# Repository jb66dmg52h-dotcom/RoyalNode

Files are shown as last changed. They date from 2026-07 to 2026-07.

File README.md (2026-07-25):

# RoyalNode / 2Watt Project

RoyalNode, also tracked as the 2Watt Project, is a solar-powered 915 MHz LoRa repeater carrier built around the Seeed Studio XIAO nRF52840 and EBYTE E22-900M33S high-power radio module.

> **Status:** Rev A KiCad schematic and PCB placement scaffold are active. The board is not fabrication ready.

## Locked architecture

- Standard Seeed Studio XIAO nRF52840, socketed
- EBYTE E22-900M33S radio module
- Protected 1S 3.6/3.7 V Li-ion/LiPo pack, 10-20 Ah class
- Board-mounted XT30 battery connector
- Board-mounted XT30 solar connector
- BQ25798 buck-boost charger with MPPT and power path
- Battery-mounted Semitec 103AT-2 NTC connected to BQ25798 TS network
- TPS61088 5 V boost rail for the E22
- Battery voltage and charger telemetry read directly from the BQ25798
- XIAO powered through its underside BAT and GND pads using a two-wire JST-GH lead
- LM66100 ideal diode between the main battery/system node and the XIAO BAT lead
- USB-C firmware updates through the XIAO
- USB-C battery charging through the BQ25798
- One external charge LED
- Optional MeshCore-supported BME680 environmental I2C port
- Direct controlled-impedance RF path from E22 ANT to board-edge SMA
- XIAO-controlled TPS61088 enable for radio power sequencing
- 4-layer controlled-impedance PCB

## Solar guidance

- 6 V class panel
- 20 W target for permanent deployment
- BQ25798 must be configured and validated against the selected panel's actual Vmp, Voc and Imp
- Installer must verify Vmp, Voc, Imp and cold-weather Voc

## Removed from Rev A

- MAX17048 fuel gauge and battery percentage estimation
- Power button
- eFuse
- Radio load switch
- Pogo pins
- SWD connector
- Multi-wire XIAO harness
- Extra LEDs beyond the charge LED
- Solar/USB-present telemetry
- Battery reverse-polarity circuit
- Radio-disable jumper
- Display, GPS and non-MeshCore accessory sensors
- Bench-test jumpers, simulated-temperature bypass networks and mode-selection test footprints

## Power summary

- Battery: protected 1S 3.6/3.7 V nominal, 4.20 V maximum, 10-20 Ah class
- Battery discharge capability: at least 5 A continuous, 8 A transient preferred
- Maximum charge current: 2 A
- Charge temperature sensing: battery-mounted 10 kOhm NTC; target policy suspends charging below 0 C and at/above 45 C
- Battery telemetry: BQ25798 battery voltage and charger-state measurements; no dedicated SOC fuel gauge in Rev A
- E22 rail: 5.0 V nominal
- TPS61088 rail design target: 2 A continuous
- TPS61088 inductor: Coilcraft XAL7030-222MEC, 2.2 uH
- BQ25798 inductor: Coilcraft XAL7070-222MEC, 2.2 uH
- E22 local bulk capacitance: 330-470 uF plus ceramics

## Canonical documents

- `docs/DESIGN_FREEZE_REV_A.md`
- `docs/CURRENT_STATUS_REV_A.md`
- `docs/WIRING_BLUEPRINT.md`
- `docs/ELECTRICAL_DESIGN_REV_A.md`
- `docs/LOCKED_COMPONENTS_REV_A.md`
- `docs/FINAL_POWER_CALCULATIONS_REV_A.md`
- `docs/SOLAR_DESIGN_GUIDE_REV_A.md`
- `docs/PCB_NET_CLASSES_REV_A.md`

Earlier concept documents are superseded where they conflict with the design-freeze document.

## Repository layout

```text
2Watt-Project/
├── docs/              Engineering specifications and calculations
├── hardware/          KiCad project, symbols, footprints and fabrication files
├── firmware/          Board support and hardware test firmware
├── bom/               Manufacturing and sourcing files
├── production/        Assembly and manufacturing outputs
└── test/              Bring-up procedures and measurements
```

## Local KiCad project

Open the Mac/KiCad project here:

```text
hardware/kicad/RoyalNode/RoyalNode.kicad_pro
```

Useful local checks:

```bash
make validate
make kicad-checks
```

## Remaining work

1. Resolve or formally accept the E22 footprint-library warning through the manufacturing review path.
2. Unblock the Molex edge-launch SMA footprint and final 50-ohm GCPW geometry.
3. Confirm XIAO socket orientation, XT30 polarity and connector mating clearance.
4. Refine power-stage placement from the generated ratsnest.
5. Route the PCB.
6. Run DRC, ERC, JLCPCB DFM and PCBA review.
7. Order Rev A prototypes for production validation.

## Safety and regulatory note

The radio hardware may be capable of approximately 33 dBm output. Deployed settings must comply with applicable conducted-power, antenna-gain, EIRP, bandwidth and certification requirements. The battery pack must include suitable internal protection, and deployment must respect the battery manufacturer's permitted charging-temperature range.

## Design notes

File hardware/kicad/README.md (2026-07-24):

# RoyalNode KiCad Workspace

This folder contains the Git-tracked KiCad design for RoyalNode Rev A.

Open the project file:

```text
hardware/kicad/RoyalNode/RoyalNode.kicad_pro
```

Current status:

- KiCad 10.0 project scaffold created.
- Root schematic is intentionally a capture placeholder.
- PCB file contains the Rev A board outline, placement zones, RF corridor, and keepout notes.
- Project-local symbols have been started in `RoyalNode/lib_symbols/RoyalNode.kicad_sym`.
- Footprint release is controlled by `RoyalNode/lib_footprints/FOOTPRINT_RELEASE_MATRIX_REV_A.md`.
- Schematic capture should follow `RoyalNode/SCHEMATIC_CAPTURE_SEED_REV_A.csv`.
- Footprints, schematic nets, and routed copper still need to be captured from `docs/DESIGN_FREEZE_REV_A.md` and `docs/NET_MAP_REV_A.md`.

Design source of truth:

- `docs/DESIGN_FREEZE_REV_A.md`
- `docs/REFERENCE_DESIGNATORS_REV_A.md`
- `docs/NET_MAP_REV_A.md`
- `docs/PIN_AUDIT_REV_A.md`
- `docs/RF_DESIGN_REV_A.md`
- `docs/FOOTPRINT_SOURCE_LINKS_REV_A.md`
- `bom/REV_A_LOCKED_CORE_BOM.csv`
- `bom/REV_A_LOCKED_PASSIVES.csv`

Validation:

```bash
python3 tools/validate_royalnode.py
```

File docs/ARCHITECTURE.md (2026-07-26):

# RoyalNode Rev A System Architecture

## Proposed block diagram

```text
6 V / 20 W solar panel
          |
  XT30, fuse, reverse protection,
  TVS and input filtering
          |
  BQ25798 1S solar/USB charger
          |
  1S 15 Ah protected Li-ion battery
          |
      XT30 + main fuse
          |
          +-------------------------------+
          |                               |
 TPS61088 5.0 V radio boost       low-noise MCU supply
          |                               |
 EBYTE E22-900M33S                Seeed XIAO nRF52840
          |                               |
 50-ohm PCB trace to SMA          optional 4-pin JST-GH
                                  BME680 environmental
```

## Major subsystems

### Solar and charger subsystem

RoyalNode uses a one-cell charger architecture around the BQ25798RQMR charger and power-path controller.

The locked Rev A charger is BQ25798RQMR configured for one Li-ion cell. It provides the charger, power-path behavior, I2C configuration, charger telemetry and input-source handling used by the current KiCad schematic.

For a 6 V nominal panel, firmware and charger configuration must be validated against the actual panel maximum-power voltage/current rather than the printed nominal voltage alone.

Initial charging target:

- 1S Li-ion charge voltage: 4.20 V
- maximum charge current: approximately 2.0–2.5 A
- panel maximum-power current: approximately 3.3 A
- battery NTC charge-temperature protection enabled

### Battery subsystem

Target pack: protected 1S 15 Ah lithium-ion pack with a pack-mounted NTC.

The pack no longer needs cell balancing because all parallel cells operate as one series group. It still requires:

- over-charge protection
- over-discharge protection
- over-current and short-circuit protection
- at least 5 A continuous discharge capability
- transient capability above 5 A
- a main fuse near the XT30 connection

At a 6 W radio load and approximately 85–90% boost efficiency, the battery may supply roughly 1.6 A at 4.2 V and approximately 2.2–2.6 A near the low end of the allowed battery range. Copper, fuse, protection FETs and wiring are sized with substantial margin.

### Radio power subsystem

TPS61088 remains the preferred converter. It is suitable for single-cell lithium input and provides the switch-current capability required to create a stiff 5.0 V radio rail.

Required design targets:

- input range: approximately 3.0–4.2 V
- output: 5.0 V
- continuous output design target: 3 A
- programmed soft start
- controlled enable from the XIAO
- low-ESR local bulk and ceramic capacitance at the EBYTE supply
- hardware protection against abnormal output over-voltage

No current-shunt footprints, dedicated test pads or measurement links are included.

### MCU subsystem

The Seeed XIAO nRF52840 remains socketed on Rev A. It handles the SPI radio interface, boost enable and radio sequencing, battery telemetry, optional environmental telemetry, fault logging and the MeshCore hardware abstraction layer.

The XIAO must not use its onboard battery charger as the system charger. The BQ25798 charger path is the controlled battery-charging path. Programming uses the XIAO USB-C port; recovery uses SWD pads or Tag-Connect.

### Battery telemetry

Rev A omits a dedicated MAX17048 fuel gauge. Battery voltage and charger state are read from the BQ25798 over I2C. Firmware may later add an ADC cross-check if needed, but it is not part of the current KiCad capture.

### Radio and RF subsystem

The EBYTE E22-900M33S contains an SX1262-family transceiver and external high-power RF front end. Integration requires validated control of reset, BUSY, DIO1, RXEN, TXEN or DIO2 RF-switch control, and DIO3 TCXO behavior.

The board-mounted SMA is connected to EBYTE ANT pin 21 through a short 50-ohm controlled-impedance grounded coplanar waveguide. The module's alternate U.FL/I-PEX path must not be used simultaneously.

## MeshCore telemetry architecture

### Required

- battery voltage or state of charge
- MCU internal temperature where supported

### Optional

- BME680 temperature, humidity and pressure over one 4-pin JST-GH I2C connector

### Omitted

- solar current telemetry
- radio current telemetry
- battery current telemetry
- external PA or regulator temperature telemetry
- fan sensing or control
- generic accessory ports
- GPS hardware for a fixed repeater

## Parts changed by the 2S-to-1S conversion

### Removed or replaced

- 2S charger configuration: replaced by 1S BQ25798 configuration
- 2S 15 Ah battery pack: replaced by protected 1S 15 Ah pack
- 2S BMS and balancing function: replaced by 1S protection circuit
- any 2S voltage-divider values: recalculated for 1S
- any 2S fuel-gauge choice: removed from Rev A
- 2S low-voltage firmware thresholds: replaced by 1S thresholds

### Retained

- TPS61088 radio boost converter
- 5.0 V / 3 A radio-rail target
- Seeed XIAO nRF52840
- EBYTE E22-900M33S
- XT30 battery and solar connectors
- optional BME680 JST-GH connector
- PCB-mounted edge-launch SMA
- four-layer PCB and two-ounce outer copper preference

### Recalculation required during schematic capture

- BQ25798 1S charger configuration
- BQ25798 input-current and charge-current limits
- BQ25798 input-selector MOSFET ratings and gate behavior
- BQ25798 inductor current and saturation rating
- TPS61088 inductor, current limit, compensation and thermal design
- battery fuse rating
- 1S protection MOSFET resistance and trip threshold
- low-battery firmware thresholds
- BQ25798 telemetry integration in firmware

## Connector architecture

- Battery: XT30
- Solar: XT30
- Optional environmental sensor: 4-pin JST-GH
- Antenna: PCB-mounted edge-launch SMA
- Programming: XIAO USB-C
- Recovery/debug: Tag-Connect or SWD pads
- Mounting: four M3 non-plated corner holes

## Design philosophy

Rev A is deployment-focused. It omits bench-only test points and current shunts. Necessary EBYTE configuration resistors may remain where required for signal-routing flexibility. The XIAO and EBYTE modules remain serviceable.

## Current open decisions

1. Select exact 6 V / 20 W panel and confirm its Vmp and Voc.
2. Complete BQ25798 charger configuration and component review.
3. Complete TPS61088 1S-to-5 V power-stage calculations.
4. Select exact protected 1S 15 Ah battery pack and NTC specification.
5. Select hardware radio-rail over-voltage protection.
6. Verify exact E22 footprint, antenna-path selection and RF pin mapping.
7. Implement MeshCore driver changes required for the external PA and RF switch.
8. Confirm BQ25798 battery/charger telemetry integration.
9. Confirm BME680 support in the selected MeshCore repeater build.
10. Finalize enclosure, vent and cable-gland selections.
11. Finalize legal transmit-power configuration for Canadian deployment.

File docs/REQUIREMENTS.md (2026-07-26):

# RoyalNode Rev A Requirements

## 1. Mission

RoyalNode Rev A is an engineering-validation platform for a rugged, solar-powered 915 MHz LoRa repeater using a Seeed XIAO nRF52840 and an EBYTE E22-900M33S radio module.

## 2. Functional requirements

- Operate as a continuously available LoRa repeater.
- Support the E22-900M33S SPI interface and external RF-control behavior.
- Support firmware-controlled radio power, reset and receive/transmit control.
- Expose only telemetry that can be reported through the MeshCore ecosystem.
- Permit safe reduced-power operation when battery charge or temperature is outside preferred limits.
- Do not include dedicated electrical test points, current-shunt footprints, removable measurement links or bench-only instrumentation hardware.

## 3. Power requirements

- Primary energy source: 6 V class, 20 W monocrystalline panel.
- Panel maximum-power current target: approximately 3.3 A or less.
- Panel open-circuit voltage must remain within the selected charger's absolute maximum input rating.
- Energy storage: protected 1S Li-ion battery pack, 15 Ah target.
- Battery operating range: approximately 3.0 V to 4.2 V.
- Battery pack must include over-current, over-charge, over-discharge and short-circuit protection.
- Cell balancing is not required for a 1S pack.
- The battery connection must be fused at the pack interface.
- Battery pack continuous discharge capability shall be at least 5 A, with higher transient capability preferred.
- Charging shall use a solar-compatible charger and power-path controller suitable for a 6 V panel and one Li-ion cell.
- Locked Rev A charger/controller: BQ25798RQMR configured for 1S Li-ion operation.
- Charging must be inhibited below the cell manufacturer's allowed temperature using a battery-mounted NTC.
- Radio rail: regulated 5.0 V, 3 A continuous design target, with short transient margin above 3 A.
- Preferred radio boost converter: TPS61088.
- MCU and sensing electronics should use a separate low-noise supply path.
- The design must tolerate repeated full-power transmit bursts without brownout or MCU reset.
- At full transmit power, design the 1S battery path for approximately 2.0–2.6 A normal peak draw and at least 5 A electrical capability.

## 4. Connector standard

### High-current power connectors

- Battery input: board-mounted XT30.
- Solar input: board-mounted XT30.
- XT30-equivalent locking connectors may be used only if they meet or exceed XT30 contact reliability, current capability and mechanical retention.
- PCB-mounted XT30 connectors are preferred where enclosure space permits.
- Panel-mounted XT30 connectors with short 16–18 AWG silicone-wire pigtails are acceptable.
- Solar and battery connector positions must be mechanically keyed and clearly labeled to prevent cross-connection.

### Low-current signal connectors

- All JST-style connectors shall use the JST-GH family, 1.25 mm pitch.
- Do not mix JST-PH, JST-XH, JST-SH or JST-ZH families on the board.
- Use JST-GH for all low-current removable harnesses.
- J3 is allowed as an internal XIAO underside BAT/GND power harness.
- J4 is allowed as the required battery-mounted NTC charge-safety harness.
- The only optional deployed telemetry connector is the MeshCore-supported environmental I2C module connector.
- No fan, generic analog sensor, general-purpose UART, or six-pin debug/programming JST connector shall be fitted.
- Programming shall use the XIAO USB-C connector.
- Recovery/debug shall use a compact Tag-Connect or exposed SWD pad footprint.
- Every JST-GH connector must have pin 1 and signal names marked on silkscreen.
- JST-GH connections must remain inside the weather-sealed enclosure unless a sealed bulkhead transition is used.

## 5. MeshCore telemetry requirements

Only the following telemetry categories are approved for Rev A:

1. **Battery voltage / state of charge**
   - Required.
   - Reported through MeshCore base telemetry.
   - Preferred Rev A source: BQ25798 battery-voltage and charger telemetry over I2C.
   - A dedicated MAX17048 fuel-gauge footprint is omitted from Rev A.

2. **MCU temperature**
   - Required where supported by the XIAO nRF52840 board definition.
   - Uses the MCU's internal temperature measurement.
   - Treated as enclosure/electronics temperature, not precise outdoor ambient temperature.

3. **Environmental telemetry**
   - Optional.
   - Temperature, humidity and pressure only.
   - Preferred sensor: BME680 where supported by MeshCore.
   - Connection: one 4-pin JST-GH I2C port with 3.3 V, GND, SDA and SCL.

4. **GPS/location telemetry**
   - Omitted by default for a fixed repeater.
   - Fixed node position should be configured in firmware.

The following shall not be included as deployed telemetry sensors unless future MeshCore support is confirmed:

- solar current sensor
- radio current sensor
- battery current sensor
- external PA temperature sensor
- regulator temperature sensor
- fan tachometer
- generic analog sensors
- arbitrary accessory sensors

## 6. Environmental requirements

- Intended for outdoor use in Canada.
- Electronics enclosure target: IP65 minimum, IP67 preferred.
- Use a pressure-equalizing breathable vent to reduce condensation.
- Battery charging temperature must be monitored by the charger or battery pack for safety.
- Materials, connectors and cabling must be suitable for UV exposure or protected inside the enclosure.

## 7. Electrical protection

- Reverse-polarity protection on solar and battery inputs.
- Input fusing on solar and battery paths.
- TVS protection on the solar input.
- Hardware over-voltage protection on the 5 V radio rail.
- Hardware or firmware transmit timeout.
- Brownout supervision and watchdog recovery.
- No current-shunt footprints, zero-ohm measurement links or dedicated probe pads shall be included.
- The 1S protection stage must tolerate radio transmit surges without nuisance disconnects.

## 8. Mechanical requirements

- Socketed XIAO nRF52840 on Rev A.
- Serviceable EBYTE radio module.
- XT30 battery and solar connectors.
- No low-current connector except the internal JST-GH XIAO power harness, internal JST-GH battery-NTC safety harness and optional 4-pin JST-GH environmental-sensor port.
- Solar wiring sized for approximately 3.3 A continuous current with low voltage drop.
- Battery wiring sized for at least 5 A continuous capability.
- PCB-mounted edge-launch SMA connected to EBYTE ANT pin 21 through a short 50-ohm controlled-impedance path.
- Four M3 non-plated corner mounting holes, 3.2 mm drill, with mechanical clearance for screw heads/standoffs.
- Board layout must separate switching power circuitry from the radio module and MCU antenna.

## 9. PCB requirements

- Four-layer PCB.
- Continuous ground plane.
- Two-ounce outer copper preferred.
- ENIG finish preferred.
- Wide copper pours for battery, solar-input and radio-current paths.
- No dedicated test points, measurement loops or shunt footprints.
- Configuration jumpers are allowed only where electrically necessary for uncertain EBYTE control routing.
- DRC and ERC must pass before fabrication release.

## 10. Firmware requirements

- Safe startup sequencing for the radio boost supply.
- EBYTE-specific TCXO and RF-switch configuration.
- Low-battery power reduction and shutdown thresholds suited to a 1S pack.
- Suggested initial thresholds: reduce power below 3.5 V, disable full-power transmit below 3.3 V, shut radio boost down near 3.1–3.2 V.
- Charge-temperature lockout support.
- MeshCore battery telemetry.
- MeshCore MCU-temperature telemetry where supported.
- Optional MeshCore environmental telemetry using the supported sensor interface.
- Daily airtime and fault counters.
- Recoverable watchdog behavior.
- Bench-test firmware independent of MeshCore.

## 11. Regulatory requirement

Hardware capability does not imply legal operating permission. Deployed firmware settings, antenna gain, cable loss, bandwidth and duty cycle must be reviewed against current Canadian 902–928 MHz requirements before field operation.

## 12. Rev A acceptance criteria

Rev A is successful when:

1. The charger safely charges the selected 1S pack from a 6 V / 20 W panel.
2. The charger maintains its programmed panel-voltage operating point under varying sunlight.
3. The TPS61088 5 V radio rail holds regulation during repeated full-power load steps from 4.2 V down to the minimum allowed battery voltage.
4. The 1S protection circuit does not nuisance-trip during radio transmission.
5. The XIAO remains stable during radio transmission.
6. The radio initializes, receives and transmits through test firmware.
7. Battery voltage or state of charge appears correctly through MeshCore telemetry.
8. MCU temperature appears through MeshCore where supported.
9. Optional BME680 temperature, humidity and pressure appear through MeshCore when fitted.
10. XT30 and any fitted JST-GH connector pass continuity, retention and polarity checks.
11. The board survives multi-day outdoor pilot testing without unexplained resets.

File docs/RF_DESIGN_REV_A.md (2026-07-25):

# RoyalNode Rev A RF Design

## Status

RF architecture is frozen for schematic capture. JLCPCB is the locked Rev A PCB fabricator. Transmission-line dimensions are to be generated from the selected JLCPCB production stack-up rather than generic FR-4 assumptions.

## Production PCB stack-up

- Fabricator: JLCPCB
- Layer count: 4
- Finished board thickness: 1.6 mm
- Outer copper target: 1 oz
- Inner copper target: 0.5 oz
- Preferred JLCPCB stack-up: JLC04161H-3313
- L1: components, critical power and RF
- L2: uninterrupted ground plane
- L3: power distribution and low-speed signals
- L4: low-speed signals and ground copper
- The JLCPCB impedance calculator/current production stack-up data are authoritative for final 50-ohm geometry.
- If JLCPCB changes or withdraws this stack-up before fabrication, the RF geometry must be recalculated against the actual replacement stack-up before Gerber release.

## Radio interface

- Radio module: EBYTE E22-900M33S.
- E22 pin 21 ANT is the module's nominal 50-ohm antenna interface.
- E22 pins 20 and 22 are the adjacent RF ground pins and must connect into the RF ground region with very short paths and nearby ground vias.
- Carrier does not add an RF matching network between the module ANT pin and the SMA.

## Locked RF schematic

```text
E22 pin 20 GND ---- local RF ground

E22 pin 21 ANT ===== 50-ohm grounded coplanar waveguide ===== SMA center

E22 pin 22 GND ---- local RF ground
```

The ANT-to-SMA path contains no series resistor, no pi matching/tuning network and no series DC-block capacitor.

## Transmission line

- Structure: grounded coplanar waveguide (GCPW/CPWG) on L1.
- Nominal impedance: 50 ohms.
- Reference: continuous Layer-2 ground plane directly beneath the complete RF route.
- Trace width and coplanar gap are calculated from JLCPCB's JLC04161H-3313 production parameters, including dielectric thickness, dielectric constant and finished copper thickness.
- Do not substitute a generic online microstrip dimension.
- Fabrication drawing shall call out controlled impedance and JLCPCB's stated production tolerance.
- The stack-up source data and RF release checklist are tracked in `docs/RF_STACKUP_PLAN_REV_A.md`.

## Routing rules

- Keep the route as short and straight as practical.
- Avoid 90-degree corners; use a straight route where placement permits and gentle/mitered direction changes only when necessary.
- Do not route digital, charger or boost-converter signals beneath the RF route.
- Do not place Layer-2 plane splits, slots or voids beneath the RF route.
- Keep BQ25798 and TPS61088 high-di/dt loops and switching nodes away from the E22 ANT/SMA end of the board.
- Keep SPI, I2C and radio-control traces from running parallel beside the RF route for unnecessary distance.

## Grounding and via fence

- Maintain grounded coplanar copper on both sides of the RF trace where the SMA launch and board geometry permit.
- Stitch the coplanar ground to Layer 2 with a ground-via fence.
- Target RF-region ground-via pitch: no greater than 1.5 mm where practical.
- Add dense ground stitching at the E22 ANT transition and around the SMA ground tabs/launch.
- The SMA shell/ground tabs connect directly into the RF ground structure and Layer-2 ground plane through short, low-inductance paths.

## SMA connector

- Connector class: standard-polarity 50-ohm SMA female, board-edge/edge-launch style.
- Exact manufacturer part remains dependent on its verified 1.6 mm board recommendation and launch geometry.
- Do not lock an SMA footprint until its manufacturer drawing is checked against the selected 1.6 mm JLCPCB stack-up and controlled-impedance launch.

## RF power

- E22-900M33S maximum module output is approximately 33 dBm class.
- A properly designed 50-ohm PCB transmission line and normal SMA connector are not power-limited by this approximately 2 W RF level; the controlling concerns are impedance discontinuity, insertion loss, grounding and EMI.

## ESD protection

No shunt RF ESD/TVS device is locked into Rev A at this stage.

Reason: an antenna-line protection diode must be verified not only for capacitance and ESD rating but also for acceptable insertion loss, nonlinear/harmonic behavior and operation with the E22's approximately 33 dBm RF output. Parts such as Nexperia PESD24VF1BBSF and Semtech RF-oriented low-capacitance TVS families demonstrate that suitable antenna-protection devices exist, but the presently reviewed manufacturer data do not provide enough explicit 915 MHz / 2 W continuous-RF validation to freeze one without assumption.

Therefore Rev A does not insert an unverified TVS into the RF path. This is a deliberate production-design choice rather than an unpopulated test option.

## Schematic exclusions

The following are intentionally absent from Rev A:

- 0-ohm RF series link
- pi tuning/matching footprint
- external module matching components
- series RF DC-block capacitor
- RF test connector
- RF jumper
- unverified antenna-line TVS/ESD diode

## PCB release dependency

Before PCB routing is considered final:

1. Verify JLC04161H-3313 remains available for the production order.
2. Select the exact SMA connector for the 1.6 mm board and mechanical layout.
3. Generate the 50-ohm GCPW width/gap using JLCPCB's current impedance calculator/production parameters.
4. Confirm the connector launch geometry against the connector manufacturer's recommended footprint.
5. Apply the RF keepout and via-fence rules above.

`RF_915` remains intentionally unrouted until the RF stack-up plan's open release items are closed.

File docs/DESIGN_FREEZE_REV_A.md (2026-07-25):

# 2Watt Project Rev A Design Freeze

## Status

Rev A architecture is frozen and the KiCad schematic/placement scaffold is active. This document is one of the primary sources of truth. Earlier concept notes are superseded where they conflict with this file or `docs/CURRENT_STATUS_REV_A.md`.

## Locked functions

- MeshCore-compatible repeater carrier
- Seeed Studio XIAO nRF52840, standard version
- EBYTE E22-900M33S high-power 915 MHz radio module
- Protected 1S 3.6/3.7 V Li-ion/LiPo pack, 10-20 Ah class
- Board-mounted XT30 battery input
- Board-mounted XT30 solar input
- USB-C firmware updates through the XIAO
- USB-C charging through the main charger
- 6 V class solar panel support
- 20 W panel target for permanent deployment
- Battery voltage and charger telemetry through BQ25798
- Battery-mounted NTC temperature sensing for charge protection
- One external charge LED
- Optional MeshCore-supported BME680 environmental I2C port
- Direct 50-ohm grounded-coplanar RF path from E22 ANT to board-edge SMA
- Automatic startup when battery is connected
- Factory assembly for all pick-and-place-compatible parts

## Removed functions

- Dedicated fuel gauge / MAX17048
- Battery state-of-charge percentage estimation
- Power button
- eFuse
- Radio load switch
- Pogo pins
- SWD connector
- Multi-wire XIAO harness
- Full/fault/system LEDs on the carrier
- Solar-present telemetry
- USB-present telemetry
- Battery reverse-polarity protection
- Radio-disable jumper
- Display, GPS and non-MeshCore accessory sensors
- Bench-test configuration jumpers or bypass networks
- RF 0-ohm series link
- RF pi matching/tuning network
- External RF DC-block capacitor
- RF test connector or jumper

## Locked power tree

```text
6 V / 20 W class solar panel
  -> board-mounted XT30
  -> 5 A-class fused input protection chain
  -> BQ25798 solar input

XIAO USB-C VBUS
  -> protected current-limited path
  -> BQ25798 USB input

Protected 1S Li-ion/LiPo
  <-> board-mounted XT30
  <-> BQ25798 BAT / power path

BQ25798 SYS
  -> TPS61088
  -> regulated 5.0 V
  -> E22-900M33S directly

Protected battery/system node
  -> LM66100 ideal diode
  -> board-mounted 2-pin JST-GH
  -> short two-wire harness
  -> XIAO BAT and GND underside pads
```

The XIAO 5V/VBUS pad is not driven by the carrier board. The XIAO BAT pad is used for the two-wire carrier power connection. LM66100 blocks reverse current from the XIAO onboard charger into the main battery rail.

## Battery temperature protection

- Real battery-mounted NTC is required; TS is not bypassed in normal operation.
- Thermistor: Semitec 103AT-2, 10 kOhm NTC at 25 C.
- BQ25798 TS network: 5.23 kOhm from REGN to TS, 30.1 kOhm from TS to the NTC node, thermistor from NTC node to GND.
- Charging policy target for generic 4.2 V 1S Li-ion/LiPo packs: suspend charging below 0 C and at/above 45 C.
- No bench-test divider, TS bypass jumper, or alternate simulated-temperature network is included.

## Locked interfaces

### Final XIAO GPIO map

| XIAO pin | nRF52840 GPIO | Function |
|---|---|---|
| D0 | P0.02 | E22 NRST |
| D1 | P0.03 | E22 DIO1 |
| D2 | P0.28 | E22 BUSY |
| D3 | P0.29 | E22 NSS / SPI chip select |
| D4 | P0.04 | I2C SDA, BQ25798 |
| D5 | P0.05 | I2C SCL, BQ25798 |
| D6 | P1.11 | E22 RXEN, active high |
| D7 | P1.12 | TPS61088 EN |
| D8 | P1.13 | E22 SPI SCK |
| D9 | P1.14 | E22 SPI MISO |
| D10 | P1.15 | E22 SPI MOSI |

All eleven exposed XIAO GPIO pins are allocated.

### E22 RF switch control

- E22 DIO2 connects directly to E22 TXEN.
- TXEN is therefore controlled by the SX1262 DIO2 RF-switch function and does not consume a XIAO GPIO.
- E22 RXEN remains under XIAO control on D6.
- Firmware must enable the SX1262 DIO2 RF-switch control function and must not also configure a separate MCU TXEN pin.

### BQ25798 interrupt handling

- BQ25798 INT does not consume a XIAO GPIO.
- Charger status and fault registers are polled over I2C.
- INT retains the datasheet-recommended 10 kOhm pull-up to the 3.3 V logic rail but is not routed to the MCU.

### XIAO power connector

- 2-pin JST-GH, 1.25 mm pitch
- Pin 1: protected 1S supply after LM66100
- Pin 2: GND
- XIAO-side wires solder directly to underside BAT and GND pads
- XIAO remains socketed on its edge pins

## Locked RF architecture

- E22 pin 21 ANT is treated as a 50-ohm module interface.
- E22 pin 21 ANT routes directly to the SMA center contact using a 50-ohm grounded coplanar waveguide.
- E22 pins 20 and 22 are local RF ground pins and connect into the RF ground structure with short paths and nearby vias.
- Layer 2 remains an uninterrupted ground reference beneath the entire ANT-to-SMA route.
- No matching network, 0-ohm link or series DC-block capacitor is inserted into the RF path.
- Ground-via fence target is no greater than 1.5 mm pitch where practical, with dense stitching at the E22 transition and SMA launch.
- Route is kept as short and straight as practical; avoid 90-degree RF corners.
- Exact RF trace width and coplanar gap are calculated only after the production 4-layer stack-up is selected.
- SMA class: standard-polarity 50-ohm female edge-launch. Exact part waits for final board thickness and mechanical layout.
- No unverified shunt RF ESD/TVS device is fitted in Rev A. Any future RF protection component must have explicit suitability for the antenna-line RF conditions rather than being selected only by capacitance and ESD rating.
- Detailed RF rules are captured in `docs/RF_DESIGN_REV_A.md`.

## Locked electrical targets

- Battery: protected 1S 3.6/3.7 V nominal, 4.20 V maximum, 10-20 Ah class
- Battery discharge: at least 5 A continuous; 8 A transient preferred
- Battery charge permission: at least 2 A
- Maximum charge current: 2.0 A
- Solar input fuse: 5 A class, currently Littelfuse 0483005.DR candidate; verify time-current behavior against selected panel Isc
- Battery telemetry: BQ25798 voltage/charger telemetry only; no dedicated SOC gauge
- E22 rail: 5.0 V nominal
- 5 V rail: 2 A continuous design target
- TPS61088 inductor: Coilcraft XAL7030-222MEC, 2.2 uH
- TPS61088 RFREQ: 330 kOhm from FSW to SW
- TPS61088 ILIM: 100 kOhm to AGND
- TPS61088 feedback: 176 kOhm top / 56.0 kOhm bottom, 0.1%
- TPS61088 compensation: 20.0 kOhm and 4.7 nF
- TPS61088 soft-start: 47 nF
- TPS61088 VCC bypass: 2.2 uF
- TPS61088 BOOT capacitor: 100 nF from BOOT to SW
- TPS61088 MODE: floating for PFM/light-load efficiency
- TPS61088 EN: XIAO D7 controlled; 100 kOhm pulldown keeps the 5 V radio rail off during MCU startup
- TPS61088 input capacitance: 2 x 22 uF plus 100 nF local VIN bypass
- TPS61088 output capacitance: 2 x 47 uF, 10 V ceramic; exact manufacturer part must be verified for effective capacitance at 5 V bias
- BQ25798 switching frequency: 750 kHz
- BQ25798 inductor: Coilcraft XAL7070-222MEC, 2.2 uH
- E22 local bulk capacitance: 330-470 uF plus ceramics

## Locked board assumptions

- 4-layer controlled-impedance PCB
- ENIG finish preferred
- Continuous ground plane directly below RF path
- TPS61088 and charger switching loops kept away from E22/SMA
- TPS61088 input/output capacitors, BOOT capacitor and inductor placed immediately around the converter to minimize high-di/dt loops
- SW copper kept as small as practical
- XT30 and SMA footprints require mechanical support
- Board-only design; enclosure design is outside Rev A scope

## Remaining work inside KiCad

- Resolve or formally accept the E22 footprint-library warning through manufacturing review
- Unblock the Molex edge-launch SMA footprint
- Obtain fabricator stack-up and calculate 50-ohm geometry
- Confirm XIAO socket orientation and XT30 polarity/mating clearance
- Refine power-stage placement from the generated ratsnest
- Route power and RF
- Run DRC and manufacturing review

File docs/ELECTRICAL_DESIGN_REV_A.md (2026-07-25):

# 2Watt Project Electrical Design, Rev A

## Status

Locked for KiCad schematic capture. Battery physical packaging and enclosure design are outside this scope.

## System architecture

```text
SOLAR XT30
  -> 5 A-class fused input protection chain
  -> BQ25798 solar input (VAC1 / ACDRV1, primary port)

XIAO USB-C VBUS
  -> BQ25798 USB input (VAC2 / ACDRV2, secondary port)

PROTECTED 1S LI-ION/LIPO
  <-> BATTERY XT30
  <-> BQ25798 BAT/SYS power path

BQ25798 SYS
  -> TPS61088 boost
  -> 5.0 V
  -> E22-900M33S directly

PROTECTED BATTERY/SYSTEM NODE
  -> LM66100 ideal diode
  -> 2-pin JST-GH
  -> XIAO BAT and GND underside pads
```

## 1. Solar input

The LTC4365-based solar protection architecture is authoritative. Final KiCad capture must use the current locked protection chain rather than the older P-FET/TVS-only concept.

Solar is assigned to BQ25798 port 1 (`VAC1` / `ACDRV1`). TI defines port 1 as the higher-priority port when both inputs appear simultaneously. Firmware must also explicitly prefer port 1 when solar becomes valid after USB is already active, because in dual-input mode the BQ25798 otherwise keeps the first-present valid source until host intervention or until that source becomes invalid.

USB-C is assigned to BQ25798 port 2 (`VAC2` / `ACDRV2`).

## 2. Main charger and power path

### Charger

- U1: TI BQ25798RQMR
- cell count: 1S
- battery class: protected 3.6/3.7 V nominal Li-ion/LiPo, 4.20 V maximum
- maximum programmed charge current: 2.0 A
- switching frequency: 750 kHz
- inductor: Coilcraft XAL7070-222MEC, 2.2 uH

### Startup configuration

- PROG: 4.7 kOhm, 1%, to GND for 1S / 750 kHz POR configuration
- /CE: tied low
- D+ and D- on BQ25798: no connection
- SDA/SCL: 3.3 V I2C bus to XIAO D4/D5
- charger status: one hardware charge LED
- battery voltage, charger telemetry and fault state: polled from BQ25798 over I2C
- watchdog: disabled by host firmware
- ADC: enabled by host firmware
- MPPT: enabled and restored by host firmware when solar charging is active
- Rev A has no dedicated fuel gauge and does not provide a ModelGauge-style battery percentage estimate

### Dual input

- VAC1 pin 9: solar protected-source sense node
- ACDRV1 pin 11: solar ACFET1/RBFET1 gates
- VAC2 pin 8: USB-C source-sense node
- ACDRV2 pin 10: USB ACFET2/RBFET2 gates
- each input uses its own back-to-back N-channel MOSFET pair
- the two paths meet only at common VBUS after their respective selector pair
- sources must not backfeed one another

### Battery temperature sensing

- Physical battery-mounted NTC required
- NTC: Semitec 103AT-2, 10 kOhm at 25 C
- RTOP: 5.23 kOhm from REGN to TS
- RBOT: 30.1 kOhm from TS to the NTC node
- NTC from NTC node to GND
- TS is not bypassed in normal operation
- Charge policy target: suspend below 0 C and at/above 45 C for generic 4.2 V 1S Li-ion/LiPo packs
- No bench-test jumper, simulated-temperature divider or alternate TS bypass network
- temperature connector: JST-GH SM02B-GHS-TB board header + GHR-02V-S cable housing

### Locked BQ25798 supporting parts

- VBUS: 2 x 10 uF plus 100 nF
- PMID: 3 x 10 uF plus 100 nF
- SYS: 5 x 10 uF plus 100 nF
- BAT: 2 x 10 uF
- REGN: 4.7 uF
- BTST1: 47 nF
- BTST2: 47 nF
- SDRV: 1 nF to GND
- BATP: 100 Ohm series resistor on a dedicated Kelvin trace from battery positive
- ILIM_HIZ: tied to REGN
- INT: 10 kOhm pull-up to 3.3 V; not routed to MCU
- QON: no external connection; internal pull-up retained

Exact manufacturer parts are listed in `docs/LOCKED_COMPONENTS_REV_A.md` and `docs/RESISTOR_BOM_REV_A.md`.

## 3. Battery interface

- Board-mounted AMASS XT30PW-M power connector
- protected 1S 3.6/3.7 V nominal Li-ion/LiPo pack
- target capacity: 10-20 Ah class
- maximum voltage: 4.20 V
- design minimum system input: 2.7-3.0 V region, subject to battery protection cutoff
- discharge capability: at least 5 A continuous, 8 A transient preferred
- permitted charge current: at least 2 A
- battery-mounted Semitec 103AT-2 NTC required
- dedicated Molex Pico-Lock 2-pin temperature connection
- no carrier battery reverse-polarity protection

## 4. XIAO power path

### Locked connection

The carrier does not drive the XIAO 5V/VBUS pin.

- U2: TI LM66100DCKR ideal diode
- pin 1 VIN: protected battery/system node
- pin 2 GND: ground
- pin 3 CE: **connect to VOUT** for always-on reverse-current blocking
- pin 4 NC: no connection
- pin 5 ST: **connect to GND** because status is unused
- pin 6 VOUT: board-mounted JST-GH SM02B-GHS-TB(LF)(SN) positive pin
- cable housing: JST GHR-02V-S
- wire 1: positive to XIAO BAT underside pad
- wire 2: ground to XIAO GND underside pad
- 1 uF input capacitor
- 1 uF output capacitor

### LM66100 audit correction

Earlier notes stated `CE tied high` and `ST not connected`. Those instructions are superseded. TI specifies that CE can be connected to VOUT for always-on reverse-current blocking and must not float; TI also specifies connecting ST to GND when status is unused. Rev A therefore uses **CE -> VOUT** and **ST -> GND**.

The LM66100 blocks reverse current from the XIAO onboard charger into the main battery rail while adding very little forward voltage drop.

### Mechanical arrangement

- XIAO edge pins plug into two 1x7 socket headers
- short flexible power wires are soldered to XIAO BAT and GND underside pads
- disconnect the 2-pin JST before removing the XIAO
- no pogo contacts, SWD connector or multi-wire harness

## 5. TPS61088 5 V rail

### Production-locked parts and values

- U3: TI TPS61088RHLR
- input: BQ25798 SYS / 1S system rail, 2.7-4.2 V operating design range
- output target: approximately 5.0 V nominal
- continuous target: 2 A
- inductor: Coilcraft XAL7030-222MEC, 2.2 uH
- feedback divider: 176 kOhm top / 56.0 kOhm bottom, 0.1%
- frequency resistor: 330 kOhm from FSW to SW
- current-limit resistor: 100 kOhm to AGND
- compensation: 20.0 kOhm and 4.7 nF
- soft-start capacitor: 47 nF
- VCC bypass: 2.2 uF
- BOOT capacitor: 100 nF from BOOT to SW
- MODE: floating for PFM/light-load efficiency
- EN: XIAO D7 with 100 kOhm pulldown so radio 5 V is off during MCU startup
- TPS61088 package NC pins 11/12 connect to ground plane for thermal dissipation per TI
- exposed PGND thermal pad is symbol/footprint pad 21 and must connect to power ground with thermal vias
- no PFM/PWM selection jumper or bench-test configuration footprint

### Input capacitors

- 2 x Murata GRM31CZ71C226ME15L, 22 uF, 16 V, X7R, 1206
- 100 nF local VIN bypass placed immediately at the IC

### Output and E22 capacitors

Near TPS61088:

- 2 x TDK C3225X5R1A476MT000E, 47 uF, 10 V, X5R, 1210

Near E22:

- 2 x 22 uF / 16 V X7R
- 1 uF / 16 V X7R
- multiple 100 nF ceramics
- Panasonic 10SVPC330M, 330 uF / 10 V polymer, 19 mOhm ESR

### TPS61088 layout rules

- inductor immediately adjacent to converter
- BOOT capacitor immediately adjacent to BOOT/SW pins
- input and output capacitors immediately adjacent to their power/ground pins
- smallest practical SW copper area
- solid ground plane directly below converter area
- keep complete boost switching block away from E22 RF feed and SMA route

## 6. E22 interface

- E22 VCC pins 9/10 connected directly to regulated 5 V
- logic interface is 3.3 V from XIAO; do not use 5 V logic
- no load switch and no eFuse
- NRST, BUSY and DIO1 route directly to assigned XIAO pins
- E22 DIO2 pin 8 connects directly to E22 TXEN pin 7
- TXEN is active high and is driven by SX1262 DIO2 RF-switch function, not by a XIAO GPIO
- RXEN pin 6 is active high and controlled by XIAO D6
- firmware must enable SX1262 DIO2 RF-switch function and must not define a separate MCU TXEN pin
- current EBYTE pin documentation does not mandate an external RXEN/TXEN pull-down value; no such resistor is to be invented without a documented need

### Final XIAO GPIO map

| XIAO pin | nRF52840 GPIO | Function |
|---|---|---|
| D0 | P0.02 | E22 NRST pin 15 |
| D1 | P0.03 | E22 DIO1 pin 13 |
| D2 | P0.28 | E22 BUSY pin 14 |
| D3 | P0.29 | E22 NSS pin 19 |
| D4 | P0.04 | BQ25798 SDA pin 15 |
| D5 | P0.05 | BQ25798 SCL pin 14 |
| D6 | P1.11 | E22 RXEN pin 6 |
| D7 | P1.12 | TPS61088 EN pin 2 |
| D8 | P1.13 | E22 SCK pin 18 |
| D9 | P1.14 | E22 MISO pin 16 |
| D10 | P1.15 | E22 MOSI pin 17 |

All eleven exposed XIAO GPIOs are allocated. BQ25798 INT is not routed to XIAO; charger status/faults are polled over I2C.

### MeshCore/RadioLib integration requirements

The custom RoyalNode variant must use XIAO D8/D9/D10 for SPI, D3 as chip-select, D0 as reset, D2 as BUSY, D1 as DIO1, D6 as RXEN, and enable SX1262 DIO2 RF-switch function for TXEN. TPS61088 D7 enable is handled by RoyalNode board startup/power-management code before radio initialization.

## 7. Battery telemetry

Rev A does not include a dedicated fuel gauge. The BQ25798 ADC and status registers are the sole carrier-board source of battery and charger telemetry.

Firmware may report:

- battery voltage
- battery charge/discharge current when the relevant ADC is enabled
- charger state
- VBUS/VAC input measurements
- charger fault/status information
- TS percentage and charger die temperature if useful

Rev A does not claim an accurate battery state-of-charge percentage. Any UI battery indication derived only from voltage must be identified as an estimate rather than fuel-gauge SOC.

## 8. Charge LED

- one external red charge/status LED only
- LED: Everlight 19-217/R6C-AL1M2VY/3T, 0603
- BQ25798 STAT drives LED directly using open-drain output; no buffer transistor
- topology: 3.3 V -> LED -> 2.2 kOhm -> STAT
- nominal current around 0.6 mA
- charging: LED on
- charge complete / charging disabled / battery-only: LED off
- fault/suspend indication follows BQ25798 STAT blink behavior
- no full, fault or carrier system LEDs

## 9. RF path

- E22 pin 21 ANT to Molex 0732511150 board-edge SMA through short 50-ohm grounded coplanar waveguide
- E22 pins 20/22 are immediate local RF grounds
- solid Layer-2 ground reference directly below
- ground-via fence along route
- no digital or switching-power route crossing RF keepout
- no 0-ohm link, pi network, DC-block capacitor, test connector or unverified RF TVS
- E22 ANT side faces the SMA edge and is placed as close as practical to the connector

## 10. PCB stack-up

- fabricator: JLCPCB
- 4 layers
- 1.6 mm finished thickness
- preferred stack-up: JLC04161H-3313
- outer copper 1 oz target; inner copper 0.5 oz target

Layer intent:

1. Top: components, RF and critical power loops
2. Inner 1: uninterrupted ground plane
3. Inner 2: power distribution and low-speed signals
4. Bottom: low-speed routing and ground copper

Keep BQ25798 and TPS61088 hot loops compact. Place the RF launch at the opposite/quiet board edge and compress the board outline only after real footprints are loaded.

## 11. Automatic startup

There is no power button. Connecting the protected battery powers the XIAO through LM66100. The XIAO intentionally enables the TPS61088 radio rail on D7 after board initialization. The battery XT30 is the master disconnect.

## 12. KiCad entry criteria

Before electrical capture is considered ready:

- use `docs/PIN_AUDIT_REV_A.md` as pin-number authority
- verify exact custom footprints against manufacturer mechanical drawings
- verify XIAO socket/header engagement
- produce final net-by-net map
- run repository contradiction search

After schematic capture:

- run ERC and schematic compatibility audit
- reproduce manufacturer reference-layout constraints
- confirm JLC production stack and controlled-impedance geometry before PCB routing release

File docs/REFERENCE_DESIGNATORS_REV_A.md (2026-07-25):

# RoyalNode Rev A Reference Designators

## Status

This file defines the reference-designator scheme for KiCad schematic capture. It resolves earlier documentation drift where some preliminary tables reused `U1` for different assemblies.

Use this file for new KiCad work.

## Modules

| Ref | Part | Function |
|---|---|---|
| MOD1 | Seeed Studio XIAO nRF52840 | Socketed MCU module |
| MOD2 | EBYTE E22-900M33S | High-power LoRa radio module |

## ICs

| Ref | Part | Function |
|---|---|---|
| U1 | BQ25798RQMR | Solar/USB charger and power path |
| U2 | LM66100DCKR | XIAO reverse-current blocker |
| U3 | TPS61088RHLR | 1S-to-5 V radio boost converter |
| U4 | LTC4365ITS8-1#TRMPBF | Solar input UV/OV/reverse protection controller |

## MOSFETs

| Ref | Part | Function |
|---|---|---|
| Q1 | ISA170170N04LMDSXTMA1 | LTC4365-controlled solar protection back-to-back MOSFET pair |
| Q2 | ISA170170N04LMDSXTMA1 | BQ25798 solar input selector MOSFET pair |
| Q3 | ISA170170N04LMDSXTMA1 | BQ25798 USB input selector MOSFET pair |

## Connectors

| Ref | Part/class | Function |
|---|---|---|
| J1 | AMASS XT30PW-M | Solar input |
| J2 | AMASS XT30PW-M | Battery input |
| J3 | JST-GH SM02B-GHS-TB(LF)(SN) | XIAO battery harness output |
| J4 | JST-GH SM02B-GHS-TB(LF)(SN) | Battery NTC input |
| J5 | Molex 0732511150 | Edge-launch SMA RF output |
| J6 | JST-GH SM04B-GHS-TB(LF)(SN) | Optional BME680/environmental I2C input |

## Magnetics

| Ref | Part | Function |
|---|---|---|
| L1 | Coilcraft XAL7070-222MEC | BQ25798 charger inductor |
| L2 | Coilcraft XAL7030-222MEC | TPS61088 boost inductor |

## Protection and Indicators

| Ref | Part/class | Function |
|---|---|---|
| F1 | Littelfuse 0483005.DR | Solar input fuse |
| D1 | Low-current red LED | BQ25798 charge status |

## Passive Numbering Blocks

Use these blocks during schematic capture:

| Range | Subsystem |
|---|---|
| R100-C199 | Solar input protection |
| R200-C299 | BQ25798 charger |
| R300-C399 | Battery and XIAO supply path |
| R400-C499 | TPS61088 5 V boost |
| R500-C599 | E22 radio and RF support |
| R600-C699 | XIAO/module interface |

Do not create reference designators for test points, shunts, or bench-only configuration links; Rev A intentionally excludes them.

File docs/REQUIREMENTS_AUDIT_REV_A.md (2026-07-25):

# 2Watt Project Requirements Audit, Rev A

## Status

Requirements frozen for KiCad schematic capture. `DESIGN_FREEZE_REV_A.md` is the primary source of truth.

## Fixed product requirements

### Radio and firmware

- EBYTE E22-900M33S radio module
- Standard Seeed Studio XIAO nRF52840 controller
- MeshCore repeater target
- Native USB-C firmware updates through the XIAO
- Radio signals: NSS, SCK, MOSI, MISO, BUSY, DIO1, NRST, TXEN and RXEN
- Correct E22 TCXO and external RF-switch control in firmware

### RF

- Direct E22 ANT to board-mounted SMA connection
- No u.FL intermediate connector
- Controlled 50-ohm route based on the final fabricator stack-up
- Continuous ground reference and switching-node separation

### Battery and charging

- Protected 1S flat LiPo
- 10 Ah capacity target
- At least 5 A continuous discharge capability
- At least 2 A permitted charge current
- Board-mounted XT30 battery connector
- Board-mounted XT30 solar connector
- 6 V class solar panel
- 10 W panel supported; 20 W recommended
- USB-C charging through BQ25798
- Solar MPPT and power-path operation
- Maximum programmed charge current: 2.0 A
- Battery voltage and state-of-charge telemetry through MAX17048
- No battery-temperature monitoring
- Battery pack must include internal over-charge, over-discharge, over-current and short-circuit protection

### XIAO power and service

- XIAO remains socketed on its edge pins
- Carrier powers XIAO through underside BAT and GND pads only
- Short two-wire lead terminates in a keyed 2-pin JST-GH connector beside the XIAO socket
- LM66100 ideal diode prevents reverse current into the main battery rail
- Carrier does not drive XIAO 5V/VBUS
- No pogo pins, SWD connector or multi-wire underside harness
- Normal firmware and recovery use XIAO USB-C and onboard reset

### User interface

- One external charge LED only
- No power button
- Automatic startup when the protected battery is connected
- Battery XT30 serves as the master disconnect

### Mechanical and manufacturing

- Board-only design; enclosure design is outside Rev A scope
- First prototype quantity: five boards
- Four-layer controlled-impedance PCB
- Factory assembly for all pick-and-place-compatible components
- Socket headers, XIAO power lead and any unsuitable mechanical connectors may be hand-installed
- XT30 and SMA footprints must tolerate or transfer connector insertion force appropriately

## Electrical performance requirements

### 5 V radio rail

- Nominal output: 5.0 V
- Continuous design target: 2 A
- Transient design target: 3 A
- E22 connected directly to 5 V with no load switch or eFuse
- TPS61088 soft-start, current limit and local bulk capacitance must prevent rail collapse
- TXEN and RXEN default low during reset

### Battery path

- Copper, vias and connector path sized for at least 5 A continuous
- Full-power operation may be reduced near low battery voltage in firmware

### Charger

- TI BQ25798RQMR
- 1S startup configuration
- 750 kHz switching frequency
- 2.2 uH charger inductor
- /CE tied low for autonomous charging
- TS biased to the normal region using a fixed divider
- Charger telemetry polled over I2C

## Removed functionality

- Power button and latch controller
- Radio load switch
- eFuse
- Battery thermistor and NTC connector
- Full, fault and carrier status LEDs
- SWD connector
- Pogo contacts
- Eight-wire XIAO harness
- Solar-present and USB-present telemetry
- Radio-disable jumper
- Battery reverse-polarity circuit
- GPS, display and environmental sensors

## Resolved compatibility issues

### XIAO USB backfeed

Resolved by powering the XIAO through BAT/GND via LM66100. The carrier never drives XIAO VBUS.

### XIAO GPIO count

All eleven edge GPIOs are allocated to the E22 and shared I2C bus. No additional GPIO-dependent features remain.

### Radio surge

Resolved by the oversized TPS61088 stage, high-current inductor, controlled soft-start and 330-470 uF local E22 bulk capacitance.

### Solar panel flexibility

Resolved with a deployment envelope rather than a fixed panel SKU: 6 V class, 20 W recommended.

## Remaining implementation work

No architecture-level decisions block KiCad. Remaining tasks are implementation and verification:

1. Verify symbols and footprints against manufacturer drawings.
2. Select exact capacitor MPNs after effective-capacitance and assembler-stock review.
3. Capture the schematic and run ERC.
4. Perform a schematic-level compatibility audit.
5. Obtain the PCB fabricator stack-up and calculate the RF geometry.
6. Place, route and run DRC.

## Audit verdict

The frozen Rev A requirements are coherent and suitable for KiCad schematic capture. Prototype testing remains required for charging behavior, USB source handling, converter temperature, 5 V transient response and RF noise.

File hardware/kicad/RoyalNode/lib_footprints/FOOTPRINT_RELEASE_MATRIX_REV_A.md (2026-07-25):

# RoyalNode Rev A Footprint Release Matrix

## Purpose

This matrix controls which footprints are allowed into the Rev A PCB layout. A symbol may exist before its footprint is released; a footprint is not released until the package drawing, pad numbering, polarity/orientation, courtyard, and assembly notes have been checked.

Source document:

```text
docs/FOOTPRINT_AUDIT_REV_A.md
docs/REFERENCE_DESIGNATORS_REV_A.md
docs/FOOTPRINT_SOURCE_LINKS_REV_A.md
```

## Release States

| State | Meaning |
|---|---|
| `not_started` | No project-local footprint exists yet |
| `draft` | Footprint exists but must not be used for release routing |
| `draft_envelope_only` | Mechanical outline exists with no electrical pads and must not be assigned to schematic symbols |
| `imported_unchecked` | Vendor/third-party CAD imported but not checked against package drawing |
| `conditional_release_candidate` | Checked against primary source plus intended assembler library; allowed for Rev A planning and DFM, pending final order review |
| `checked` | Pad numbering and package geometry checked against manufacturer drawing |
| `released_rev_a` | Approved for Rev A placement/routing |

## Matrix

| Ref | Part / footprint target | Risk | State | Release requirement |
|---|---|---|---|---|
| U1 | BQ25798RQMR, TI RQM0029A HOTROD VQFN-HR | High | `conditional_release_candidate` | Project-local copy of KiCad `Texas_RQM0029A`; verify against TI package drawing and JLC assembly before release |
| U2 | LM66100DCKR, TI DCK0006A SC-70-6 | Medium | `conditional_release_candidate` | Project-local SC-70-6 copy; verify against TI DCK0006A package drawing |
| U3 | TPS61088RHLR, TI RHL0020A VQFN-20 + EP pad 21 | High | `conditional_release_candidate` | Project-local copy of KiCad `Texas_VQFN-RHL-20_ThermalVias`; confirm exposed pad/via/paste strategy |
| U4 | LTC4365ITS8-1, ADI TS8 TSOT-23-8 | Medium | `conditional_release_candidate` | Project-local TSOT-23-8 copy; verify against ADI TS8 package drawing |
| Q1-Q3 | ISA170170N04LMDS, Infineon PG-DSO-8 | Medium | `conditional_release_candidate` | Project-local Infineon PG-DSO-8-27 thermal-via footprint; confirm duplicated drain/source pin mapping and orientation |
| MOD1 | Seeed XIAO nRF52840 socket assembly | Medium | `conditional_release_candidate` | Composite footprint uses two JLC/LCSC `C53202181` 1x7 socket strips; verify XIAO orientation, row spacing, and socket engagement before release |
| MOD2 | EBYTE E22-900M33S castellated module | High | `conditional_release_candidate` | Factory-installed PCBA item using EBYTE manual plus exact JLC/LCSC `C22399506` EasyEDA footprint cross-check; physical check deferred to assembled-board first article |
| J1/J2 | AMASS XT30PW-M right-angle male | Medium | `conditional_release_candidate` | Imported JLC/LCSC `C431092` EasyEDA geometry; confirm polarity from physical connector and add mating-plug clearance |
| J3 | JST-GH SM02B-GHS-TB 2-pin horizontal | Low | `conditional_release_candidate` | Project-local copy of KiCad JST-GH footprint; verify against JST drawing, harness retention and assembler source |
| J4 | JST-GH SM02B-GHS-TB 2-pin horizontal | Low | `conditional_release_candidate` | Same JST-GH footprint as J3; confirm NTC harness pin 1 marker and battery-pack cable mate |
| J5 | Molex 0732511150 SMA edge launch | High | `draft_envelope_only` | JLC/LCSC `C841205` import exists but is not placed; use Molex launch for 1.60 mm PCB and merge with final GCPW stack-up |
| J6 | JST-GH SM04B-GHS-TB 4-pin horizontal | Low | `conditional_release_candidate` | Project-local copy of KiCad JST-GH footprint; optional MeshCore environmental I2C connector only |
| F1 | Littelfuse 0483005.DR, 483 series 1206 chip fuse | Low | `conditional_release_candidate` | Project-local copy of KiCad 1206 fuse footprint; verify against Littelfuse 483 package drawing and selected panel Isc |
| L_BQ | Coilcraft XAL7070-222MEC | Medium | `conditional_release_candidate` | Project-local KiCad Coilcraft XAL7070 footprint; confirm against Coilcraft recommended land pattern |
| L_BOOST | Coilcraft XAL7030-222MEC | Medium | `conditional_release_candidate` | Project-local KiCad Coilcraft XAL7030-222 footprint; confirm against Coilcraft recommended land pattern |
| C_BULK | Panasonic 10SVPC330M | Medium | `conditional_release_candidate` | Project-local copy of KiCad `CP_Elec_8x6.9`; verify Panasonic package drawing and pad-1 positive polarity |
| Passives | 0402/0603/1206/1210 R/C | Low | `not_started` | Standard KiCad/JLC-compatible metric footprints acceptable after value/package review |

## First Footprint Work Order

1. E22-900M33S module footprint and RF-side geometry.
2. Molex 0732511150 SMA edge-launch footprint.
3. TPS61088 footprint and boost-inductor footprint.
4. BQ25798 HOTROD footprint and charger-inductor footprint.
5. Promote or reject the imported SMA footprint after RF/mechanical review.
6. Verify XIAO and XT30 first-article mechanical fit.

This order lets the board outline and high-risk RF/power placement stabilize before low-risk passives are assigned.

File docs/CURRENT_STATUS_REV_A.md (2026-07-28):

# RoyalNode Rev A Current Status

## Snapshot

Rev A is an active KiCad engineering scaffold, not a fabrication release.

Current architecture:

- XIAO nRF52840 socketed compute module.
- EBYTE E22-900M33S factory-installed radio module.
- Protected 1S Li-ion/LiPo battery pack.
- 6 V / 20 W class solar input.
- XT30 solar and battery connectors.
- BQ25798 1S solar/USB charger and power-path controller.
- TPS61088 5 V radio boost rail.
- Optional BME680/environmental I2C connector using JST-GH.
- PCB-mounted edge-launch SMA path from E22 ANT pin 21.

## Implemented In KiCad

- Generated root schematic with major active parts, connectors, inductors, fuse, off-board thermistor representation and 54 support passives.
- Project-local symbol library for the current Rev A major parts.
- Project-local release-candidate footprints for E22, XIAO socket, BQ25798, TPS61088, LM66100, LTC4365, Infineon power MOSFETs, XT30, JST-GH, inductors, solar fuse and E22 bulk capacitor.
- Net-aware PCB placement scaffold with 75 generated footprint anchors.
- KiCad net classes for high-current power, switching nodes, RF and sensitive sense nets.
- No dedicated test points, current shunts, probe loops or bench-only measurement links.

## Current Checks

Preferred local verification command:

```text
make layout-status
```

This runs the repository validator, KiCad ERC, KiCad DRC, the report gate that confirms only the expected Rev A warning/unrouted state is present, and the unrouted-summary generator.

Expected command state:

```text
make validate
  passes

kicad-cli sch erc --exit-code-violations --severity-all
  0 violations

kicad-cli pcb drc --severity-all
  0 active DRC violations/warnings
  0 unconnected items
```

The `lib_footprint_mismatch` rule is set to `ignore` for Rev A because the remaining markers apply to project-local release-candidate footprints that are tracked in the footprint audit and still require final JLCPCB DFM/PCBA review before fabrication release.

J3 has been moved to the bottom service edge to clear the J6/SMA/C503 area. J6 has been moved to the top service edge for the optional BME680/environmental connector.

`BOOST_EN` is now routed from the XIAO control pin to the TPS61088 enable pin and R405 pulldown. The accepted route uses the existing control corridor and keeps the local pulldown tied into the same enable net without adding measurement links.

`BAT_RAW` is now routed from the battery XT30 pad to the LM66100/XIAO battery-isolation input, the local battery capacitor island and the U1 BAT pins. `BATP_KELVIN` is now routed as a separate low-current sense branch from U1 BATP to R202, and `BQ_PMID` now bridges from U1 into the PMID capacitor bank.

`BOOST_ILIM`, `BOOST_SS`, `BOOST_COMP`, `BOOST_VCC`, `BQ_REGN`, `BQ_SDRV`, the C216 `BQ_BTST1`/local `BQ_SW1` bootstrap side, the accepted `BQ_SW1` left-wrap to L1, `BQ_PMID`, the C217 local `BQ_SW2` bootstrap side, `BQ_BTST2` and the TPS61088 `BQ_SYS` input-cap cluster are now locally routed after moving their support passives beside the relevant ICs. `E22_RXEN` is now routed through a short top-layer fanout and bottom-layer escape. `5V_RADIO` is now connected from U3 VOUT to the E22 VCC pins, the feedback/output-cap island, C503 and the lower radio capacitor bank. The `BQ_VBUS` capacitor bank is now connected into U1 after rerouting `BQ_STAT` onto an internal detour and nudging the local `BQ_BTST1` jog, and the Q3-side `BQ_VBUS` selector bridge is now connected through a split-layer high bridge. `USB_VBUS_RAW` is now routed from U1 to Q3 through a split In2/In1 high-corridor route, `SOLAR_PROTECTED` is now routed from U1 to the protected solar spine through a split In2/In1 left-edge overpass, and `BQ_SW2` is now routed through the accepted lower U1/right-side switch-node escape. A dedicated R203-area GND stitch now ties the former top-fill island into the Layer-2 reference plane.

The draft quote-export workflow now runs with:

```text
make export-draft-quote
```

It produces Gerber, drill, CPL, BOM, netlist and report artifacts under `hardware/fabrication/quote_draft_rev_a`. The generated package remains explicitly marked not-for-fabrication until the SMA launch and high-current power-path release reviews are resolved.

## Active Blockers

1. SMA launch is not released.
   The board still uses a draft SMA envelope. The Molex/JLC footprint and final 50-ohm GCPW geometry must be reviewed against the selected JLCPCB stack-up before routing release.

2. E22 first physical fit check happens after factory assembly.
   The user will not have a loose E22 module before ordering. Rev A therefore relies on JLCPCB/LCSC part `C22399506`, DFM/PCBA review and first-article inspection.

3. XT30 polarity and mating clearance still need mechanical review.
   The project uses XT30, not XT60.

4. XIAO socket orientation still needs physical USB-C, antenna and header-engagement review.

5. Power-stage placement still needs release review.
   U3/L2 are now rotated into the preferred topology and the generated routes are connected, but the current support-passive locations are still staging anchors for review, not final optimized high-di/dt loop placement.

## Authoritative Documents

Use these first:

- `docs/REQUIREMENTS.md`
- `docs/ARCHITECTURE.md`
- `docs/DESIGN_FREEZE_REV_A.md`
- `docs/WIRING_BLUEPRINT.md`
- `docs/NET_MAP_REV_A.md`
- `docs/PIN_AUDIT_REV_A.md`
- `docs/FOOTPRINT_AUDIT_REV_A.md`
- `docs/PCB_PLACEMENT_STATUS_REV_A.md`
- `docs/UNROUTED_SUMMARY_REV_A.md`
- `docs/LAYOUT_WORK_QUEUE_REV_A.md`
- `docs/REMAINING_ROUTE_CLUSTER_PLAN_REV_A.md`
- `docs/U1_RIGHT_SIDE_REFACTOR_REV_A.md`
- `docs/PCB_NET_CLASSES_REV_A.md`

Older conflict reviews and trace-path audits are retained as historical reasoning. Where they conflict with the files above, the current authoritative documents win.

## Next Useful Work

1. Unblock the SMA footprint and GCPW launch.
2. Refine the power-stage placement and copper for release-quality high-current loops.
3. Confirm XIAO socket and XT30 mechanical orientation.
4. Begin actual routing only after the SMA/power placement questions are settled.

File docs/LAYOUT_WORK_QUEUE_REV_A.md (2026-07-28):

# Layout Work Queue Rev A

RoyalNode Rev A now has a clean final signal-route checkpoint with 0 DRC violations and 0 unconnected items. This work queue translates the generated summary into the next layout and release-review passes.

Use this sequence rather than routing random ratsnest lines.

Regenerate the PCB scaffold with:

```text
make generate-board
```

Do not run placement and route generation in parallel; both commands rewrite `RoyalNode.kicad_pcb`.

## Current Gate

```text
make layout-status
```

Current result:

- ERC: 0 violations
- DRC: 0 active violations/warnings; `lib_footprint_mismatch` is ignored by project policy for tracked local release-candidate footprints
- Unconnected: 0 items

## Pass 1: Placement Blockers

Resolve these before routing more long traces:

1. Finalize or replace the edge-launch SMA footprint and RF launch geometry.
2. Preserve the accepted BQ25798 `BQ_REGN`/`ILIM_HIZ` local fanout during nearby charger rework.
3. Rework the protection-divider ground escape around `OV_NODE` and the accepted control-routing corridor.
4. Confirm XT30 connector polarity, board-edge access, and mating-plug clearance.
5. Re-route J6 only after confirming the new top-edge service clearance remains acceptable.

## Pass 2: Ground System

`GND` is now handled by generated top copper and Layer-2 reference pours. The former top-fill island is tied into the Layer-2 reference plane with a dedicated R203-area GND stitch.

Planned work:

- Add functional stitching vias near grounded IC pads and connector grounds.
- Extend or shape local ground copper where it does not break RF or switch-node discipline.
- Keep Layer 2 as the uninterrupted ground reference.
- Add E22 ground via stitching only after the RF/SMA launch decision is stable.

## Pass 3: Charger Power Path

Route remaining charger/service power as deliberate copper after placement review:

Preserve the accepted `BQ_SYS`, `BQ_PMID` and `SOLAR_FUSED` routes unless a grouped power-stage refactor replaces them.

These nets should not be completed as narrow generated traces.

The 2026-07-25 `BQ_VBUS` Q2 and Q3 duplicate-drain islands are now joined with internal-layer bridges from each left D2 pad to the existing right-side `BQ_VBUS` backbone. An outside-left Q3 bridge trial was rejected because it crossed the accepted `BQ_ACDRV2` and `BQ_USB_SELECTOR_COMMON` routing corridors.

The 2026-07-25 `SOLAR_PROTECTED` Q1 duplicate-drain island is now joined with an internal-layer bridge from the left protected-output pad to the existing protected-output spine. The first right-side via location was rejected for crowding `SOLAR_PROT_COMMON`; the accepted via lands lower on the protected-output spine to clear both `SOLAR_PROT_COMMON` and `BOOST_EN`.

The 2026-07-25 `SOLAR_PROTECTED` U4 protected-output sense branch is now routed with a short top-layer fanout from U4 and an internal-layer bridge into the Q1 protected-output island. The first U4 via-in-pad location was rejected for no-net pad and hole-clearance issues; the accepted route moves the via off-pad and left of the `SOLAR_PROT_COMMON` via.

A 2026-07-25 `SOLAR_PROTECTED` U1-entry trial from the Q1 protected-output spine was rejected. The U1-side via crowded/shorted the `BQ_ACDRV2` lower-row pad, and the internal-layer approach crossed the accepted `BQ_VBUS` and I2C corridors. Keep the remaining `SOLAR_PROTECTED` U1 connection blocked until the U1 lower-edge fanout is reworked as a group.

A 2026-07-26 `SOLAR_PROTECTED` U1-entry retry from the accepted Q1/Q2 island
was rejected. The U1 fanout crossed/crowded `BQ_STAT`, the internal span
crossed the accepted `BQ_SYS` spine, and the selector-side approach shorted
against the `BQ_SOLAR_SELECTOR_COMMON` via. Keep this connection in the
lower-edge U1/input-selector placement pass.

A 2026-07-25 `BQ_VBUS` Q3-to-U1 bridge trial was rejected. The U1-side via/fanout crowded `BQ_STAT` and `BQ_BTST1`, while the back-layer route crossed accepted `BQ_STAT` and I2C paths. Keep the remaining `BQ_VBUS` U1 connection blocked until the U1 lower-left fanout is reworked as a group.

A 2026-07-26 `BQ_VBUS` cap-bank-to-U1 inner-layer retry was rejected. The U1
fanout shorted/crowded `BQ_STAT` and crossed `BQ_BTST1`; the cap-bank approach
crossed the `BQ_PMID` via, crossed the accepted `BQ_SYS` spine and left a
dangling inner segment. Rework the U1 lower-left pins and the VBUS/PMID cap
bank together rather than drawing another direct bridge.

A 2026-07-26 `BQ_VBUS` cap-bank-to-U1 route after the accepted REGN pin-5
route was also rejected. The U1 fanout shorted into the new `BQ_REGN` escape
and BAT_RAW inner trace, while the cap-bank side crossed `BQ_PMID` and the
accepted `BQ_STAT` back-layer corridor. Keep VBUS in the same U1 lower-edge
and capacitor-bank placement pass as PMID/STAT/REGN.

A 2026-07-26 `BQ_VBUS` U1-to-Q3 In2.Cu bridge trial after the larger outline
was rejected. The U1-side via and internal run shorted or crossed ACDRV2,
BTST1, SYS, STAT and I2C corridors. Do not retry this as a direct U1-to-Q3
internal bridge; it needs a grouped U1 lower-edge refactor.

A 2026-07-28 `BQ_VBUS` capacitor-bank-to-U1 route is accepted. The route uses
an allowed 0.50/0.25 mm via near U1, a B.Cu corridor back to the VBUS capacitor
bank, an In2.Cu detour for the low-current `BQ_STAT` return, and a slight
leftward jog of the local `BQ_BTST1` route. This removes the VBUS cap-bank
ratsnest item while keeping DRC clean. The remaining `BQ_VBUS` item is the
Q3 selector-side connection to U1.

A later 2026-07-28 `BQ_VBUS` Q3-to-U1 bridge is accepted. It uses an In1.Cu
high bridge from the Q3 VBUS backbone to a via at 64.00, 85.60 mm, then an
In2.Cu drop into the accepted U1/cap-bank VBUS via. This clears the nearby
`BAT_RAW`, `BQ_ACDRV1`, `BQ_ACDRV2`, `NTC_SENSE` and L1/`BQ_SW1` corridors and
removes `BQ_VBUS` from the current unrouted list.

The 2026-07-25 `BQ_SYS` capacitor-bank-to-U1 entry is now routed with an internal-layer spine from the SYS capacitor island and a short top-layer entry into U1 pad 25. The accepted via was nudged left to clear the nearby `BQ_SDRV` route.

A 2026-07-28 `BQ_SYS` U1-entry support refactor is accepted. The entry via is
now staged at 66.35, 70.50 mm, and the SYS top-layer entry lands into the lower
edge of U1 pad 25 while preserving DRC cleanliness. This creates the clearance
used by the accepted lower U1/right-side `BQ_SW2` pad-26 escape.

The 2026-07-25 `BQ_SYS` L2-to-SYS-spine route is now routed with a short top-layer L2 fanout and a wider internal-layer branch into the accepted SYS spine. This leaves the U3 VIN/input-cap connection as the main remaining boost-input power-loop item.

The 2026-07-25 `BQ_SYS` U3 VIN-to-L2 spine branch is now routed with a compact top-layer U3 fanout and an In1 branch into the L2/SYS spine. Intermediate trials hit BOOST_EN, I2C/E22 internal routes, BOOT clearance and C407 ground thermal starvation; the accepted via lands lower/left enough to keep C407's ground thermal intact.

A 2026-07-25 `BQ_SYS` boost-input-cap-to-U3 spine corridor trial was rejected. In1 crossed `BOOST_FB` and crowded `BOOST_EN`; In2 avoided those but crossed E22 reset/RXEN and the XIAO/I2C service corridor; B.Cu crossed `SPI_SCK`, I2C and the XIAO through-hole row with solder-mask issues. Keep the remaining boost-input connection as a placement/copper-pour pass rather than a long straight corridor.

The 2026-07-25 TPS61088 input-cap placement pass moved C400, C401 and C404 from the remote placeholder boost row into the local U3/L2 input area. C400/C401 now form a local `BQ_SYS` bulk-cap bus below L2, and C404 is placed as the local high-frequency bypass. The accepted top-layer copper removes `BQ_SYS` from the unrouted list while keeping DRC clean.

## Pass 4: Switch Nodes

Route only after BQ25798 and TPS61088 placement is compact:

- `BQ_SW1`
- `BQ_SW2`
- `BOOST_SW`

The current layout ties the adjacent TPS61088 switch pins into L2 with compact local top-layer copper. C406 and R402 have been moved into the boost-stage neighborhood and their BOOT/FSW switch-node branches are routed. The remaining boost support passives still need a grouped placement pass.

C216 is now relocated below U1 with `BQ_BTST1` and the local capacitor side of `BQ_SW1` routed. The remaining `BQ_SW1` ratsnest item is the inductor/power-loop path, not the bootstrap-cap connection.

C217 is now staged beside the charger power stage and its local `BQ_SW2` side is tied to L1. The companion `BQ_BTST2` escape is now routed with a top-layer dogleg after straightening the local `BQ_PROG` route. The 2026-07-28 lower U1/right-side `BQ_SW2` route closes the U1-to-L1 span while preserving the accepted `BQ_SYS` entry.

A direct 2026-07-25 `BQ_SW2` U1-to-L1 top-layer span was rejected because it crossed the U1 `I2C_SCL`/ground pad row and the accepted SCL fanout. Preserve that rejection note as history; the accepted route uses a different lower/right-side escape.

A later 2026-07-25 `C217` move to the lower-right of U1 was rejected. It worsened the ratsnest count, overlapped the L1 courtyard, swapped the intended `BTST2`/`SW2` pad approach after rotation, and crossed/shorted the accepted `BQ_TS` via corridor. Keep `C217`, `BQ_TS`, `BQ_REGN` and the U1 right-side escape as one placement pass.

A later 2026-07-25 `BQ_SW2` trial that shifted the accepted `BQ_SYS` U1-entry via rightward was rejected. The SYS shift collided with `BQ_SDRV`, and the SW2 overpass/drop beside Q3 shorted or mask-bridged against the USB selector pads. Keep SW2 blocked until the SDRV/PROG/TS/Q3 service corridor is replanned as a group.

A 2026-07-25 direct `BQ_SW1` U1-to-L1 top-layer route was rejected. It dropped the ratsnest count but ran down the U1 left pad row, shorting/crowding `BQ_STAT`, `BQ_VBUS`, `BQ_BTST1`, `BQ_REGN`, `USB_VBUS_RAW` and `SOLAR_PROTECTED` pads. Move/refactor the L1/U1 switch-node placement before retrying `BQ_SW1`/`BQ_SW2`.

A 2026-07-26 grouped `BQ_BTST2`/C217/R203 refactor was rejected. It briefly
reduced the ratsnest count, but placing C217 near the U1 right edge and moving
R203 into that same corridor produced `BQ_BTST2`/`BQ_PROG`, `BQ_PROG`/`BQ_TS`
and `BQ_SW2`/`BQ_PROG` crossings or shorts depending on the PROG escape layer.
The temporary C217/R203 placement and orphaned PROG stub are retired. Keep the
next BTST2 attempt as a broader right-side U1 refactor that includes TS, PROG,
INT, SW2 and the nearby selector/service routes.

A later 2026-07-26 `BQ_SW2` right-side spine from U1 pad 26 to the existing
C217/L1 island was also rejected. The vertical corridor beside U1 shorts or
mask-bridges against `BQ_SYS`, `BQ_TS`, `BQ_INT`, `BQ_PROG` and the accepted
I2C fanout. Do not route SW2 down the U1 right pad row without first moving
TS/PROG/INT/I2C support routing out of that channel.

A 2026-07-25 trial moving L1 above U1 was rejected. The topology would shorten the switch nodes, but in the current floorplan it collides with the accepted TPS61088 `BQ_SYS` input-cap cluster, C216/C218 support passives and the accepted U1 `BQ_SYS`/`BQ_SDRV` escape routes. Do not move only L1 upward; the charger power stage needs a broader floorplan change with the boost input-cap cluster and U1 support passives considered together.

A 2026-07-25 long `UV_NODE` bottom-layer route was rejected. It collided with the fused-solar U4 via, crossed the accepted I2C/SPI corridors, and clipped the XIAO through-hole row. Treat the protection-divider sense nets as a U4/divider placement pass rather than long board-spanning traces.

## Pass 5: Remaining Sense And Control Nets

Route after nearby placement is stable:

- `BQ_TS`
- `BQ_PROG`
- `BQ_INT`
- `LTC_SHDN`
- `UV_NODE`
- `OV_NODE`
- `NTC_SENSE`

These should avoid switch-node copper and RF launch copper.

`BQ_SDRV` is now locally routed after relocating C218 near U1 and sliding it left to clear the accepted 3.3 V pullup route.

## Hold Items

- Do not add test points, current shunts, probe loops, or bench-only measurement links.
- Do not route `RF_915` until the SMA footprint and stack-up are final per `docs/RF_STACKUP_PLAN_REV_A.md`.
- The 2026-07-25 Molex product-page recheck keeps `732511150` selected, but does not release the footprint. The sales drawing/recommended launch geometry is still required.
- `BOOST_EN` is now routed through the accepted control corridor. Two earlier R405 relocation trials near the TPS61088 EN pin were rejected: one collided with the E22 SPI pad/courtyard corridor and one collided with the E22_NSS route/via corridor.
- A TPS61088 small-passive relocation trial that moved C405/C406/C407/C408 and R400/R401/R402/R403/R404 into the immediate U3 top/left corridor was rejected on 2026-07-25. It shorted into the existing E22_NSS/SPI fanout, overlapped the E22 courtyard and collided with the L2 inductor courtyard. Treat the boost support network as requiring a U3/L2 placement shift or a bottom-side/local-via strategy, not a simple top-side shove toward the E22.
- Two 2026-07-25 `BOOST_FB` divider-only relocation trials were rejected. A left/below-U3 placement collided with the E22 SPI/MISO edge and MOD2 courtyard; a lower/right-U3 placement shorted against TPS61088 ground/exposed-pad geometry and the `5V_RADIO` side of R400. Keep `BOOST_FB` blocked until the TPS61088 small-passive strategy is reworked as a group.
- The accepted 2026-07-25 U3/L2 rotation puts TPS61088 VOUT toward the E22 5 V entry and BOOST_SW toward the XAL7030 inductor. Continue boost placement from this topology.
- A 2026-07-25 `BQ_SW1` left-wrap route from U1/C216 to L1 is accepted. It leaves the U1 top edge through the existing bootstrap corridor, wraps outside the left side of U1, and enters the L1 SW1 pad without new DRC violations.
- A 2026-07-25 `5V_RADIO` U3-to-E22 internal-layer branch trial was rejected. The In1 shortcut crossed/crowded the accepted `SPI_SCK` via and `BOOST_FB` tracks, the U3 top fanout crowded a no-net U3 pad, and the via collided with the accepted E22 `DIO1`/`BUSY` internal routing columns. Keep the radio rail as a deliberate high-current copper corridor or pour after the boost/passive placement is reviewed, not as a long internal trace shortcut.
- A later 2026-07-25 lower `5V_RADIO` corridor trial from U3 toward the E22 VCC pads was rejected. The E22-side entry shorted/crowded MOD2 GND pin 11, the lower corridor collided with accepted E22 `BUSY`/`RXEN` fanouts, and the U3-side via crowded `BOOST_FB`. The radio rail needs a deliberate E22/U3 power-copper placement pass, not a lower-layer shortcut.
- A 2026-07-25 C503 radio-bulk-cap relocation trial was rejected. Placing the polymer can left of MOD2 electrically reduced the ratsnest, but the body could not clear both the board edge and the E22 module courtyard; moving it into the lower capacitor bank collided with J4/edge silk or left a dangling route and did not improve the accepted count. Keep C503 at the legal scaffold location until the radio bulk-cap bank is mechanically replanned.
- A 2026-07-25 local `BQ_REGN` U1 pin-5-to-pin-17 bottom bridge trial reduced the ratsnest count by one but was rejected. The U1-side vias shorted/crowded the accepted `BAT_RAW`, `BQ_TS`, `BQ_BTST1` and I2C corridors around the HOTROD package. Rework the REGN/TS/BATP local passive and U1 escape cluster together instead of adding vias beside the existing U1 fanout.
- A 2026-07-25 top-layer `BQ_REGN` wrap around U1 was rejected. It connected the pins electrically but crossed/crowded `BQ_ACDRV1`, `BQ_ACDRV2`, I2C and `BQ_TS`, and starved U1 ground thermal relief. Keep REGN out of the existing U1 perimeter routes until that support-passive cluster is rearranged.
- A 2026-07-25 `SOLAR_PROTECTED` U4-sense branch trial was rejected. The left-side route crossed the accepted `SOLAR_PROT_GATE` path; the right-side route crossed the fused-solar back-layer hop or collided with the XIAO battery-isolation route. Treat U4 protected-output sensing as a placement/pour-level follow-up, not a casual single-trace route.
- `BOOST_SS` is now locally routed after relocating C407 above U3 and shifting the BOOT route right to clear the capacitor ground pad.
- 2026-07-25 `BOOST_VCC` / C405 placement trials below U3 were rejected. The rotated trial put the VCC pad away from U3, starved the U3 top-ground thermal relief and introduced an extra library-mismatch warning. The non-rotated 0805 trial shorted against the FSW route and overlapped U3/L2 courtyards. Revisit C405 with a coordinated U3/L2/FSW placement pass instead of a quick shove below the IC.
- A later 2026-07-25 C405 local-placement retry below U3 was rejected in both orientations. The 180-degree version shorted C405 ground into `BOOST_ILIM`; the 0-degree version shorted/crowded `BOOST_FSW`, R402 and the L2 courtyard. Keep `BOOST_VCC` in the grouped TPS61088 support-passive pass.
- A subsequent 2026-07-25 C405 offset-left retry was also rejected. It crowded the U3 exposed ground pad/thermal relief and collided with `BOOST_EN`, `BOOST_FSW`, R402 and the local solder-mask constraints. Do not keep searching the immediate U3 underside for C405; move the surrounding EN/FSW/ILIM support cluster or open a new bottom-side strategy.
- A later 2026-07-25 `BOOST_VCC` direct route trial from U3 to C405 was rejected. The U3-side fanout shorted/crowded U3 ground and exposed-pad geometry, the internal route crossed `BOOST_EN`, and the C405-side via collided with the accepted SPI corridor. Keep `BOOST_VCC` blocked until U3 support-passive placement is reworked.
- 2026-07-26 bottom-side C405/`BOOST_VCC` trial was rejected. Placing C405 below U3 created pad-orientation ambiguity, shorted/crowded U3 exposed ground and C405 ground geometry, starved the U3 ground thermal and introduced bottom-side text/footprint warnings. Do not use a bottom-side C405 exception at the current U3 location; solve BOOST_VCC with a broader U3 support-passive placement pass.
- A 2026-07-26 C405 local-bypass placement trial below U3 after the larger
  outline was rejected. Even with pad 1 aligned under U3 VCC, C405 crowded
  BOOST_EN, BOOST_ILIM, FSW/R402, L2 or U3 ground thermal depending on
  orientation. Keep `BOOST_VCC` in the grouped TPS61088 EN/ILIM/FSW/support
  passive placement pass.
- A later 2026-07-26 vertical C405 trial after the accepted compensation
  placement was also rejected. The 0805 body still overlapped U3/R402
  courtyards, the ground pad shorted or crowded `BOOST_EN`/`BOOST_FSW`, and
  the top ground thermal was starved. The generated trial segment is retired.
- A follow-up 2026-07-26 0603 C405 package trial briefly reduced the ratsnest
  count to 10, but no checked placement produced a clean layout. The upper
  pocket shorted/crowded the U3 ground pad and U3 courtyard; the lower pocket
  starved U3 ground thermal relief and overlapped R403; moving R403 downward
  hit the accepted `BOOST_COMP` and E22 `BUSY` corridors. Keep C405 as the
  locked 0805 part until the whole TPS61088 EN/FSW/ILIM/VCC support cluster is
  replanned.
- A 2026-07-28 C405 local-placement retry to the right of U3 removed the
  `BOOST_VCC` ratsnest but was rejected. The route crossed `BOOST_EN`,
  crowded `BOOST_FSW`, overlapped U3/L2 courtyards and solder-mask-bridged
  into the switch-node area.
- A later 2026-07-28 lower C405 retry below U3 briefly removed the
  `BOOST_VCC` ratsnest but was rejected. C405 still crowded `BOOST_EN`, R403
  and U3 silk/thermal geometry; moving `BOOST_EN` and R403 to compensate broke
  the accepted boost support routing and introduced new shorts.
- A later 2026-07-28 TPS61088 support-pocket refactor is accepted. C405 now
  sits below U3 with a short top-layer `BOOST_VCC` bypass route, R403 moves
  lower-left with an ILIM layer hop around `BOOST_COMP`, and R404 moves lower
  to preserve compensation clearances. The U3 reference field is hidden in the
  local release-candidate footprint to avoid silkscreen over the new bypass
  capacitor. This removes `BOOST_VCC` from the remaining ratsnest while
  keeping DRC clean.
- A 2026-07-28 `5V_RADIO` trial from U3 VOUT to the upper output-cap/sense
  island reduced the radio ratsnest count by one, but every tested internal
  layer crossed accepted routes: `In2.Cu` crossed E22 reset/DIO1 control,
  `In1.Cu` crossed `BOOST_EN`/`BOOST_FB`, and `B.Cu` crossed the SPI bus.
  Route the radio rail only after a grouped boost/E22 signal-corridor review.
- A 2026-07-25 `BOOST_COMP` internal-layer route trial from U3 to R404 was rejected. The U3-side via and top fanout crowded `BOOST_FB`, while shifted variants collided with the accepted E22 `BUSY`/`DIO1`/`NRST` internal routing columns or required tracks below the 0.15 mm rule. This is superseded by the accepted 2026-07-26 grouped compensation placement.
- A 2026-07-25 `USB_VBUS_RAW` right-edge service-route trial from MOD1 to Q3 was rejected on all tried layers. In1 crossed `BOOST_EN`; In2 crossed `BAT_RAW`, 3.3 V and I2C service routes; B.Cu crossed `XIAO_BAT_ISO`, `BQ_VBUS` and I2C. Keep `USB_VBUS_RAW` blocked until the right-edge service corridor is reworked or Q3/MOD1 placement changes.
- 2026-07-25 `BOOST_COMP` R404/C408 relocation beside U3 was rejected. The left-of-U3 corridor collided with the E22 module's SPI_MOSI pad/via and MOD2 courtyard, while the tighter vertical placement shorted the compensation RC node into adjacent pads. Keep TPS61088 compensation as part of a full U3/MOD2 corridor pass.
- 2026-07-26 `BOOST_COMP` bottom-layer route from U3 to R404 was rejected. The U3-side via violated clearance to the accepted `BOOST_FB` via, and the R404 entry crossed the existing `BOOST_COMP_RC` route, shorting the compensation pin to the RC node. Do not retry this corridor unless `BOOST_FB` and the compensation RC placement are reworked together.
- 2026-07-26 `BATP_KELVIN` right-side escape trials were rejected. The U1 escape via collided with nearby `BQ_REGN`, `I2C_SDA`, `BAT_RAW` and the accepted 3.3 V service corridor depending on layer and offset; B.Cu and In1/In2 long runs also crossed existing `BQ_SYS`, `BAT_RAW`, I2C or `BQ_TS` corridors. Keep BATP blocked until the U1 support-passive group and service routes are replanned together.
- 2026-07-26 post-REGN `BATP_KELVIN` left-escape retest was rejected. The route crowded the accepted REGN via/bridge, crossed BAT_RAW on B.Cu, shorted/crowded U1 SOLAR_PROTECTED/GND/ACDRV pads and left a dangling R202-side end. The later accepted BATP route uses a different U1 escape, B.Cu dogleg and In2.Cu hop around the existing BAT_RAW/NTC corridors.
- 2026-07-26 C217 near-U1 rotation trial was rejected. Pulling the BTST2/SW2 bootstrap cap into the U1 right-side gap shorted/crowded `BQ_SDRV`, `BAT_RAW`, `BQ_PROG`, R203/R204, Q3 and solder-mask rules, and increased the ratsnest count. C217 needs a broader U1-right-side refactor, not a simple local move into the existing support-passive gap.
- 2026-07-26 `BQ_REGN` C215/R200 island-to-U1-pin-5 route is accepted. The route leaves U1 pin 5 with a short left-side jog to avoid unused U1 pad 6, then runs on B.Cu back to C215/R200. This reduced the ratsnest from 16 to 15 and set up the later ILIM_HIZ top bridge.
- 2026-07-26 `BQ_REGN` ILIM_HIZ/U1-pin-17 bridge trial was rejected. A direct right-side via shorted/crowded the accepted `BQ_TS` via and I2C lane; shifting the TS via right then collided with R203/`BQ_PROG`, the 3.3 V service route and solder-mask rules. Keep ILIM_HIZ blocked until the TS/PROG/right-side U1 support cluster is replanned together.
- 2026-07-26 `BQ_REGN` ILIM_HIZ/U1-pin-17 top-layer bridge is accepted. The route ties U1 pin 17 to the accepted REGN pin-5 escape without adding vias, avoiding the TS via-hole conflict from the rejected right-side ILIM trial and reducing the ratsnest from 15 to 14.
- A 2026-07-25 `BQ_SYS` U3-VIN-to-L2 input hop trial was rejected. It crossed the accepted BOOT branch and crowded the L2 BOOST_SW pad. Route this as a deliberate boost-input copper shape after the BOOT/VIN/passive strategy is reviewed.
- A 2026-07-25 `USB_VBUS_RAW` XIAO-to-Q3 right-side route trial was rejected. The outside path hit the XT30/J1 no-net mechanical pad; the inward path crossed I2C, XIAO_BAT_ISO or fused-solar back-layer tracks. Revisit USB_VBUS_RAW with a deliberate layer-transition plan.
- A 2026-07-26 `BOOST_COMP` perimeter-route trial after adding the larger mechanical outline was rejected. The R404-side via collided with R405/GND, the bottom route crossed the existing SPI_SCK bus, and the U3-side via crowded BOOST_FB/E22_BUSY. This is superseded by the accepted 2026-07-26 grouped compensation placement.
- A later 2026-07-26 grouped compensation pass is accepted. R404 is now staged below-right of U3 at 60.2, 62.8 mm, C408 is staged at 63.6, 62.8 mm, the `BOOST_FB` U3-side via is nudged to 56.60, 55.55 mm, and `BOOST_COMP`/`BOOST_COMP_RC` are routed locally on top copper. This reduces the ratsnest from 12 to 11 without adding DRC errors.
- A 2026-07-26 top-edge `USB_VBUS_RAW` retry from MOD1 to Q3 reduced the
  ratsnest count but was rejected. The first horizontal exit crossed the 3.3 V
  pullup area; offset variants collided with the R204 3.3 V service spine,
  XT30/J1 mechanical PTHs or C503 ground/body clearance. Treat this as a
  placement/corridor issue around MOD1/J1/C503, not a simple edge trace.
- A follow-up 2026-07-26 B.Cu edge route for `USB_VBUS_RAW` was also rejected.
  It crossed accepted `BQ_VBUS`, `XIAO_BAT_ISO` and I2C_SDA service routes.
  Keep USB raw routing blocked until the right-edge service corridor is
  replanned.
- A 2026-07-28 `USB_VBUS_RAW` U1-to-Q3 bottom-edge service-route trial was
  rejected. It reduced the ratsnest count temporarily, but crossed or crowded
  `BQ_ACDRV2`, `BQ_VBUS`, `XIAO_BAT_ISO`, `NTC_SENSE`, `BATP_KELVIN` and
  `BQ_REGN`. The remaining U1 USB input connection needs the same grouped
  U1/Q3/service-connector refactor as `BQ_VBUS`.
- After moving the right-edge 3.3 V service leg to `In2.Cu`, a 2026-07-26
  top-edge `USB_VBUS_RAW` route from MOD1 5V to Q3 pads 7/8 is accepted. This
  removes the MOD1-to-Q3 USB ratsnest item; the remaining `USB_VBUS_RAW` item
  is the Q3-to-U1 sense/input connection.
- A 2026-07-26 Q3-to-U1 `USB_VBUS_RAW` bottom-layer sense-route trial was
  rejected. Lower routing crossed I2C_SCL, `BQ_ACDRV2` and
  `BQ_USB_SELECTOR_COMMON`; a farther-right variant crossed the `BAT_RAW`
  trunk and crowded `BQ_VBUS`. Keep the remaining USB raw U1 connection in the
  lower-edge U1 fanout refactor.
- A later 2026-07-26 top-layer Q3-to-U1 `USB_VBUS_RAW` service-corridor trial
  was also rejected. The U1 exit crossed `BQ_REGN`, `BQ_ACDRV1`,
  `BQ_ACDRV2`, I2C_SDA/SCL and the Q3-side `BQ_VBUS` via. The generated trial
  segment is retired.
- 2026-07-28 `USB_VBUS_RAW` U1-to-Q3 service trials briefly reduced the
  ratsnest count by one but were rejected. The U1 fanout crowded `BQ_REGN` or
  `SOLAR_PROTECTED`, while the tested `In1.Cu`, `In2.Cu` and `B.Cu`
  backbones crossed `BQ_ACDRV2`, `BQ_TS`, 3.3 V, `BAT_RAW`, `BATP_KELVIN`,
  `BQ_VBUS` or NTC routes.
- A later 2026-07-28 `USB_VBUS_RAW` high-corridor retry also reduced the
  ratsnest count to 2 but was rejected. The B.Cu version crossed `BAT_RAW`
  and `BATP_KELVIN`; the In1/In2 variants crowded U1 pad 7/pad 9 and crossed
  `BQ_ACDRV1`, `BQ_ACDRV2`, `BQ_TS`, 3.3 V or NTC corridors. Keep USB raw in
  the grouped lower-edge U1/input-selector refactor.
- A later 2026-07-28 `USB_VBUS_RAW` split-layer high-corridor route is
  accepted. It uses a horizontal U1 pad-8 fanout, an In2.Cu vertical escape,
  a left-side layer hop before crossing `BQ_TS`, and an In1.Cu high overpass
  around L1, NTC, ACDRV and `BQ_VBUS` corridors before entering Q3. This
  removes `USB_VBUS_RAW` from the current unrouted list while keeping DRC
  clean.
- A BQ25798 right-side TS-divider relocation trial was rejected because it shorted `BQ_TS` to `BQ_REGN` and violated U1/capacitor courtyards. Treat `BQ_REGN`/`BQ_TS` as a compact HOTROD-package placement pass, not as a generic passive-grid cleanup.
- A 2026-07-25 `BQ_PROG`/`BQ_INT` direct top-layer routing trial was rejected because it crossed the lower charger/passive staging area and caused shorts, solder-mask issues and thermal relief starvation. Route these only after the lower charger support passives are placed deliberately.
- A 2026-07-25 `BQ_BTST2` direct top route and a follow-up two-via escape trial were rejected. The top route shorted/crowded `BQ_PROG`; the via route crowded BATP/PROG pad clearance and crossed existing `I2C_SDA`, `BAT_RAW` and `BQ_TS` corridors. Keep `BQ_BTST2`, C217 and the U1 right-side support passives in the same placement pass.
- 2026-07-28 `BQ_BTST2` dogleg trials showed the top-layer lane between
  `BQ_TS` and `BQ_PROG` is too narrow at the current 0.15 mm minimum trace
  width. Moving the `BQ_TS` via left collided with the accepted `I2C_SDA` and
  `BQ_REGN` escape region, bending `BQ_PROG` below the lane crowded `BQ_INT`,
  and moving C217 near U1 collided with the surrounding `BAT_RAW`,
  `BATP_KELVIN`, `BQ_SDRV`, `BQ_PROG`, `BQ_INT`, R203/R204 and Q3 routes.
- A later 2026-07-28 `BQ_BTST2` pass is accepted. The `BQ_PROG` local trace
  was straightened into R203, and `BQ_BTST2` now uses a legal top-layer dogleg
  from U1 to C217 without new DRC violations.
- A 2026-07-25 lower-edge `BATP_KELVIN` route trial was rejected because the U1-side via crowded neighboring BQ25798 pads and the bottom route crossed existing lower sense/I2C routing. Treat `BATP_KELVIN` as requiring a deliberate U1 escape and sense-routing pass, not a casual bottom-edge route.
- A 2026-07-25 U4-side `UV_NODE`/`OV_NODE`/`LTC_SHDN` divider relocation trial was rejected because it crowded the LTC4365 pins, overlapped the L2 inductor courtyard and shorted the divider nodes into adjacent U4/L2 nets. Rework U4, L2 and the divider corridor together before pulling these protection passives closer.
- A 2026-07-26 `R204` 3.3 V pullup-feed reroute is accepted. It uses a short
  local via into the existing `In2.Cu` 3.3 V spine and clears the top-side U1
  right corridor. Earlier bottom-layer and `In1.Cu` attempts were rejected for
  I2C/USB crowding or crossing `BQ_ACDRV1`.
- The right-edge 3.3 V service leg has also been moved from top copper to
  `In2.Cu`, rejoining the top 3.3 V service route near 90.4, 36.7 mm. This
  removes the x102.4 top-layer 3.3 V spine that blocked USB edge-route trials.
- A 2026-07-25 `BQ_VBUS` Q2/Q3 left-drain loop trial was rejected because top-layer loops around the MOSFET bodies shorted or crossed the adjacent `BQ_ACDRV1`/`BQ_ACDRV2` gate pads. Route the remaining FET drain joins with deliberate copper shapes or a revised FET placement, not a simple around-body trace.
- A 2026-07-25 rectangular `BQ_VBUS` copper-zone trial around Q3 passed DRC but did not connect Q3 pad 3 to pad 5, so it was removed. The selector drain joins need shaped copper or MOSFET placement changes, not a broad rectangular fill.
- A 2026-07-28 RF floorplan correction is accepted. MOD2/E22 was rotated to
  0 degrees so pin 21 ANT faces the left board edge, and J5's draft SMA
  envelope moved to the left edge near the ANT pad. The old E22 digital bus
  fanouts were reworked for the new orientation.
- A 2026-07-28 `E22_RXEN` route is accepted. It uses a short top-layer fanout
  from MOD2 pin 6 to a local via, then a bottom-layer escape to the XIAO D6
  pad, clearing the TPS61088 support-passive pocket without new DRC violations.
- A 2026-07-28 `5V_RADIO` route pass is accepted. U3 VOUT now feeds the E22
  VCC pins through a short top-layer power spine, ties into the output
  feedback/capacitor island, reaches the lower E22 bulk capacitor bank down
  the right side of the module, and connects C503 through the upper
  protection-divider corridor. This removes `5V_RADIO` from the remaining
  ratsnest while keeping DRC clean.
- A 2026-07-28 `BQ_SW2` top-layer escape trial and an internal-layer via
  escape trial both reduced the ratsnest count temporarily but were rejected.
  The top route crowded U1 `BQ_SYS`, `BQ_SDRV`, `BQ_TS` and I2C pads; the
  internal route crossed `BQ_TS`, `BQ_VBUS`, 3.3 V and `BQ_ACDRV2`. A later
  via-in-pad/inner-layer escape also closed the net electrically, but a
  rule-compliant via at U1 pad 26 crowded the adjacent `BQ_SYS` and GND pads.
- A follow-up 2026-07-28 grouped `BQ_SYS`/`BQ_SW2` pocket refactor was also
  rejected. Moving the `BQ_SYS` entry right opened the SW2 ratsnest but
  crowded `BQ_SDRV` and I2C; moving the SW2 via lower-left restored SYS but
  shorted or crowded the accepted SYS spines and I2C lane.
- A later 2026-07-28 `BQ_SW2` right-spine retry and internal via retry were
  rejected. The top route shorted or crossed 3.3 V, `BQ_SDRV`, `BQ_INT` and
  `BQ_BTST2`; the internal route did not reduce the ratsnest count and still
  crossed `BQ_SYS`, 3.3 V and `BQ_TS`. This confirms that `BQ_SW2` needs a
  coordinated `BQ_SYS` entry plus R203/R204/C218 support-lane refactor.
- After the accepted lower `BQ_SYS` entry, a 2026-07-28 `BQ_SW2` B.Cu retry
  was also rejected. It still crowded the new `BQ_SYS` entry via and crossed
  `BQ_USB_SELECTOR_COMMON` plus the accepted B.Cu I2C_SDA service route. The
  next SW2 attempt needs either an I2C/service-route layer swap or a local
  selector-common reroute, not just a different SW2 spine.
- A follow-up 2026-07-28 I2C_SDA layer-swap plus `BQ_SW2` B.Cu retry was
  rejected. Moving I2C_SDA from B.Cu to In1.Cu collided with the accepted
  `BQ_SYS` boost branch and broke SDA continuity through its existing layer
  transitions, while the SW2 via still crowded U1 pad 25/27 and the 3.3 V
  via. Leave I2C_SDA on B.Cu unless its full endpoint/via strategy is
  replanned.
- A 2026-07-28 `BQ_VBUS` U1-to-Q3 bottom-layer bridge trial reduced the
  ratsnest count temporarily but was rejected because it crossed/crowded
  `BQ_STAT`, `BAT_RAW`, I2C_SDA and `BQ_USB_SELECTOR_COMMON`.
- A later 2026-07-28 `BQ_VBUS` U1-to-Q3 internal-layer escape trial was
  rejected. The U1-side via crowded the accepted `BQ_STAT` escape, and the
  internal path crossed I2C, 3.3 V, `BQ_TS` and `BQ_ACDRV2` service routes.
- A follow-up 2026-07-28 grouped `BQ_STAT` slide plus `BQ_VBUS` lower escape
  was also rejected. It opened the U1 VBUS lane only partially and then
  crossed/crowded `BAT_RAW`, `BATP_KELVIN`, `BQ_ACDRV1`, `BQ_ACDRV2`,
  `BQ_BTST1` and the shifted `BQ_STAT` entry. The remaining `BQ_VBUS` route
  needs a broader U1/Q3/L1 support-passive placement refactor, not another
  one-off bridge.
- A 2026-07-25 `SOLAR_PROTECTED` Q1 drain-join trial was rejected. The outside bottom bridge required a top-layer escape that crossed the accepted Q1 gate U-shape; moving the gate U-shape to the right shorted against Q1's no-net thermal/mechanical pad. Treat the Q1 protected-drain join as a FET-footprint/copper-shape pass.
- 2026-07-28 `SOLAR_PROTECTED` U1-entry retry briefly reduced the ratsnest
  count by one but was rejected. The internal route crossed accepted `BAT_RAW`
  and `BQ_SYS`, and the Q2-side via solder-mask-bridged into the selector
  common pad.
- A later 2026-07-28 `SOLAR_PROTECTED` U1-to-Q1 left-side service-route trial
  was rejected. It crossed or crowded `BQ_REGN`, `BQ_ACDRV2`, `BQ_STAT`,
  `BQ_PMID`, `I2C_SDA`, U3 ground/thermal geometry and
  `SOLAR_PROT_COMMON`. The remaining solar-protected U1 entry belongs in the
  same grouped U1/input-selector refactor as `BQ_VBUS` and `USB_VBUS_RAW`.
- A later 2026-07-28 `SOLAR_PROTECTED` U1-to-spine internal trial reduced the
  ratsnest count to 2 but was rejected. The U1-side vertical lane crossed
  `BQ_STAT`, `BAT_RAW` and `BQ_SYS`, while the selector-spine via landed too
  close to the Q2 `BQ_SOLAR_SELECTOR_COMMON` pad. Retry only after moving the
  lower-edge U1 escape and Q1/Q2 selector join as a group.
- A later 2026-07-28 `SOLAR_PROTECTED` split-layer left-edge overpass is
  accepted. It fans out from U1 pad 9, crosses the lower U1 pocket on In2.Cu,
  hops to In1.Cu at x47 before the BATP lane, then returns across the upper
  service corridor and drops into the existing Q1/Q2 protected-output via.
  This removes `SOLAR_PROTECTED` from the current unrouted list while keeping
  DRC clean.
- A 2026-07-25 `BATP_KELVIN` bottom-layer sense-route trial was rejected. The R202-side via collided with the accepted `BAT_RAW` branch and `BQ_TS` route, the bottom span crossed `BQ_STAT`, and the U1-side via crowded `BQ_PROG`. Rework the BQ25798 support-passive fanout before retrying BATP.
- A 2026-07-25 R202 relocation trial for `BATP_KELVIN` was rejected. Moving R202 near U1 collided with the accepted I2C_SDA via corridor and crossed/shorted `BQ_TS`, `BQ_INT` and `BQ_PROG`; keep BATP as part of a coordinated right-side U1 fanout/sense-routing pass.
- A 2026-07-26 two-layer `BATP_KELVIN` sense route is accepted. It uses a short U1 escape, small signal vias, a B.Cu dogleg around the U1/I2C exits, and an In2.Cu hop around the BAT_RAW and NTC corridors before entering R202. This reduced the ratsnest from 14 to 13 without adding DRC errors.
- A 2026-07-26 `BQ_PMID` bridge is accepted. It uses a short lower U1 fanout, a B.Cu route under the charger area, and a top-layer entry into the PMID capacitor bus. A 64.00, 72.45 mm U1-side via clears the accepted `BQ_SW1` escape and reduces the ratsnest from 13 to 12 without adding DRC errors.
- A later 2026-07-25 R202 tight-local relocation at U1 was rejected. The rotated 0603 orientation put the BATP/BAT_RAW pads opposite the intended side, and the placement still overlapped U1 while crowding the accepted `BQ_TS`, `BQ_INT` and `BAT_RAW` vias. Keep R202 out of the U1 pad row until the right-side support-passive cluster is reworked.
- A 2026-07-25 `SOLAR_FUSED` divider-to-U4-backbone bridge trial was rejected because the straight bottom-layer span crossed the accepted SPI_SCK and I2C_SDA backbones. The remaining `SOLAR_FUSED` island needs a placement-aware reroute, not a long bottom trace through the digital corridor.
- A 2026-07-25 local `BQ_REGN` U1 pin-to-pin wrap trial was rejected because the QFN escape crossed neighboring routes and starved nearby thermal relief. The final accepted REGN solution uses the C215/R200 island route plus a short ILIM_HIZ top bridge instead of this wrap.
- A 2026-07-25 `BQ_ACDRV2` top-side gate route trial was rejected because the upper Q3 corridor crossed the accepted I2C_SDA/I2C_SCL fanout near U1. Route the selector gate controls as part of a coordinated U1 lower-edge escape pass.
- Do not force ground traces where a pour/stitching plan is required.

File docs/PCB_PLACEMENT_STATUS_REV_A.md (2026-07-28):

# RoyalNode Rev A PCB Placement Status

## Current Milestone

Milestone `P1a` is in progress.

The PCB now contains generated placement anchors for the major Rev A mechanical blocks and low-risk passive support parts. The placement is generated by:

```text
tools/generate_pcb_placement.py
```

The current board file is:

```text
hardware/kicad/RoyalNode/RoyalNode.kicad_pcb
```

## Board Envelope

The Rev A planning outline is:

```text
97 mm x 87 mm
```

Current edge rectangle:

```text
start: 15 mm, 15 mm
end:   112 mm, 102 mm
```

The outline was expanded from the original 85 x 75 mm scaffold so four real M3 mounting holes can sit in the corners without crowding JST-GH service connectors, the TS/NTC divider, or accepted routing. The board remains a placement scaffold, not a routed PCB and not a fabrication release.

## Generated Placement Anchors

The generated board currently contains:

- 18 major module, connector, power IC, FET, fuse, and inductor anchors.
- 4 M3 non-plated corner mounting-hole anchors.
- 53 staged support-passive anchors from `PASSIVE_CAPTURE_SEED_REV_A.csv`.

The passive anchors are staging placements for footprint/net review, not final routed power-loop placement.
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

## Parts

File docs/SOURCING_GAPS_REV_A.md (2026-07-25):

# RoyalNode Rev A Sourcing Gaps

Generated from `bom/REV_A_LOCKED_CORE_BOM.csv` and `bom/REV_A_LOCKED_PASSIVES.csv`.

This report tracks ordering friction only. It does not change the electrical design.

| Area | Ref/group | Value/part | Missing | Notes |
|---|---|---|---|---|
| core | F1 | 5 A solar input fuse | status locked_candidate | Located immediately after solar XT30 positive; verify time-current behavior against selected 6 V / 20 W panel Isc |

Resolve these gaps before requesting a real PCBA quote. Values marked as locked still need exact stocked manufacturer parts when the manufacturer and MPN are `TBD`.

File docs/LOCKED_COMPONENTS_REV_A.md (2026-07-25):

# 2Watt Project Locked Components, Rev A

## Core ICs and modules

| Function | Locked part | Notes |
|---|---|---|
| MCU module | Seeed Studio XIAO nRF52840, standard | Socketed |
| Radio module | EBYTE E22-900M33S | High-power 915 MHz module |
| Charger/power path | TI BQ25798RQMR | 29-pin VQFN-HR |
| 5 V boost | TI TPS61088RHLR | 20-pin VQFN |
| XIAO reverse-current blocker | TI LM66100DCKR | 1.5 V to 5.5 V, 1.5 A ideal diode |

Rev A intentionally has no dedicated fuel-gauge IC. Battery voltage and charger-state telemetry come from the BQ25798 over I2C.

## Magnetics

| Function | Locked part | Key ratings |
|---|---|---|
| TPS61088 inductor | Coilcraft XAL7030-222MEC | 2.2 uH, 15.1 mOhm max DCR, 18 A saturation, 12.9 A Irms at 40 C rise |
| BQ25798 inductor | Coilcraft XAL7070-222MEC | 2.2 uH, high-current shielded molded inductor |

## Battery temperature sensing

| Function | Locked part/value | Notes |
|---|---|---|
| Battery NTC | Semitec 103AT-2 | 10 kOhm at 25 C, mounted to battery pack |
| TS upper resistor | 5.23 kOhm | REGN to TS |
| TS lower resistor | 30.1 kOhm | TS to NTC node |

The NTC is mandatory for the production assembly. There is no fixed TS bypass, simulated-temperature divider, or bench-test selection network.

## Connectors and sockets

| Function | Locked part/class | Notes |
|---|---|---|
| Solar input | AMASS XT30PW-M | Male right-angle PCB connector; JLC assembly supported, wave solder |
| Battery input | AMASS XT30PW-M | Male right-angle PCB connector; JLC assembly supported, wave solder |
| XIAO socket, left | LXWCONN 254PM-1x7P-V | 1x7, 2.54 mm, vertical female, 8.5 mm body, gold contact, -40 to +105 C; JLC C53202181 |
| XIAO socket, right | LXWCONN 254PM-1x7P-V | Same part as left socket |
| XIAO mating headers | 1x7, 2.54 mm male pin headers on XIAO | Header pin length must be verified against socket engagement before assembly release |
| XIAO power receptacle | JST SM02B-GHS-TB(LF)(SN) | 2-pin, 1.25 mm, board-mounted SMT JST-GH |
| XIAO cable housing | JST GHR-02V-S | Two-wire removable lead |
| Battery NTC PCB header | JST SM02B-GHS-TB(LF)(SN) | 2-pin, 1.25 mm, board-mounted SMT JST-GH |
| Battery NTC cable housing | JST GHR-02V-S | Mating 2-pin JST-GH housing; exact crimp terminal must be selected/verified before harness release |
| RF output | Molex 0732511150 / 732511150 | Standard-polarity 50-ohm SMA female edge mount for 1.60 mm PCB; JLCPCB C841205 |

## Indicator LED

| Function | Locked part | Notes |
|---|---|---|
| Charge/status LED | Hubei KENTO Elec KT-0603R | Red 0603 SMT LED, JLCPCB C2286, driven from the BQ25798 STAT sink path through R207 |

The previous mixed low-current connector plan is removed from Rev A. J3 and J4 now use the same JST-GH 2-pin family so internal low-current harnesses share one latch style, pitch and crimp ecosystem. The NTC connector is a charge-safety input rather than deployed MeshCore telemetry.

Board-side XT30 gender is deliberately male. The mating battery and solar harnesses use female XT30 connectors so energized harness contacts are recessed rather than exposed male bullets. Both board XT30s must be distinctly silkscreened BATTERY and SOLAR because the connectors are mechanically identical.

JLCPCB lists genuine AMASS XT30PW-M as a supported wave-solder assembly part. Stock is dynamic and may require pre-order/consignment at build time. The XIAO sockets are also wave-solder parts and may require a fixture.

## BQ25798 locked startup values

- Cell configuration: 1S
- Battery class: protected 3.6/3.7 V nominal Li-ion/LiPo, 4.20 V maximum
- PROG resistor: 4.7 kOhm, 1%
- /CE: tied low
- Switching frequency: 750 kHz
- Inductor: 2.2 uH, XAL7070-222MEC
- Maximum firmware charge current: 2.0 A
- D+ and D-: not used; leave unconnected
- TS network: Semitec 103AT-2 with 5.23 kOhm / 30.1 kOhm network
- Charge temperature policy target: suspend below 0 C and at/above 45 C
- Watchdog disabled by firmware
- ADC enabled by firmware
- MPPT enabled/restored by firmware for solar operation

## BQ25798 capacitor BOM

### Main 10 uF power capacitors

Use one common production part for VBUS, PMID, SYS and BAT:

- TDK C3225X7R1H106KT000E
- 10 uF, 50 V, X7R, +/-10%, 1210
- JLCPCB C432929

Population:

- VBUS: 2 x 10 uF
- PMID: 3 x 10 uF
- SYS: 5 x 10 uF
- BAT: 2 x 10 uF

DC-bias audit:

- TI requires at least 2 uF effective VBUS capacitance, 4 uF effective PMID capacitance, 6 uF effective SYS capacitance and 3 uF effective BAT capacitance.
- TDK's characterization graph for C3225X7R1H106K250AC, the same 10 uF / 50 V / X7R / 1210 electrical construction family, shows roughly 45% nominal capacitance remaining at about 25 V DC bias and very small loss at 4.2 V.
- Even using a conservative ~4.5 uF per capacitor at 25 V before tolerance, the VBUS pair provides about 9 uF and the PMID trio about 13.5 uF, both comfortably above TI minimum effective-capacitance requirements.
- At the 1S battery/SYS voltage region, five SYS capacitors and two BAT capacitors retain very large margin over TI's 6 uF and 3 uF minimums.
- The 50 V rating also provides comfortable voltage-rating margin above the approximately 25 V solar overvoltage threshold.

### High-frequency 100 nF bypass capacitors

Use:

- TDK CGA2B3X7R1H104K050BD
- 100 nF, 50 V, X7R, +/-10%, 0402
- JLCPCB C2167088

Population:

- VBUS: 1 x 100 nF, closest capacitor to VBUS/GND
- PMID: 1 x 100 nF, closest capacitor to PMID/GND
- SYS: 1 x 100 nF, closest capacitor to SYS/GND

The 50 V rating is deliberately common across these locations so the same bypass part can be used on the high-voltage input nodes and the low-voltage SYS node.

### REGN capacitor

Use:

- TDK C3216X7R1E475K160AC
- 4.7 uF, 25 V, X7R, +/-10%, 1206
- production-status part

Population:

- REGN: 1 x 4.7 uF to power ground, placed immediately beside the IC

The 25 V rating is substantially above the REGN operating voltage and provides better DC-bias margin than a minimally rated 10 V part.

### Bootstrap capacitors

Use:

- TDK C1005X7R1H473M050BB
- 47 nF, 50 V, X7R, +/-20%, 0402
- JLCPCB C3846080

Population:

- BTST1-SW1: 1 x 47 nF
- BTST2-SW2: 1 x 47 nF

TI requires 10 V or higher bootstrap-capacitor rating; 50 V is intentionally conservative and the small capacitance has negligible DC-bias concern in this package/rating.

### SDRV capacitor

Use:

- TDK C1005C0G1H102J050BA
- 1 nF, 50 V, C0G, +/-5%, 0402
- JLCPCB C2182279

Population:

- SDRV-GND: 1 x 1 nF

C0G is used because the 1 nF value should remain essentially invariant with DC bias and temperature.

## BQ25798 locked supporting values

- BATP: 100 Ohm series resistor on dedicated Kelvin trace
- ILIM_HIZ: tied to REGN
- INT: 10 kOhm pullup to 3.3 V, not routed to XIAO; firmware polls over I2C

## TPS61088 production-locked values

- Output: 5.0 V nominal
- Continuous design target: 2 A
- Inductor: Coilcraft XAL7030-222MEC, 2.2 uH
- Feedback divider: 176 kOhm top / 56.0 kOhm bottom, 0.1%
- Frequency resistor: 330 kOhm from FSW to SW
- Current-limit resistor: 100 kOhm to AGND
- Compensation: 20.0 kOhm and 4.7 nF
- Soft-start: 47 nF
- VCC bypass: 2.2 uF
- BOOT capacitor: 100 nF from BOOT to SW
- MODE: floating for PFM/light-load efficiency
- EN: XIAO-controlled, with 100 kOhm pulldown
- No mode jumper, test selector, or other bench-only configuration feature

## TPS61088 and E22 capacitor BOM

### Common 22 uF power capacitor

Use:

- Murata GRM31CZ71C226ME15L
- 22 uF, 16 V, X7R, +/-20%, 1206
- JLCPCB C909845

Population:

- TPS61088 VIN: 2 x 22 uF
- E22 local 5 V rail: 2 x 22 uF

The 16 V rating is intentionally above the 4.2 V battery input and 5 V E22 rail to reduce DC-bias loss compared with a 10 V-rated 22 uF part. JLCPCB currently lists substantial stock for this part.

### TPS61088 output capacitors

Use:

- TDK C3225X5R1A476MT000E
- 47 uF, 10 V, X5R, +/-20%, 1210
- JLCPCB C76680

Population:

- TPS61088 VOUT: 2 x 47 uF

Rationale:

- TI recommends low-ESR ceramic output capacitance and explicitly warns that effective capacitance under DC bias must be considered.
- A TI engineer reviewed a near-identical 2.5-4.2 V to 5 V / 2 A TPS61088 application using 2 x 47 uF, 1210, 10 V ceramic output capacitors and accepted that output-capacitor class while recommending the 20 kOhm / 4.7 nF compensation network used by Rev A.
- C3225X5R1A476MT000E is a current JLCPCB assembly-library 47 uF / 10 V / X5R / 1210 part with current stock.
- Final production validation still measures 5 V transient droop under repeated E22 full-power transmit bursts; that is validation of the assembled power stage, not a placeholder BOM decision.

### TPS61088 VIN high-frequency bypass

Use the existing common BQ bypass part:

- TDK CGA2B3X7R1H104K050BD
- 100 nF, 50 V, X7R, 0402
- JLCPCB C2167088

Population:

- TPS61088 VIN: 1 x 100 nF immediately beside VIN/PGND

### E22 1 uF local bypass

Use:

- Murata GCM188R71C105KA64D
- 1 uF, 16 V, X7R, +/-10%, 0603
- JLCPCB C161212

Population:

- E22 5 V rail: 1 x 1 uF close to the module VCC pins

### E22 100 nF local bypass

Use:

- Murata GCJ188R71C104KA01D
- 100 nF, 16 V, X7R, +/-10%, 0603
- JLCPCB C710619

Population:

- E22 5 V rail: multiple 100 nF capacitors, one adjacent to each practical local VCC/ground entry region of the module footprint

### E22 bulk capacitor

Use:

- Panasonic 10SVPC330M
- 330 uF, 10 V, polymer aluminum, +/-20%
- ESR: 19 mOhm at 100 kHz
- ripple-current rating: 3.46 A at 100 kHz
- operating temperature: -55 C to +105 C
- endurance: 2000 h at 105 C
- SMD can: 8 mm diameter x 6.9 mm maximum height
- JLCPCB C347574

Population:

- E22 local 5 V rail: 1 x 330 uF, placed immediately beside the module power-entry region but outside the ANT/SMA RF keepout

This part is selected instead of an anonymous generic electrolytic because its manufacturer/JLC data explicitly define ESR, ripple current, temperature range and lifetime. Its 6.9 mm height is also substantially more compact than many 330-470 uF polymer alternatives while retaining very low ESR.

## Parts intentionally not fitted

- MAX17048 or other dedicated fuel gauge
- Power button controller
- eFuse
- Radio load switch
- SWD connector
- Extra LEDs beyond charge LED
- TS bypass or simulated-temperature network
- PFM/PWM mode-selection jumper
- Bench-test-only features

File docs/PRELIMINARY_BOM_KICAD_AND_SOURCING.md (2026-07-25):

# 2Watt Project Preliminary BOM, KiCad and Sourcing Review

## Purpose

This is a historical sourcing sketch, not the current Rev A implementation BOM. Use `bom/REV_A_LOCKED_CORE_BOM.csv`, `bom/REV_A_LOCKED_PASSIVES.csv`, `docs/LOCKED_COMPONENTS_REV_A.md` and the generated KiCad files for current implementation. Rows below may mention parts that were removed from the active design, such as MAX17048, eFuse/load-switch circuitry and a power button.

## Core parts

| Ref | Function | Preferred part | Package / form | Qty | Status |
|---|---|---|---|---:|---|
| U1 | MCU module | Seeed Studio XIAO nRF52840, standard | 21 x 17.8 mm module | 1 | Selected |
| U2 | 2 W LoRa radio | EBYTE E22-900M33S | 38.5 x 24 mm castellated module | 1 | Selected |
| U3 | Solar + USB charger and power path | TI BQ25798RQMR | 29-pin 4 x 4 mm VQFN-HR | 1 | Selected for Rev A |
| U4 | 1S-to-5 V radio boost | TI TPS61088RHLR | 20-pin 4.5 x 3.5 mm VQFN | 1 | Selected |
| U5 | Battery fuel gauge | ADI MAX17048G+T10 | 8-TDFN-EP 2 x 2 mm | 1 | Selected |
| U6 | Radio rail load disconnect | TBD eFuse/load switch | High-current SMD | 1 | Open |
| U7 | XIAO supply path | TBD low-Iq converter/power mux | SMD | 1-2 | Open |
| U8 | Push-button controller | TBD latch/controller | SMD | 1 | Open |

## Connectors and controls

| Ref | Function | Preferred class / candidate | Qty | Status |
|---|---|---|---:|---|
| J1 | Solar input | Board-mounted AMASS XT30, keyed/oriented for solar | 1 | Exact MPN open |
| J2 | Battery input | Board-mounted AMASS XT30, different gender/orientation | 1 | Exact MPN open |
| J3 | RF output | Board-edge 50-ohm SMA female; Molex 0732512440 is a sourcing candidate | 1 | Candidate |
| J4 | SWD service | JST-GH 2.0 mm, 4-pin SMT, side-entry preferred | 1 | Exact MPN open |
| SW1 | User power button | Sealed or enclosure-actuated momentary switch | 1 | Mechanical selection open |
| LED1 | Charging | Low-current LED from charger status logic | 1 | Generic |
| LED2 | Full/standby | Low-current LED from charger status logic | 1 | Generic |

## Charger power-stage support parts

BQ25798 integrates the main four-switch buck-boost power stage and battery FET, but still requires external parts. Final choices must follow the latest TI datasheet/EVM design.

- charger inductor, value/current rating per 1S 2-3 A target
- input capacitors rated for at least the selected solar maximum and transient margin
- system and battery ceramic/bulk capacitors
- thermistor network matched to the battery NTC
- solar input TVS
- solar input fuse or resettable fuse
- reverse-polarity/input blocking FET arrangement
- dual-input selector FETs if the optional selector is implemented
- I2C pull-ups to 3.3 V
- charger interrupt/status pull-ups and LED resistors

## TPS61088 support parts

- approximately 1 uH shielded power inductor, final Isat/DCR from TI calculation
- input ceramics plus low-ESR bulk capacitor near the converter
- output ceramics plus low-ESR bulk capacitor near E22 VCC pins
- feedback divider for 5.0 V
- switching-frequency resistor
- current-limit resistor
- soft-start capacitor
- compensation/layout parts per datasheet
- output load-disconnect/eFuse stage
- optional snubber footprint for EMI tuning

## RF and layout parts

- 0-ohm RF link or tuning footprint between E22 ANT and SMA
- optional unpopulated pi-matching footprints for RF tuning
- dense ground-via fence along the RF trace
- ESD protection only if a suitably low-capacitance RF device is selected and validated at 915 MHz
- 4-layer controlled-impedance FR-4 recommended

## KiCad library availability

| Part | Symbol availability | Footprint availability | Action |
|---|---|---|---|
| XIAO nRF52840 | Official Seeed symbol available | Official Seeed footprint and KiCad project available | Import Seeed library and verify bottom-pad mapping |
| E22-900M33S | Not expected in stock KiCad library | Custom castellated footprint required; EasyEDA/JLC model exists | Create and independently verify against EBYTE drawing |
| BQ25798RQMR | Not confirmed in stock KiCad library | Generic/custom 29-pin VQFN-HR footprint likely required | Import vendor ECAD or build from TI package drawing |
| TPS61088RHLR | Not confirmed in stock KiCad library | Generic 20-pin VQFN package can be adapted | Build/verify thermal pad and paste pattern from TI drawing |
| MAX17048G+T10 | May not be in stock library | Generic 2 x 2 mm 8-TDFN-EP footprint available or adaptable | Verify exposed pad and pin-1 orientation |
| XT30 PCB connector | AMASS connector footprints may exist depending on KiCad version | Exact board-mount variant must match selected MPN | Do not use a generic XT30 footprint without mechanical check |
| JST-GH 4-pin SMT | Generic symbol available | Official KiCad JST-GH footprints generally available | Select exact side/top-entry MPN first |
| Board-edge SMA | Generic connector symbol available | Several KiCad coax footprints exist, but exact launch geometry is stack-up specific | Build or modify footprint from connector datasheet |

## Current supplier check

Inventory changes constantly; these observations are a snapshot from July 2026.

- E22-900M33S: listed in JLCPCB's parts library as an extended part and available for SMT assembly.
- TPS61088RHLR: available from DigiKey Canada and Mouser Canada.
- BQ25798RQMR: available from Mouser Canada; also an active TI part.
- MAX17048G+T10: available from DigiKey Canada.
- XIAO nRF52840 standard: available as a Seeed 3-pack through DigiKey Canada.
- Board-edge SMA: Molex 0732512440 is currently stocked by DigiKey Canada and has vendor ECAD models.

## PCB manufacturer fit

### JLCPCB

Good fit for Rev A if the design uses standard assembly or a mixed strategy.

- E22-900M33S is already in the JLCPCB parts library.
- Standard PCBA supports single- or double-sided SMT/THT and fine-pitch parts.
- Controlled impedance is available on multilayer boards.
- XIAO, XT30 and SMA may be hand-installed or consigned if not machine-friendly/in-library.
- E22-900M33S / MOD2 is planned as a factory-installed PCBA item using JLCPCB/LCSC part `C22399506`, not as a loose or hand-installed post-delivery module.

Recommended JLC strategy:

1. JLC assembles BQ25798, TPS61088, MAX17048 and small passives.
2. JLC assembles the E22 if inventory remains available.
3. Hand-solder or consign the XIAO, XT30 connectors and SMA for the first five boards.

### PCBWay

Also a good fit, especially when consigned or mixed-source parts are needed.

- supports SMT, THT and mixed assembly
- supports turnkey, consigned and partial-turnkey sourcing
- can source from authorized distributors with approval
- useful if exact XT30/SMA/XIAO parts are difficult to match in JLC's library

## Recommended Rev A manufacturing route

Use a 4-layer impedance-controlled PCB with ENIG. Order the first Rev A boards as an engineering-validation build with all fine-pitch/QFN, small SMD parts, and the E22/MOD2 factory assembled. Use the JLCPCB/LCSC `C22399506` EasyEDA footprint path for the E22 because no loose physical module is available before fabrication; perform the physical E22 fit check as first-article inspection after the assembled board arrives.

## Parts not ready to purchase

Do not order these until schematic calculations are complete:

- charger inductor and surrounding BQ25798 power-stage passives
- TPS61088 inductor/current-limit/frequency/soft-start parts
- radio rail eFuse/load disconnect
- XIAO supply converter/power mux
- power-button controller
- input TVS/fuse/reverse-protection parts
- exact XT30 and JST-GH connector variants
- battery pack and NTC

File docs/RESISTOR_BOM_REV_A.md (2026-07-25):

# RoyalNode Rev A Resistor BOM

## Status

This document captures resistor values that have been re-verified against current manufacturer datasheets/reference designs before KiCad capture. Generic pull-ups/pull-downs use standard 1% 0603 parts; threshold and feedback networks use tighter tolerance where noted.

## BQ25798

### PROG

- Function: set POR battery cell count and switching frequency
- Value: 4.70 kOhm
- Tolerance: 1%
- Package: 0603
- Verified behavior: BQ25798 Rev. C Table 7-1 specifies 4.7 kOhm for 1S / 750 kHz.
- Production part: Walsin WR06X4701FTL, JLC C163914

This confirms the existing RoyalNode 4.7 kOhm value. The 6.04 kOhm value shown in some TI application drawings is for a different PROG configuration and must not replace the Rev A 1S/750 kHz setting.

### Battery TS network

TI support explicitly recommends the BQ25798 EVM values for a Semitec 103AT-2:

- RT1: 5.23 kOhm, 0.1%
- RT2: 30.1 kOhm, 0.1%

Production parts:

- RT1: KOA RN73H1JTTD5231B25, 5.23 kOhm, 0.1%, 25 ppm/C, 0603, JLC C4047317
- RT2: Stackpole RNCF0603BKE30K1, 30.1 kOhm, 0.1%, 25 ppm/C, 0603, JLC C4314708

### I2C and control pull-ups

Use one common production part:

- Yageo RC0603FR-0710KL
- 10 kOhm, 1%, 0603
- JLC C98220

Population:

- SDA pull-up: 10 kOhm
- SCL pull-up: 10 kOhm
- INT pull-up: 10 kOhm; INT is not routed to the XIAO

Only one SDA/SCL pull-up pair is fitted on the carrier.

### BATP Kelvin resistor

- 100 Ohm, 1%, 0603
- Production part: Walsin MR06X1000FTL, JLC C327825
- routed in series only with the dedicated BATP Kelvin sense trace

## LTC4365 solar threshold divider

Locked values:

- R3: 1.78 MOhm
- R2: 180 kOhm
- R1: 40.2 kOhm

Production parts:

- R3: TBD stocked 1.78 MOhm, 1%, 0603
- R2: TBD stocked 180 kOhm, 0.1% preferred, 0603
- R1: TBD stocked 40.2 kOhm, 0.1% preferred, 0603

The 1.78 MOhm / 180 kOhm / 40.2 kOhm chain is the 6 V-panel candidate, targeting roughly 4.54 V UV cutoff and roughly 24.9 V OV cutoff before threshold tolerance and hysteresis. Normal deployed panel cold-weather Voc must remain below the BQ25798 recommended operating limit; the approximately 25 V LTC4365 threshold is a protection ceiling, not a normal operating target.

## TPS61088

### Feedback divider

- RFB_TOP: 176 kOhm, 0.1%, 0603
- RFB_BOTTOM: 56.0 kOhm, 0.1%, 0603

Production parts:

- 176 kOhm: KOA RN731JTTD1763B50, JLC C4291479
- 56.0 kOhm: Yageo RP0603BRD0756KL, JLC C6196204

The divider produces approximately 4.99 V nominal with the TPS61088 1.204 V feedback reference.

### Current limit

- RILIM: 100 kOhm, 1%, 0603
- TPS61088 Rev. D Equation 6 gives approximately 11.9 A typical peak-current limit for 100 kOhm.
- Production part: Yageo RC0603FR-07100KL, JLC C14675

### Frequency-setting resistor

- RFREQ: 330 kOhm, 1%, 0603
- Connection: FSW to SW, not FSW to ground
- Production part: Viking Tech ARG03FTC3303, 25 ppm/C, JLC C217968

### Compensation

- RCOMP: 20.0 kOhm, 1%, 0603
- Production part: Vishay CRCW060320K0FKEA, JLC C844923
- CCOMP remains 4.7 nF and is handled in the capacitor BOM

### EN default state

- TPS61088 EN pulldown: 100 kOhm, 1%, 0603
- Production part: Yageo RC0603FR-07100KL, JLC C14675

## Charge/status LED

### LED

- Everlight 19-217/R6C-AL1M2VY/3T
- red, 0603
- nominal forward voltage approximately 1.95 V
- rated forward current 5 mA
- operating temperature -40 C to +85 C
- JLC C72044

### Series resistor

- 2.2 kOhm, 1%, 0603
- Production part: Walsin WR06X2201FTL, JLC C163872

Topology:

```text
3V3 -> LED -> 2.2 kOhm -> BQ25798 STAT
```

At approximately 3.3 V supply and about 1.95 V LED forward voltage, nominal LED current is roughly 0.6 mA. This is intentionally far below the LED's 5 mA rating and the BQ25798 STAT sink capability.

## Generic logic resistors

- 10 kOhm: Yageo RC0603FR-0710KL, JLC C98220
- 100 kOhm: Yageo RC0603FR-07100KL, JLC C14675
- 100 Ohm: Walsin MR06X1000FTL, JLC C327825
- 2.2 kOhm: Walsin WR06X2201FTL, JLC C163872

All are 0603 and 1% unless otherwise stated.

## Resistor BOM status

The resistor selection is closed for schematic capture. Any substitution must maintain resistance, tolerance, voltage rating, power rating and temperature range appropriate to the original location.

The remaining pin-level audit will determine whether the E22 module needs any additional explicit external logic pull-downs beyond the current control scheme; if so, use the common 10 kOhm 1% part unless the EBYTE datasheet requires another value.

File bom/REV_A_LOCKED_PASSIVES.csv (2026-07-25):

Reference | Quantity | Value | Manufacturer | Manufacturer Part Number | Description | Package Or Form | Assembly Notes | Status
C_BQ_VBUS | 2 | 10 uF 50 V X7R | Tdk | C3225X7R1H106KT000E | BQ25798 VBUS capacitors | 1210 | JLCPCB C432929 | locked_common_part
C_BQ_PMID | 3 | 10 uF 50 V X7R | Tdk | C3225X7R1H106KT000E | BQ25798 PMID capacitors | 1210 | JLCPCB C432929 | locked_common_part
C_BQ_SYS | 5 | 10 uF 50 V X7R | Tdk | C3225X7R1H106KT000E | BQ25798 SYS capacitors | 1210 | JLCPCB C432929 | locked_common_part
C_BQ_BAT | 2 | 10 uF 50 V X7R | Tdk | C3225X7R1H106KT000E | BQ25798 BAT capacitors | 1210 | JLCPCB C432929 | locked_common_part
C_BQ_HF | 3 | 100 nF 50 V X7R | Tdk | CGA2B3X7R1H104K050BD | BQ25798 VBUS/PMID/SYS high-frequency bypass | 0402 | JLCPCB C2167088 | locked_common_part
C_REGN | 1 | 4.7 uF 25 V X7R | Tdk | C3216X7R1E475K160AC | BQ25798 REGN capacitor | 1206 | Place immediately beside U1 REGN | locked
C_BTST | 2 | 47 nF 50 V X7R | Tdk | C1005X7R1H473M050BB | BQ25798 bootstrap capacitors | 0402 | JLCPCB C3846080 | locked_common_part
C_SDRV | 1 | 1 nF 50 V C0G | Tdk | C1005C0G1H102J050BA | BQ25798 SDRV capacitor | 0402 | JLCPCB C2182279 | locked
R_LTC_UVOV_R3 | 1 | 1.78 MOhm 1% | Yageo | AA0603FR-071M78L | LTC4365 UV/OV divider top resistor for 6 V solar panel class | 0603 | JLCPCB C2100158 | locked
R_LTC_UVOV_R2 | 1 | 180 kOhm 0.1% | Yageo | RT0603BRE07180KL | LTC4365 UV/OV divider middle resistor for 6 V solar panel class | 0603 | JLCPCB C136958 | locked
R_LTC_UVOV_R1 | 1 | 40.2 kOhm 0.1% | Vishay Intertech | MCT06030E4022BP500 | LTC4365 UV/OV divider bottom resistor | 0603 | JLCPCB C1713642 | locked
R_LTC_SHDN_PULLUP | 1 | 100 kOhm | Yageo | RC0603FR-07100KL | LTC4365 SHDN pullup branch to VIN | 0603 | JLCPCB C14675 | locked
C_TPS_VIN | 2 | 22 uF 16 V X7R | Murata | GRM31CZ71C226ME15L | TPS61088 VIN capacitors | 1206 | JLCPCB C909845 | locked_common_part
C_E22_22U | 2 | 22 uF 16 V X7R | Murata | GRM31CZ71C226ME15L | E22 local 5 V rail ceramic capacitors | 1206 | JLCPCB C909845 | locked_common_part
C_TPS_VOUT | 2 | 47 uF 10 V X5R | Tdk | C3225X5R1A476MT000E | TPS61088 VOUT capacitors | 1210 | JLCPCB C76680 | locked
C_TPS_VIN_HF | 1 | 100 nF 50 V X7R | Tdk | CGA2B3X7R1H104K050BD | TPS61088 VIN high-frequency bypass | 0402 | JLCPCB C2167088 | locked_common_part
C_E22_1U | 1 | 1 uF 16 V X7R | Murata | GCM188R71C105KA64D | E22 local bypass | 0603 | JLCPCB C161212 | locked
C_E22_HF | 2 | 100 nF 16 V X7R | Murata | GCJ188R71C104KA01D | E22 local high-frequency bypass | 0603 | JLCPCB C710619 | locked_common_part
C_E22_BULK | 1 | 330 uF 10 V polymer | Panasonic | 10SVPC330M | E22 local bulk capacitor | SMD polymer can 8 x 6.9 mm | JLCPCB C347574 | locked
R_TS_UPPER | 1 | 5.23 kOhm 1% | KOA | RN73H1JTTD5231B25 | BQ25798 REGN-to-TS resistor | 0603 | JLCPCB C4047317 | locked
R_TS_LOWER | 1 | 30.1 kOhm 1% | Stackpole | RNCF0603BKE30K1 | BQ25798 TS-to-NTC node resistor | 0603 | JLCPCB C4314708 | locked
R_BATP | 1 | 100 Ohm | Walsin | MR06X1000FTL | BQ25798 BATP Kelvin series resistor | 0603 | JLCPCB C327825 | locked
R_PROG | 1 | 4.70 kOhm 1% | Walsin | WR06X4701FTL | BQ25798 PROG resistor | 0603 | JLCPCB C163914 | locked
R_INT_PULLUP | 1 | 10 kOhm | Yageo | RC0603FR-0710KL | BQ25798 INT pullup to 3V3 | 0603 | JLCPCB C98220; not routed to MCU | locked
R_I2C_PULLUP | 2 | 10 kOhm | Yageo | RC0603FR-0710KL | BQ25798 SDA/SCL pullups to 3V3 | 0603 | JLCPCB C98220 | locked
CHG_LED_RES | 1 | 2.2 kOhm 1% | Walsin | WR06X2201FTL | BQ25798 charge LED series resistor | 0603 | JLCPCB C163872 | locked
R_TPS_FB_TOP | 1 | 176 kOhm 0.1% | KOA | RN731JTTD1763B50 | TPS61088 feedback top resistor | 0603 | JLCPCB C4291479 | locked
R_TPS_FB_BOTTOM | 1 | 56.0 kOhm 0.1% | Yageo | RP0603BRD0756KL | TPS61088 feedback bottom resistor | 0603 | JLCPCB C6196204 | locked
R_TPS_FSW | 1 | 330 kOhm | Viking Tech | ARG03FTC3303 | TPS61088 frequency resistor | 0603 | JLCPCB C217968 | locked
R_TPS_ILIM | 1 | 100 kOhm | Yageo | RC0603FR-07100KL | TPS61088 current-limit resistor | 0603 | JLCPCB C14675 | locked
R_TPS_COMP | 1 | 20.0 kOhm | Vishay | CRCW060320K0FKEA | TPS61088 compensation resistor | 0603 | JLCPCB C844923 | locked
C_TPS_COMP | 1 | 4.7 nF 50 V X7R | FH (Guangdong Fenghua Advanced Tech) | 0603B472K500NT | TPS61088 compensation capacitor | 0603 | JLCPCB C53987 | locked
C_TPS_SS | 1 | 47 nF 50 V X7R | Samsung Electro-Mechanics | CL10B473KB8NNNC | TPS61088 soft-start capacitor | 0603 | JLCPCB C1622 | locked
C_TPS_VCC | 1 | 2.2 uF 25 V X7R | Tdk | C2012X7R1E225K125AB | TPS61088 VCC bypass | 0805 | JLCPCB C2170308 | locked
C_TPS_BOOT | 1 | 100 nF 50 V X7R | Yageo | CC0603KRX7R9BB104 | TPS61088 BOOT capacitor | 0603 | JLCPCB C14663 | locked
R_TPS_EN_PD | 1 | 100 kOhm | Yageo | RC0603FR-07100KL | TPS61088 EN pulldown | 0603 | JLCPCB C14675 | locked

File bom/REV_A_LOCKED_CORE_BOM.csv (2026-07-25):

Reference | Quantity | Manufacturer | Manufacturer Part Number | Description | Package Or Form | Assembly Notes | Status
MOD1 | 1 | Seeed Studio | XIAO nRF52840 standard | Socketed nRF52840 MCU module | 21 x 17.8 mm module | Install in two 1x7 sockets; XIAO underside BAT/GND powered by J3 harness | locked
MOD2 | 1 | EBYTE | E22-900M33S | 33 dBm 915 MHz LoRa module | 38.5 x 24.0 mm castellated module | Pin 21 routes directly to SMA GCPW; no U.FL pigtail in Rev A | locked
U1 | 1 | Texas Instruments | BQ25798RQMR | 1S solar/USB buck-boost charger and power-path controller | RQM 29-pin VQFN-HR / HOTROD | Footprint must match TI RQM0029A; generic QFN not allowed | locked
U2 | 1 | Texas Instruments | LM66100DCKR | Ideal diode / reverse-current blocker | DCK 6-pin SC-70 | CE connects to VOUT; ST connects to GND | locked
U3 | 1 | Texas Instruments | TPS61088RHLR | High-current 1S-to-5 V synchronous boost converter | RHL 20-pin VQFN + exposed pad | Exposed pad is pad 21 PGND; footprint must match TI RHL0020A | locked
U4 | 1 | Analog Devices | LTC4365ITS8-1#TRMPBF | UV/OV/reverse input protection controller | TS8 8-pin TSOT-23 | SHDN pulled to VIN through 100 kOhm; FAULT NC in Rev A | locked
Q1 | 1 | Infineon | ISA170170N04LMDSXTMA1 | Dual N-channel MOSFET for solar protection back-to-back pair | PG-DSO-8 | Driven by LTC4365 GATE | locked
Q2 | 1 | Infineon | ISA170170N04LMDSXTMA1 | Dual N-channel MOSFET for BQ solar input selector | PG-DSO-8 | Driven by BQ25798 ACDRV1 | locked
Q3 | 1 | Infineon | ISA170170N04LMDSXTMA1 | Dual N-channel MOSFET for BQ USB input selector | PG-DSO-8 | Driven by BQ25798 ACDRV2 | locked
L1 | 1 | Coilcraft | XAL7070-222MEC | 2.2 uH charger inductor | Shielded molded inductor | Use Coilcraft recommended land pattern | locked
L2 | 1 | Coilcraft | XAL7030-222MEC | 2.2 uH boost inductor | Shielded molded inductor | Use Coilcraft recommended land pattern | locked
J1 | 1 | AMASS | XT30PW-M | Solar input power connector | Right-angle PCB male XT30 | Silkscreen SOLAR; mating harness uses female XT30 | locked
J2 | 1 | AMASS | XT30PW-M | Battery input power connector | Right-angle PCB male XT30 | Silkscreen BATTERY; mating harness uses female XT30 | locked
J3 | 1 | JST | SM02B-GHS-TB(LF)(SN) | XIAO battery harness connector | 2-pin 1.25 mm SMT JST-GH | Wires to XIAO underside BAT/GND pads | locked
J4 | 1 | JST | SM02B-GHS-TB(LF)(SN) | Battery NTC connector | 2-pin 1.25 mm SMT JST-GH | Pin 1 NTC_SENSE; pin 2 GND; battery harness uses GHR-02V-S housing | locked
J5 | 1 | Molex | 0732511150 | 50 ohm standard-polarity SMA female edge launch | 1.60 mm PCB edge mount | Use exact Molex launch; merge with final 50 ohm GCPW geometry | locked
J6 | 1 | JST | SM04B-GHS-TB(LF)(SN) | Optional BME680/environmental I2C connector | 4-pin 1.25 mm SMT JST-GH | Pinout 3V3/GND/SDA/SCL; MeshCore-supported environmental telemetry only | optional
F1 | 1 | Littelfuse | 0483005.DR | 5 A solar input fuse | SMD 483-series 1206 fuse | Located immediately after solar XT30 positive; verify time-current behavior against selected 6 V / 20 W panel Isc | locked_candidate
TH1 | 1 | Semitec | 103AT-2 | 10 kOhm battery-mounted NTC | Thermistor on battery harness | Required for production; no TS bypass network | locked
D1 | 1 | Hubei KENTO Elec | KT-0603R | Low-current red charge LED | 0603 SMD LED | JLCPCB C2286; driven by BQ25798 STAT sink path | locked

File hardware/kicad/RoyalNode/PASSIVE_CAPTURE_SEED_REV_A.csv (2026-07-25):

Reference | Source Group | Value | Pin 1 Net | Pin 2 Net | Footprint | Notes
R100 | R_LTC_UVOV_R3 | 1.78 MOhm 1% | SOLAR_FUSED | UV_NODE | Resistor_SMD:R_0603_1608Metric | LTC4365 UV/OV divider top resistor for 6 V panel class
R101 | R_LTC_UVOV_R2 | 180 kOhm 0.1% | UV_NODE | OV_NODE | Resistor_SMD:R_0603_1608Metric | LTC4365 UV/OV divider middle resistor for 6 V panel class
R102 | R_LTC_UVOV_R1 | 40.2 kOhm 0.1% | OV_NODE | GND | Resistor_SMD:R_0603_1608Metric | LTC4365 UV/OV divider bottom resistor
R103 | R_LTC_SHDN_PULLUP | 100 kOhm | SOLAR_FUSED | LTC_SHDN | Resistor_SMD:R_0603_1608Metric | LTC4365 SHDN pullup branch to VIN
C200 | C_BQ_VBUS | 10 uF 50 V | BQ_VBUS | GND | Capacitor_SMD:C_1206_3216Metric | BQ25798 VBUS bulk capacitor 1
C201 | C_BQ_VBUS | 10 uF 50 V | BQ_VBUS | GND | Capacitor_SMD:C_1206_3216Metric | BQ25798 VBUS bulk capacitor 2
C202 | C_BQ_PMID | 10 uF 50 V | BQ_PMID | GND | Capacitor_SMD:C_1206_3216Metric | BQ25798 PMID capacitor 1
C203 | C_BQ_PMID | 10 uF 50 V | BQ_PMID | GND | Capacitor_SMD:C_1206_3216Metric | BQ25798 PMID capacitor 2
C204 | C_BQ_PMID | 10 uF 50 V | BQ_PMID | GND | Capacitor_SMD:C_1206_3216Metric | BQ25798 PMID capacitor 3
C205 | C_BQ_SYS | 10 uF 50 V | BQ_SYS | GND | Capacitor_SMD:C_1206_3216Metric | BQ25798 SYS capacitor 1
C206 | C_BQ_SYS | 10 uF 50 V | BQ_SYS | GND | Capacitor_SMD:C_1206_3216Metric | BQ25798 SYS capacitor 2
C207 | C_BQ_SYS | 10 uF 50 V | BQ_SYS | GND | Capacitor_SMD:C_1206_3216Metric | BQ25798 SYS capacitor 3
C208 | C_BQ_SYS | 10 uF 50 V | BQ_SYS | GND | Capacitor_SMD:C_1206_3216Metric | BQ25798 SYS capacitor 4
C209 | C_BQ_SYS | 10 uF 50 V | BQ_SYS | GND | Capacitor_SMD:C_1206_3216Metric | BQ25798 SYS capacitor 5
C210 | C_BQ_BAT | 10 uF 50 V | BAT_RAW | GND | Capacitor_SMD:C_1206_3216Metric | BQ25798 BAT capacitor 1
C211 | C_BQ_BAT | 10 uF 50 V | BAT_RAW | GND | Capacitor_SMD:C_1206_3216Metric | BQ25798 BAT capacitor 2
C212 | C_BQ_HF | 100 nF 50 V | BQ_VBUS | GND | Capacitor_SMD:C_0603_1608Metric | BQ25798 VBUS high-frequency bypass
C213 | C_BQ_HF | 100 nF 50 V | BQ_PMID | GND | Capacitor_SMD:C_0603_1608Metric | BQ25798 PMID high-frequency bypass
C214 | C_BQ_HF | 100 nF 50 V | BQ_SYS | GND | Capacitor_SMD:C_0603_1608Metric | BQ25798 SYS high-frequency bypass
C215 | C_REGN | 4.7 uF 25 V | BQ_REGN | GND | Capacitor_SMD:C_0805_2012Metric | BQ25798 REGN bypass
C216 | C_BTST | 47 nF 50 V | BQ_BTST1 | BQ_SW1 | Capacitor_SMD:C_0603_1608Metric | BQ25798 BTST1 bootstrap capacitor
C217 | C_BTST | 47 nF 50 V | BQ_BTST2 | BQ_SW2 | Capacitor_SMD:C_0603_1608Metric | BQ25798 BTST2 bootstrap capacitor
C218 | C_SDRV | 1 nF 50 V | BQ_SDRV | GND | Capacitor_SMD:C_0603_1608Metric | BQ25798 SDRV capacitor
R200 | R_TS_UPPER | 5.23 kOhm 1% | BQ_REGN | BQ_TS | Resistor_SMD:R_0603_1608Metric | BQ25798 REGN-to-TS resistor
R201 | R_TS_LOWER | 30.1 kOhm 1% | BQ_TS | NTC_SENSE | Resistor_SMD:R_0603_1608Metric | BQ25798 TS-to-NTC node resistor
R202 | R_BATP | 100 Ohm | BAT_RAW | BATP_KELVIN | Resistor_SMD:R_0603_1608Metric | BQ25798 BATP Kelvin series resistor
R203 | R_PROG | 4.70 kOhm 1% | BQ_PROG | GND | Resistor_SMD:R_0603_1608Metric | BQ25798 PROG resistor
R204 | R_INT_PULLUP | 10 kOhm | 3V3 | BQ_INT | Resistor_SMD:R_0603_1608Metric | BQ25798 INT pullup
R205 | R_I2C_PULLUP | 10 kOhm | 3V3 | I2C_SDA | Resistor_SMD:R_0603_1608Metric | I2C SDA pullup
R206 | R_I2C_PULLUP | 10 kOhm | 3V3 | I2C_SCL | Resistor_SMD:R_0603_1608Metric | I2C SCL pullup
D1 | CHG_LED | KT-0603R red LED | 3V3 | CHG_LED_K | LED_SMD:LED_0603_1608Metric | Hubei KENTO/JLCPCB C2286 charge LED anode from 3V3
R207 | CHG_LED_RES | 2.2 kOhm 1% | CHG_LED_K | BQ_STAT | Resistor_SMD:R_0603_1608Metric | BQ25798 charge LED series resistor to STAT sink
C400 | C_TPS_VIN | 22 uF 16 V | BQ_SYS | GND | Capacitor_SMD:C_1210_3225Metric | TPS61088 VIN capacitor 1
C401 | C_TPS_VIN | 22 uF 16 V | BQ_SYS | GND | Capacitor_SMD:C_1210_3225Metric | TPS61088 VIN capacitor 2
C402 | C_TPS_VOUT | 47 uF 10 V | 5V_RADIO | GND | Capacitor_SMD:C_1210_3225Metric | TPS61088 VOUT capacitor 1
C403 | C_TPS_VOUT | 47 uF 10 V | 5V_RADIO | GND | Capacitor_SMD:C_1210_3225Metric | TPS61088 VOUT capacitor 2
C404 | C_TPS_VIN_HF | 100 nF 50 V | BQ_SYS | GND | Capacitor_SMD:C_0603_1608Metric | TPS61088 VIN high-frequency bypass
C405 | C_TPS_VCC | 2.2 uF | BOOST_VCC | GND | Capacitor_SMD:C_0805_2012Metric | TPS61088 VCC bypass
C406 | C_TPS_BOOT | 100 nF | BOOST_BOOT | BOOST_SW | Capacitor_SMD:C_0603_1608Metric | TPS61088 BOOT capacitor
C407 | C_TPS_SS | 47 nF | BOOST_SS | GND | Capacitor_SMD:C_0603_1608Metric | TPS61088 soft-start capacitor
C408 | C_TPS_COMP | 4.7 nF | BOOST_COMP_RC | GND | Capacitor_SMD:C_0603_1608Metric | TPS61088 compensation capacitor
R400 | R_TPS_FB_TOP | 176 kOhm 0.1% | 5V_RADIO | BOOST_FB | Resistor_SMD:R_0603_1608Metric | TPS61088 feedback top resistor
R401 | R_TPS_FB_BOTTOM | 56.0 kOhm 0.1% | BOOST_FB | GND | Resistor_SMD:R_0603_1608Metric | TPS61088 feedback bottom resistor
R402 | R_TPS_FSW | 330 kOhm | BOOST_FSW | BOOST_SW | Resistor_SMD:R_0603_1608Metric | TPS61088 frequency resistor
R403 | R_TPS_ILIM | 100 kOhm | BOOST_ILIM | GND | Resistor_SMD:R_0603_1608Metric | TPS61088 current-limit resistor
R404 | R_TPS_COMP | 20.0 kOhm | BOOST_COMP | BOOST_COMP_RC | Resistor_SMD:R_0603_1608Metric | TPS61088 compensation resistor
R405 | R_TPS_EN_PD | 100 kOhm | BOOST_EN | GND | Resistor_SMD:R_0603_1608Metric | TPS61088 enable pulldown
C500 | C_E22_22U | 22 uF 16 V | 5V_RADIO | GND | Capacitor_SMD:C_1210_3225Metric | E22 local 5 V ceramic capacitor 1
C501 | C_E22_22U | 22 uF 16 V | 5V_RADIO | GND | Capacitor_SMD:C_1210_3225Metric | E22 local 5 V ceramic capacitor 2
C502 | C_E22_1U | 1 uF 16 V | 5V_RADIO | GND | Capacitor_SMD:C_0805_2012Metric | E22 local bypass
C503 | C_E22_BULK | 330 uF 10 V polymer | 5V_RADIO | GND | RoyalNode:C503_PANASONIC_10SVPC330M_8X6P9_RC | E22 local bulk capacitor
C504 | C_E22_HF | 100 nF 16 V | 5V_RADIO | GND | Capacitor_SMD:C_0603_1608Metric | E22 local high-frequency bypass 1
C505 | C_E22_HF | 100 nF 16 V | 5V_RADIO | GND | Capacitor_SMD:C_0603_1608Metric | E22 local high-frequency bypass 2
TH1 | TH1 | 10 kOhm NTC | NTC_SENSE | GND |  | Battery-mounted NTC represented at board connector

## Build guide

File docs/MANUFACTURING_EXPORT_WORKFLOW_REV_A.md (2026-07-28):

# RoyalNode Rev A Manufacturing Export Workflow

## Status

Rev A can now generate a draft quote package, but it is not a fabrication release.

Use:

```text
make export-draft-quote
```

Output path:

```text
hardware/fabrication/quote_draft_rev_a/
```

The generated files are ignored by Git. They are build artifacts, not source files.

## Exported Artifacts

The export script creates:

- Gerber files
- Excellon drill files
- drill map and drill report
- KiCad BOM CSV
- richer JLCPCB-oriented draft BOM with manufacturer and known LCSC fields
- KiCad position/CPL CSV
- schematic netlist
- zipped Gerber, drill and assembly bundles
- `READ_ME_NOT_FOR_FABRICATION.txt`

## Current Release Gate

The draft quote package is useful for checking the manufacturer workflow and rough order screens. It must not be used to order boards yet.

Known blockers:

- `RF_915` is present only as draft SMA-launch geometry pending release review.
- J5 is still a draft SMA envelope, not a released Molex edge-launch footprint.
- Final 50 ohm GCPW width/gap still needs the JLCPCB stack-up calculation.
- High-current power rails and switching loops are connected but not release-reviewed.
- Current KiCad gate is ERC/DRC clean with 0 unconnected items.
- Footprint/library mismatch warnings are ignored by project policy for tracked local release-candidate footprints; current DRC active violations are 0.

## Intended Use

Run the export after:

```text
make layout-status
```

The export package becomes orderable only after the release blockers are closed and the blocker note is deliberately replaced with a proper release manifest.

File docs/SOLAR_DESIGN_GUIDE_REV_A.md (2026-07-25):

# 2Watt Project Solar Design Guide, Rev A

## Supported panel class

- Nominal panel class: 6 V
- Supported deployment size: 20 W
- Minimum recommended size: 20 W for the current 2 W-radio target
- Preferred permanent-deployment size: 20 W
- Installer must verify Vmp, Voc, Imp and cold-weather Voc
- Board protection thresholds are approximately 4.5 V undervoltage and 25 V overvoltage at the LTC4365 stage

## Representative 10 W Panel

A 6 V-class 10 W panel may have maximum-power current around 1.7 A. It is useful for bench or light-duty testing, but it is no longer the preferred permanent deployment size for RoyalNode's full-power radio target.

A 10 W panel is sufficient for normal repeater operation in good sun, but battery recovery margin is limited during heavy traffic, winter conditions, shading or prolonged cloud.

## Representative 20 W Panel

A representative 6 V-class 20 W panel is expected to operate around 3.0-3.5 A near its maximum-power point. Exact Vmp, Voc, Imp and Isc depend on the selected panel and must be taken from its datasheet.

20 W remains the preferred permanent-deployment size because it provides more margin for:

- winter and cloudy weather
- recovery after multiple poor-solar days
- battery charging while the radio is active
- achieving the configured charge-current ceiling when solar conditions permit

## Daily-energy context

A nominal 3.7 V, 10 Ah battery stores roughly 37 Wh; a 20 Ah pack stores roughly 74 Wh. Real usable energy depends on pack protection thresholds, temperature, age and discharge rate.

Solar yield depends strongly on season, panel angle, orientation, shading and weather. The board does not assume a fixed number of peak-sun-hours in its electrical design.

## Locked solar protection path

```text
Solar XT30
  -> Littelfuse 0483005.DR, 5 A fuse
  -> LTC4365ITS8-1#TRMPBF surge/reverse-input controller
  -> Infineon ISA170170N04LMDSXTMA1 back-to-back protection MOSFET pair
  -> BQ25798 solar input-selector MOSFET pair
  -> BQ25798 VBUS
```

### LTC4365 threshold network

Locked divider values:

- R3: 1.78 MOhm
- R2: 180 kOhm
- R1: 40.2 kOhm

Design thresholds:

- UV falling: approximately 4.54 V nominal
- UV rising: depends on final LTC4365 hysteresis calculation
- OV rising: approximately 24.9 V nominal
- OV falling: depends on final LTC4365 hysteresis calculation

The older 12 V-panel divider and SMBJ22A + BSL303SPE-only protection concept are superseded and must not be used for Rev A schematic capture.

## BQ25798 solar charging

- Solar is the primary charging source.
- BQ25798 MPPT is enabled by host firmware when solar charging is active.
- MPPT open-circuit measurement delay target: 300 ms.
- MPPT measurement interval target: 2 minutes.
- The final `VOC_PCT` setting must be selected from the actual production panel's Vmp/Voc ratio. It is not locked until the panel is selected.
- Firmware must restore MPPT configuration after charger-reset conditions that clear the relevant register state.

## Input-current considerations

The 5 A fuse is on the solar connector/protection input. A 20 W 6 V-class panel can run around 3.3 A at maximum power, so the exact panel's short-circuit current, wiring ampacity, connector thermal behavior and protection coordination must be checked before deployment.

The BQ25798 input-current and charge-current limits determine how available solar power is split between system load and battery charging.

## Deployment verdict

- 10 W: bench/light-duty only unless field energy measurements justify it
- 20 W: recommended for permanent outdoor deployments
- larger panels are not automatically compatible merely because the wattage is higher; Voc, cold-weather Voc, Imp/Isc and protection limits must all remain within the board design limits

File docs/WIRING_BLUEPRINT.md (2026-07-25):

# 2Watt Project Wiring Blueprint, Rev A

## Core modules

- Seeed Studio XIAO nRF52840, standard version
- EBYTE E22-900M33S radio module
- TI BQ25798RQMR charger/power path
- TI TPS61088RHLR 5 V boost converter
- TI LM66100DCKR ideal diode for XIAO power isolation
- Protected 1S 3.6/3.7 V Li-ion/LiPo pack, 10-20 Ah class
- Board-mounted XT30 for solar
- Board-mounted XT30 for battery
- Battery-mounted Semitec 103AT-2 NTC through a dedicated two-wire temperature connector
- Board-edge 50-ohm SMA female connector
- Socketed XIAO with a separate two-wire JST-GH power lead

Rev A intentionally has no dedicated fuel-gauge IC. Battery and charger telemetry come from the BQ25798.

## Final XIAO pin map

| XIAO pin | nRF52840 pin | Signal |
|---|---|---|
| D0 | P0.02 | E22 NRST |
| D1 | P0.03 | E22 DIO1 |
| D2 | P0.28 | E22 BUSY |
| D3 | P0.29 | E22 NSS |
| D4 | P0.04 | BQ25798 I2C SDA |
| D5 | P0.05 | BQ25798 I2C SCL |
| D6 | P1.11 | E22 RXEN |
| D7 | P1.12 | TPS61088 EN |
| D8 | P1.13 | SPI SCK |
| D9 | P1.14 | SPI MISO |
| D10 | P1.15 | SPI MOSI |

All 11 exposed XIAO GPIOs are allocated.

E22 TXEN is not assigned to the XIAO. E22 DIO2 connects directly to E22 TXEN and firmware enables the SX1262 DIO2 RF-switch function.

## XIAO power lead

Only two wires are soldered to the underside of the XIAO.

| JST pin | Carrier signal | XIAO pad |
|---:|---|---|
| 1 | XIAO_BAT_ISO | BAT positive |
| 2 | GND | GND |

Power path:

```text
Protected battery/system node
  -> LM66100DCKR ideal diode
  -> JST-GH SM02B-GHS-TB(LF)(SN)
  -> GHR-02V-S cable housing
  -> short flexible two-wire harness
  -> XIAO BAT and GND underside pads
```

Rules:

- do not drive the XIAO 5V/VBUS pad from the carrier
- use flexible stranded wire
- keep the lead short
- add strain relief at the XIAO solder points
- mark polarity on both cable and PCB
- the XIAO and lead are removed together
- USB-C remains available for firmware and native USB power

## Power tree

```text
6 V / 20 W class solar
  -> XT30
  -> Littelfuse 0483005.DR 5 A-class fuse
  -> LTC4365ITS8-1#TRMPBF protection controller
  -> Infineon ISA170170N04LMDSXTMA1 back-to-back protection MOSFET pair
  -> BQ25798 solar input selector MOSFET pair
  -> BQ25798 VBUS

XIAO USB-C VBUS
  -> BQ25798 USB input selector MOSFET pair
  -> BQ25798 VBUS

Protected 1S Li-ion/LiPo
  <-> XT30
  <-> BQ25798 BAT / SYS power path

BQ25798 SYS
  -> TPS61088
  -> regulated 5 V
  -> E22 VCC pins directly

Protected battery/system node
  -> LM66100
  -> 2-pin JST-GH
  -> XIAO BAT and GND
```

The solar and USB input-selector paths use separate back-to-back MOSFET pairs so neither source backfeeds the other.

## BQ25798 connections

- PROG: 4.7 kOhm, 1%, for 1S default configuration
- /CE: tied low for autonomous charging
- TS: Semitec 103AT-2 network using 5.23 kOhm from REGN to TS and 30.1 kOhm from TS to the NTC node; NTC to GND
- SDA/SCL: XIAO D4/D5 with 10 kOhm pull-ups to 3.3 V
- D+/D-: no connection
- INT: 10 kOhm pull-up to 3.3 V, not routed to XIAO; poll status/fault registers by I2C
- STAT: direct open-drain LED drive, 3.3 V -> LED -> RLED -> STAT
- BATP: 100 Ohm series resistor on a dedicated Kelvin route from battery positive
- ILIM_HIZ: tied to REGN
- REGN: 4.7 uF
- SDRV: 1 nF to GND
- BTST1/BTST2: 47 nF each

## Battery interface

- XT30 carries battery positive and negative
- separate small locking 2-pin connector carries battery NTC and GND
- battery-mounted NTC is required for charge-temperature protection
- no carrier battery reverse-polarity stage
- battery pack must include suitable internal protection
- battery target: protected 1S, 10-20 Ah class, at least 5 A continuous discharge and at least 2 A permitted charge current
- target charging policy: suspend below 0 C and at/above 45 C

## E22 power and control

- E22 VCC: regulated 5.0 V
- no eFuse and no separate radio load switch
- TPS61088 D7 enable provides full radio-rail power cycling
- E22 DIO2 drives TXEN directly through the SX1262 RF-switch function
- E22 RXEN is controlled by XIAO D6
- DIO3 remains the TCXO-control function inside the module
- place 330-470 uF low-ESR bulk plus ceramic decoupling beside E22 VCC

RF switch behavior:

| TXEN | RXEN | Mode |
|---:|---:|---|
| 1 | 0 | Transmit |
| 0 | 1 | Receive |
| 0 | 0 | RF path inactive |

## RF path

```text
E22 pin 21 ANT
  -> direct 50-ohm grounded coplanar waveguide
  -> board-edge SMA female
```

Rules:

- no 0-ohm series link
- no pi tuning network
- no external DC-block capacitor
- no RF test connector or jumper
- uninterrupted Layer-2 ground reference
- grounded-coplanar via fence, target no greater than 1.5 mm pitch where practical
- no switch-node copper or digital route beneath the RF path
- JLCPCB is the Rev A fabricator
- preferred stack-up: JLC04161H-3313, 4-layer, 1.6 mm
- final width/gap must be generated from JLCPCB's production impedance model before routing release

## Indicators and service

- one external charge/status LED only
- XIAO onboard RGB LED remains available to firmware
- no power button
- no carrier reset button
- no SWD connector
- firmware update and normal recovery use XIAO USB-C and onboard reset

## Automatic startup

- TPS61088 EN is held low by 100 kOhm during MCU startup
- XIAO D7 intentionally enables the TPS61088 after board initialization
- inserting the protected battery powers the XIAO automatically
- removing the battery is the master disconnect

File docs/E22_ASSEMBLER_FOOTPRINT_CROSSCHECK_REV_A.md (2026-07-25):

# RoyalNode Rev A E22 Assembler Footprint Cross-Check

## Decision

RoyalNode Rev A will not require a loose physical E22-900M33S module before the first board order. MOD2 is intended to be installed on the PCB by the manufacturing/PCBA facility before the user receives the board, so the release gate is changed to a controlled remote verification path:

1. Transcribe the EBYTE manufacturer drawing.
2. Import the exact JLCPCB/LCSC EasyEDA footprint for `C22399506`.
3. Compare pin count, pitch, body class, pin 21 ANT location, and RF-ground adjacency.
4. Use JLCPCB DFM/PCBA review before order submission.
5. Inspect the first factory-assembled Rev A PCB as the physical first article.

This does not make the footprint risk disappear. It moves the physical-fit check from a pre-order blocker to a documented Rev A risk accepted for the first build.

## Sources Checked

### Manufacturer drawing

EBYTE E22-M Series module user manual:

```text
https://www.cdebyte.com/pdf-down.aspx?id=4216
```

Reviewed section:

```text
3.3 E22-170/400/900M30S(33S) Mechanical Dimensions and Pin Definitions
```

### Assembler and distributor part records

JLCPCB part page:

```text
https://jlcpcb.com/partdetail/Chengdu_Ebyte_ElecTech-E22900M33S/C22399506
```

JLCPCB identifies:

- Manufacturer part: `E22-900M33S`
- JLCPCB part: `C22399506`
- Package: `SMD,38.5x24mm`
- Antenna type: stamp-hole antenna and IPEX interface
- Interface: SPI
- Supply: 3.3 V to 5.5 V
- Transmit current: 1200 mA class
- EasyEDA symbol and PCB footprint available

LCSC product page:

```text
https://www.lcsc.com/product-detail/C22399506.html
```

LCSC identifies:

- Manufacturer: `EBYTE`
- MPN: `E22-900M33S`
- LCSC part: `C22399506`
- Packaging: `SMD,38.5x24mm`
- Key attributes: `868/915MHz 2W SPI Surface-Mount LoRa Module`
- Antenna type: IPEX interface and stamp-hole antenna

JLCPCB EasyEDA footprint export instructions:

```text
https://jlcpcb.com/help/article/how-to-export-footprints-from-easyeda
```

## Imported Library Artifact

The EasyEDA/JLC footprint was imported with:

```text
tmp/easyeda2kicad-venv/bin/easyeda2kicad --lcsc_id C22399506 --footprint --output tmp/easyeda_c22399506/e22 --overwrite --debug
```

The tool reported:

```text
Created Kicad footprint for ID: C22399506
Footprint name: COMM-SMD_22P-P2.54-L38.5-W24.0_E22-400M33S
```

The generated footprint name includes `E22-400M33S`, but the import source was the exact LCSC/JLCPCB ID `C22399506`, whose product record is `E22-900M33S`. Treat the name as an EasyEDA series-library artifact, not as a part substitution.

Repository artifact:

```text
hardware/kicad/RoyalNode/lib_footprints/RoyalNode.pretty/MOD2_E22_900M33S_JLC_C22399506_IMPORT_RC.kicad_mod
```

Status:

```text
NOT_RELEASED_RELEASE_CANDIDATE
```

## Geometry Comparison

| Check | EBYTE manual transcription | JLC/EasyEDA import | Result |
|---|---:|---:|---|
| Pin count | 22 | 22 | Match |
| Body class | 38.5 x 24.0 mm | 38.5 x 24.0 mm class | Match |
| Pitch | 2.54 mm | 2.54 mm | Match |
| Pin 21 | ANT | pad 21 present | Match |
| RF grounds | pins 20 and 22 | pads 20 and 22 adjacent | Match |
| Pad size | 1.25 x 1.50 mm | 1.50 x 2.20 mm | Difference |
| Pad X center | +/-11.375 mm | +/-11.650 mm | Difference |
| Pad Y centers | manual body-center origin | EasyEDA origin shifted by about +1.4 mm | Difference |

The JLC/EasyEDA import uses larger pads than the manual transcription. For Rev A, that is acceptable as a release-candidate direction because JLCPCB is the intended assembler and their library footprint is tied to the exact PCBA part number.

## Rev A Footprint Policy

Use the imported JLC/EasyEDA footprint as the preferred starting point for factory-installed JLCPCB PCBA, with these constraints:

- Keep the footprint marked as a release candidate until schematic symbols and placement are complete.
- Do not hand-edit pad geometry without recording the reason in this document.
- Place pin 21 toward the SMA edge.
- Connect pins 20 and 22 to the RF ground structure with very short paths.
- Include MOD2/E22-900M33S as an assembled BOM/CPL item, not as a hand-installed or loose post-delivery part.
- Submit the Rev A design through JLCPCB DFM and PCBA review before ordering.
- Record any JLC footprint/placement feedback before approving the order.

If JLCPCB rejects or modifies the module footprint during DFM/PCBA review, their correction takes priority over this imported footprint and must be committed before Gerber release.

## First-Article Check

Because no loose physical E22-900M33S module is available before the board order, the first physical check happens after the manufacturer installs MOD2 on the first Rev A PCB.

First-article inspection must verify:

- all 22 pads visibly align with the module castellations
- pin 1 orientation
- pin 21 ANT side faces the board SMA
- no solder bridging at pins 20/21/22
- module sits flat
- SMA/RF corridor is not blocked by the module body
- RF output is tested only with a proper 50-ohm load or antenna attached

## Accepted Risk

Proceeding without a pre-order physical module carries real footprint risk. Rev A accepts that risk because:

- EBYTE provides a manufacturer drawing for the module family.
- JLCPCB/LCSC list the exact part `C22399506`.
- The exact part has a JLC/EasyEDA footprint available.
- The key electrical/RF pin identities match the manual audit.
- MOD2 is planned as a factory-installed PCBA item, so assembler DFM/PCBA review is part of the order path.
- The first order is an engineering-validation build, not production.

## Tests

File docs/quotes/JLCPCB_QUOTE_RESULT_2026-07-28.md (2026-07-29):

# JLCPCB Quote Result - RoyalNode Rev A Draft

Date checked: 2026-07-28

This is a quote-only result from the JLCPCB online quote flow. No order was placed.

## Uploaded PCB Package

Uploaded file:

`RoyalNode_RevA_JLCPCB_PCB_QUOTE_UPLOAD_DRAFT.zip`

JLCPCB detected:

- Board type: standard rigid PCB
- Material: FR-4
- Layers: 4
- Board size: 87 mm x 97 mm detected, fields shown as 97 mm x 87 mm
- Quantity: 5
- PCB color: green
- Silkscreen: white
- Via covering: plugged
- Electrical test: flying probe fully test

## Bare PCB Quotes Shown

### Baseline Default Quote

Settings:

- Surface finish: HASL with lead
- Outer copper: 1 oz
- Inner copper: 0.5 oz
- Build time: 3-4 days

Price shown:

- PCB price: USD 7.00
- Shipping estimate: USD 27.92, DHL Express DDP, 2-4 business days
- Weight: 0.27 kg

Approximate visible total before taxes/fees/coupons:

- USD 34.92

### Preferred ENIG Quote

Settings:

- Surface finish: ENIG
- Outer copper: 1 oz
- Inner copper: 0.5 oz
- Build time: 3-4 days

Price shown:

- PCB price: USD 24.40
- Surface finish charge: USD 17.40
- Shipping estimate: USD 27.92, DHL Express DDP, 2-4 business days
- Weight: 0.27 kg

Approximate visible total before taxes/fees/coupons:

- USD 52.32

### Rugged ENIG + 2 oz Outer Copper Quote

Settings:

- Surface finish: ENIG
- Outer copper: 2 oz
- Inner copper: 0.5 oz
- Build time: 3-4 days
- PCBA toggle enabled, top-side assembly, standard PCBA selected

Price shown:

- PCB price: USD 60.50 after enabling PCBA flow
- Surface finish charge: USD 17.50
- Outer copper charge: USD 36.00
- Shipping estimate: USD 27.92, DHL Express DDP, 2-4 business days
- Weight: 0.30 kg

Approximate visible total before taxes/fees/coupons:

- USD 88.42

The same rugged settings showed USD 60.10 immediately before enabling the PCBA quote section. The small difference appears to come from the PCBA flow's edge-rail/assembly handling.

## Assembly Quote Status

PCB assembly was enabled in the quote form:

- PCBA type: Standard
- Assembly side: top side
- PCBA quantity: 5
- Edge rails/fiducials: added by JLCPCB
- Parts selection: by customer
- Solder paste: high temp

JLCPCB did not provide component or SMT assembly pricing on the first quote screen. Pressing Next redirected to JLCPCB sign-in, so full BOM/CPL component matching and final PCBA price require a signed-in JLCPCB session.

The current draft BOM still has missing LCSC part numbers, so the assembly quote will also need part matching and likely manual substitutions before it can become a real manufacturing quote.

## Logged-In PCBA Attempt

After signing in to JLCPCB, the BOM/CPL flow was retried.

The original CPL export failed JLCPCB processing. A corrected sample-format CPL was generated with:

- `Designator`
- `Mid X`
- `Mid Y`
- `Layer`
- `Rotation`
- Coordinate values using `mm` suffixes
- Positive Y coordinates instead of KiCad's negative placement Y values

A corrected sample-format BOM was also generated using JLCPCB's sample headers:

- `Comment`
- `Designator`
- `Footprint`
- `JLCPCB Part #（optional）`

With those files, JLCPCB successfully processed the placement data and reported:

- 55 parts detected
- 36 parts confirmed
- 15 parts with inventory shortage
- 4 parts not selected

The four not-selected rows were:

- `C212,C213,C214` - 100 nF 50 V X7R, 0603
- `C404` - 100 nF 50 V X7R, 0603
- `F1` - Littelfuse `0483005.DR` SMD fuse
- `MOD1` - Seeed XIAO nRF52840 module

JLCPCB would not advance to a complete Quote & Order price while those unselected rows remained unresolved. Therefore the final assembled PCBA price was not available yet.

Generated retry files:

- `RoyalNode_RevA_JLCPCB_BOM_SAMPLE_FORMAT.csv`
- `RoyalNode_RevA_JLCPCB_CPL_SAMPLE_FORMAT.csv`
- `RoyalNode_RevA_JLCPCB_BOM_PROCESSABLE_QUOTE.csv`
- `RoyalNode_RevA_JLCPCB_CPL_PROCESSABLE_QUOTE.csv`

The first processable quote pair excluded `MOD1` and `F1` and forced JLCPCB part `C14663` for the unmatched 100 nF capacitors, but it was not fully processed into a final quote during that session.

After the user confirmed that the XIAO module will be sourced separately, the processable quote generator was updated to:

- exclude `MOD1` only as a user-supplied XIAO module
- keep `F1` in the PCBA set as Bourns `SF-1206S500-2`, JLCPCB/LCSC `C913282`
- force `C212,C213,C214` and `C404` to Yageo `CC0603KRX7R9BB104`, JLCPCB/LCSC `C14663`
- force `C215` to Samsung `CL21B475KAFNNNE`, JLCPCB/LCSC `C98195`

That post-XIAO BOM/CPL pair was processed by JLCPCB and reduced the issue set from unmatched parts to stock-shortage rows. JLCPCB showed:

- 54 parts detected
- 39 parts confirmed
- 15 parts with inventory shortage

The second substitution pass now also forces:

- `C216,C217` to `C1622`
- `C218` to `C163508`
- `C405` to `C74690`
- `J5` to exact Molex SMA `C841205`
- `J6` to GH-compatible XYECONN `C51940118`
- `Q1,Q2,Q3` to same-family Infineon candidate `C43317100`
- `R100` to `C166890`
- `R102` to `C4210499`
- `R200` to `C4076829`
- `R201` to `C1709086`
- `R400` to 180 kOhm `C4074070`
- `R401` to 57.6 kOhm `C4106968`
- `U4` to `C688323`

The processable quote files were regenerated with this second pass and then reprocessed in the signed-in JLCPCB SMT quote flow.

JLCPCB showed:

- 54 parts detected
- 45 parts confirmed
- 9 parts with inventory shortage

The remaining shortage rows were:

- `Q1`, `Q2`, `Q3` - Infineon dual N-channel PG-DSO-8 MOSFET candidates
- `R102`
- `R200`
- `R201`
- `R400`
- `R401`
- `U4`

The MOSFET rows were then excluded from the quote because no safe JLC in-stock dual N-channel PG-DSO-8 replacement was found. JLC-listed related Infineon parts included N+P devices, which are not acceptable substitutes for RoyalNode's back-to-back N-channel input selector/protection circuits.

The resistor and LTC4365 rows were retried with JLC-source alternatives, but still showed inventory shortage inside the SMT quote flow.

The successful quote path used JLCPCB's `Do not place` option for the remaining shortage rows.

## Final Successful Draft PCBA Quote

Date/time shown by JLCPCB autosave: 2026-07-28 22:14

No order was placed, and the quote was not saved to cart.

Final quote-page settings and prices shown:

- Quantity: 5 PCBAs
- PCB: 4-layer FR-4, green solder mask, white silkscreen
- Board size after JLC assembly rails: 97 mm x 97 mm
- Surface finish: ENIG
- Outer copper: 2 oz
- Inner copper: 0.5 oz
- Via covering: plugged
- PCBA type: Standard
- Assembly side: top side
- Solder paste: high temp
- PCB build time: 3 days
- Assembly build time selected: 5-6 days
- Weight shown: 1.12 kg

Charge details shown:

| Item | Price |
|---|---:|
| PCB price | USD 60.50 |
| Standard PCBA price | USD 260.29 |
| Setup fee | USD 25.56 |
| Stencil | USD 8.21 |
| Components, 32 items | USD 172.02 |
| Feeders loading fee | USD 47.43 |
| SMT assembly | USD 2.33 |
| Hand-soldering labor fee | USD 3.58 |
| Manual assembly | USD 0.66 |
| Packaging fee | USD 0.50 |
| Total price shown | USD 320.79 |

Shipping was not shown on the final PCBA quote page captured in this pass. An earlier rugged PCB+PCBA setup screen showed a shipping estimate around USD 26-28, but that should not be treated as the final shipped total.

## Excluded / Do-Not-Place Items In Final Quote

These items were not included in the successful JLC quote total:

- `MOD1` - Seeed XIAO nRF52840; user-supplied
- `J5` - Molex edge-launch SMA; recognized earlier but absent from the final placement list
- `Q1`, `Q2`, `Q3` - dual N-channel MOSFETs
- `R102`, `R200`, `R201`, `R400`, `R401` - shortage-blocked precision/feedback resistors
- `U4` - shortage-blocked LTC4365 input-protection controller

The final placement list did include major assembly items such as:

- `MOD2` EBYTE E22-900M33S, JLCPCB/LCSC `C22399506`
- `U1` BQ25798, `C2876593`
- `U2` LM66100DCKR, `C2869734`
- `U3` TPS61088RHLR, `C87357`
- `J1,J2` XT30 connectors, `C431092`
- `L1,L2` Coilcraft power inductors, `C3911470` and `C19191686`

See `docs/quotes/JLCPCB_SUBSTITUTIONS_REV_A_2026-07-28.md`.

## Do Not Order Yet

This quote used draft fabrication files. The project currently has clean ERC/DRC/unconnected checks, but the package is still marked draft because these items need release review before fabrication:

- SMA RF launch and 50 ohm trace geometry
- Final JLCPCB stack-up selection
- Power supply layout review
- BOM LCSC part-number completion
- Assembly orientation review

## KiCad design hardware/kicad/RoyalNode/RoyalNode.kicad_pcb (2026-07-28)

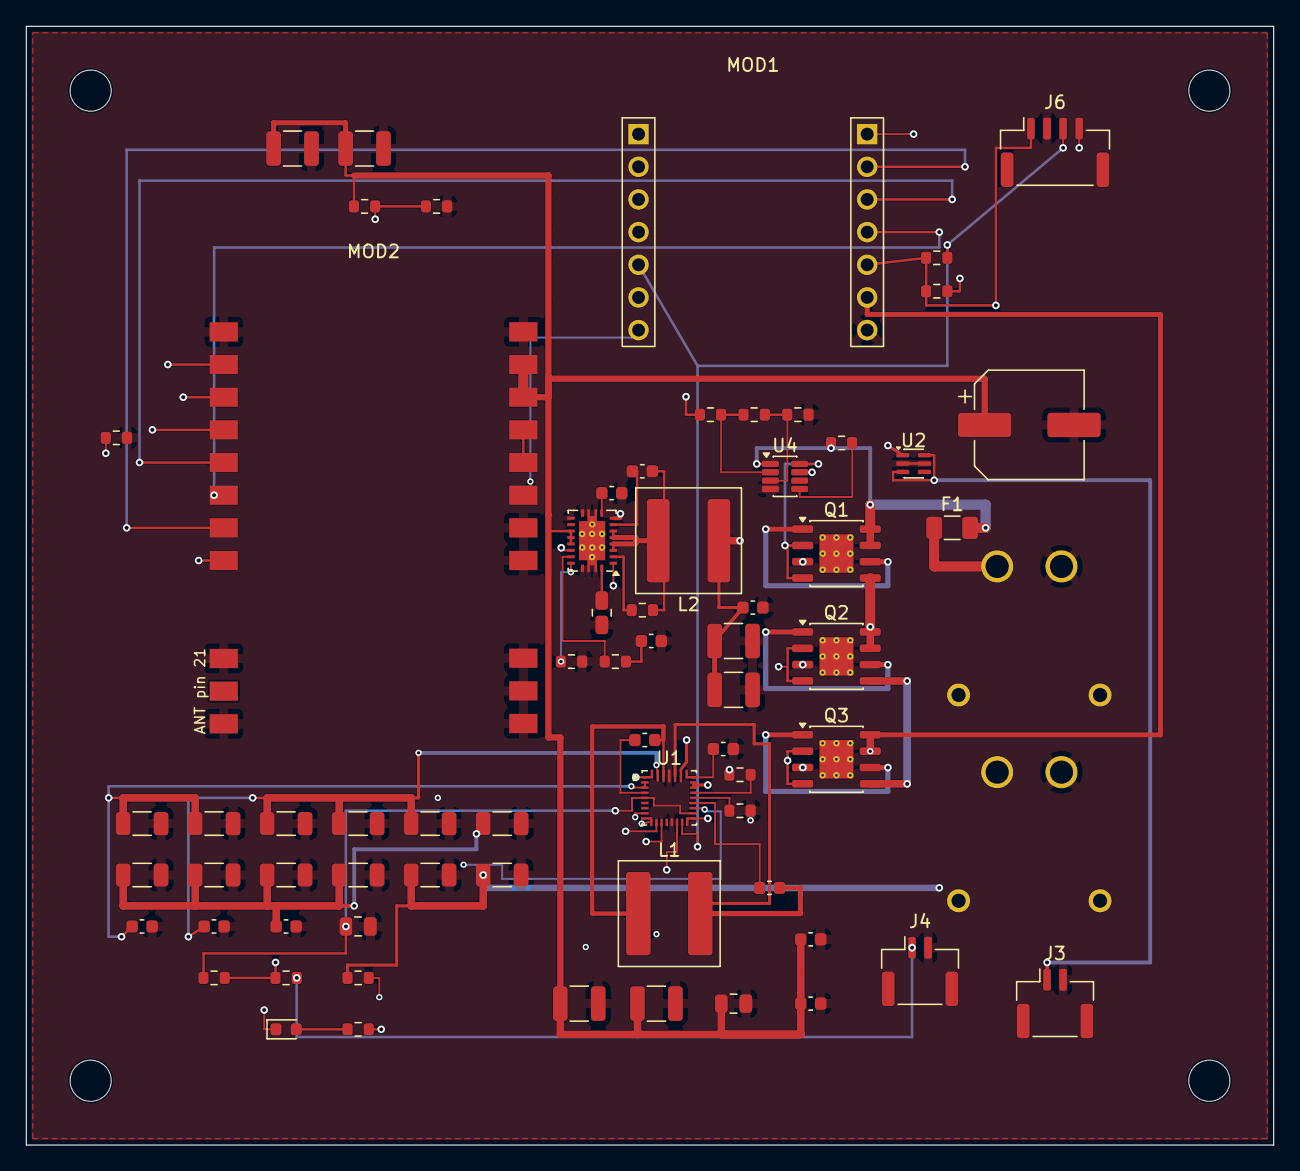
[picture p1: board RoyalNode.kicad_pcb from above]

Board: 4 copper layers, 97.0 x 87.0 mm, 75 parts (0 on the bottom side), 55 nets.

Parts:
C200, C201, C202, C203, C204, C205, C206, C207, C208, C209, C210, C211: 10 uF 50 V; C_1206_3216Metric
C212, C213, C214, C404: 100 nF 50 V; C_0603_1608Metric
C215: 4.7 uF 25 V; C_0805_2012Metric
C216, C217: 47 nF 50 V; C_0603_1608Metric
C218: 1 nF 50 V; C_0603_1608Metric
C400, C401, C500, C501: 22 uF 16 V; C_1210_3225Metric
C402, C403: 47 uF 10 V; C_1210_3225Metric
C405: 2.2 uF; C_0805_2012Metric
C406: 100 nF; C_0603_1608Metric
C407: 47 nF; C_0603_1608Metric
C408: 4.7 nF; C_0603_1608Metric
C502: 1 uF 16 V; C_0805_2012Metric
C503: 330 uF 10 V polymer; C503_PANASONIC_10SVPC330M_8X6P9_RC
C504, C505: 100 nF 16 V; C_0603_1608Metric
D1: KT-0603R red LED; LED_0603_1608Metric
F1: Littelfuse 0483005.DR 1206 RC; F1_LITTELFUSE_483_1206_RC
J1, J2: XT30PW-M C431092 RC; J_POWER_XT30PW_M_C431092_RC
J3, J4: J_LOW_JST_GH_SM02B_GHS_TB_RC
J5: SMA edge envelope; J5_SMA_0732511150_DRAFT_ENVELOPE
J6: J_LOW_JST_GH_SM04B_GHS_TB_RC
L1: XAL7070-222MEC RC; L1_COILCRAFT_XAL7070_222MEC_RC
L2: XAL7030-222MEC RC; L2_COILCRAFT_XAL7030_222MEC_RC
MH1, MH2, MH3, MH4: M3 NPTH 3.2mm; MH_M3_NPTH_3P2MM_6P8MM_CLEARANCE
MOD1: XIAO nRF52840 socket C53202181 RC; MOD1_XIAO_NRF52840_SOCKET_C53202181_RC
MOD2: E22-900M33S C22399506 RC; MOD2_E22_900M33S_JLC_C22399506_RC
Q1, Q2, Q3: Infineon PG-DSO-8-27 thermal vias RC; Q_POWER_INFINEON_PG_DSO_8_27_RC
R100: 1.78 MOhm 1%; R_0603_1608Metric
R101: 180 kOhm 0.1%; R_0603_1608Metric
R102: 40.2 kOhm 0.1%; R_0603_1608Metric
R103, R403, R405: 100 kOhm; R_0603_1608Metric
R200: 5.23 kOhm 1%; R_0603_1608Metric
R201: 30.1 kOhm 1%; R_0603_1608Metric
R202: 100 Ohm; R_0603_1608Metric
R203: 4.70 kOhm 1%; R_0603_1608Metric
R204, R205, R206: 10 kOhm; R_0603_1608Metric
R207: 2.2 kOhm 1%; R_0603_1608Metric
R400: 176 kOhm 0.1%; R_0603_1608Metric
R401: 56.0 kOhm 0.1%; R_0603_1608Metric
R402: 330 kOhm; R_0603_1608Metric
R404: 20.0 kOhm; R_0603_1608Metric
U1: BQ25798 RQM0029A RC; U1_BQ25798_RQM0029A_RC
U2: LM66100 DCK0006A SC70-6 RC; U2_LM66100_DCK0006A_SC70_6_RC
U3: TPS61088 RHL0020A thermal vias RC; U3_TPS61088_RHL0020A_THERMALVIAS_RC
U4: LTC4365 TSOT-23-8 RC; U4_LTC4365_TSOT23_8_RC

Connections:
3V3: D1.1 (Terminal 1), J6.1 (3V3), MOD1.3V3, R204.1 (Terminal 1), R205.1 (Terminal 1), R206.1 (Terminal 1)
5V_RADIO: C402.1 (Terminal 1), C403.1 (Terminal 1), C500.1 (Terminal 1), C501.1 (Terminal 1), C502.1 (Terminal 1), C503.1 (Terminal 1), C504.1 (Terminal 1), C505.1 (Terminal 1), MOD2.9 (VCC), MOD2.10 (VCC), R400.1 (Terminal 1), U3.14 (VOUT), U3.15 (VOUT), U3.16 (VOUT)
BATP_KELVIN: R202.2 (Terminal 2), U1.18 (BATP)
BAT_RAW: C210.1 (Terminal 1), C211.1 (Terminal 1), J2.1 (PLUS), R202.1 (Terminal 1), U1.22 (BAT), U1.23 (BAT), U2.1 (VIN)
BOOST_BOOT: C406.1 (Terminal 1), U3.8 (BOOT)
BOOST_COMP: R404.1 (Terminal 1), U3.18 (COMP)
BOOST_COMP_RC: C408.1 (Terminal 1), R404.2 (Terminal 2)
BOOST_EN: MOD1.D7 (D7/P1.12), R405.1 (Terminal 1), U3.2 (EN)
BOOST_FB: R400.2 (Terminal 2), R401.1 (Terminal 1), U3.17 (FB)
BOOST_FSW: R402.1 (Terminal 1), U3.3 (FSW)
BOOST_ILIM: R403.1 (Terminal 1), U3.19 (ILIM)
BOOST_SS: C407.1 (Terminal 1), U3.10 (SS)
BOOST_SW: C406.2 (Terminal 2), L2.2 (Terminal 2), R402.2 (Terminal 2), U3.4 (SW), U3.5 (SW), U3.6 (SW), U3.7 (SW)
BOOST_VCC: C405.1 (Terminal 1), U3.1 (VCC)
BQ_ACDRV1: Q2.2 (G1), Q2.4 (G2), U1.11 (ACDRV1)
BQ_ACDRV2: Q3.2 (G1), Q3.4 (G2), U1.10 (ACDRV2)
BQ_BTST1: C216.1 (Terminal 1), U1.4 (BTST1)
BQ_BTST2: C217.1 (Terminal 1), U1.19 (BTST2)
BQ_INT: R204.2 (Terminal 2), U1.21 (INT)
BQ_PMID: C202.1 (Terminal 1), C203.1 (Terminal 1), C204.1 (Terminal 1), C213.1 (Terminal 1), U1.29 (PMID)
BQ_PROG: R203.1 (Terminal 1), U1.20 (PROG)
BQ_REGN: C215.1 (Terminal 1), R200.1 (Terminal 1), U1.5 (REGN), U1.17 (ILIM_HIZ)
BQ_SDRV: C218.1 (Terminal 1), U1.24 (SDRV)
BQ_SOLAR_SELECTOR_COMMON: Q2.1 (S1), Q2.6 (S2)
BQ_STAT: R207.2 (Terminal 2), U1.1 (STAT)
BQ_SW1: C216.2 (Terminal 2), L1.1 (Terminal 1), U1.28 (SW1)
BQ_SW2: C217.2 (Terminal 2), L1.2 (Terminal 2), U1.26 (SW2)
BQ_SYS: C205.1 (Terminal 1), C206.1 (Terminal 1), C207.1 (Terminal 1), C208.1 (Terminal 1), C209.1 (Terminal 1), C214.1 (Terminal 1), C400.1 (Terminal 1), C401.1 (Terminal 1), C404.1 (Terminal 1), L2.1 (Terminal 1), U1.25 (SYS), U3.9 (VIN)
BQ_TS: R200.2 (Terminal 2), R201.1 (Terminal 1), U1.16 (TS)
BQ_USB_SELECTOR_COMMON: Q3.1 (S1), Q3.6 (S2)
BQ_VBUS: C200.1 (Terminal 1), C201.1 (Terminal 1), C212.1 (Terminal 1), Q2.3 (D2), Q2.5 (D2), Q3.3 (D2), Q3.5 (D2), U1.2 (VBUS), U1.3 (VBUS)
CHG_LED_K: D1.2 (Terminal 2), R207.1 (Terminal 1)
E22_BUSY: MOD1.D2 (D2/P0.28), MOD2.14 (BUSY)
E22_DIO1: MOD1.D1 (D1/P0.03), MOD2.13 (DIO1)
E22_NRST: MOD1.D0 (D0/P0.02), MOD2.15 (NRST)
E22_NSS: MOD1.D3 (D3/P0.29), MOD2.19 (NSS)
E22_RXEN: MOD1.D6 (D6/P1.11), MOD2.6 (RXEN)
E22_TXEN_DIO2: MOD2.7 (TXEN), MOD2.8 (DIO2)
GND: C200.2 (Terminal 2), C201.2 (Terminal 2), C202.2 (Terminal 2), C203.2 (Terminal 2), C204.2 (Terminal 2), C205.2 (Terminal 2), C206.2 (Terminal 2), C207.2 (Terminal 2), C208.2 (Terminal 2), C209.2 (Terminal 2), C210.2 (Terminal 2), C211.2 (Terminal 2), C212.2 (Terminal 2), C213.2 (Terminal 2), C214.2 (Terminal 2), C215.2 (Terminal 2), C218.2 (Terminal 2), C400.2 (Terminal 2), C401.2 (Terminal 2), C402.2 (Terminal 2), C403.2 (Terminal 2), C404.2 (Terminal 2), C405.2 (Terminal 2), C407.2 (Terminal 2), C408.2 (Terminal 2), C500.2 (Terminal 2), C501.2 (Terminal 2), C502.2 (Terminal 2), C503.2 (Terminal 2), C504.2 (Terminal 2), C505.2 (Terminal 2), J1.2 (MINUS), J2.2 (MINUS), J3.2 (PIN2), J4.2 (PIN2), J6.2 (GND), MOD1.GND, MOD2.1 (GND), MOD2.2 (GND), MOD2.3 (GND), MOD2.4 (GND), MOD2.5 (GND), MOD2.11 (GND), MOD2.12 (GND), MOD2.20 (GND), MOD2.22 (GND), R102.2 (Terminal 2), R203.2 (Terminal 2), R401.2 (Terminal 2), R403.2 (Terminal 2), R405.2 (Terminal 2), U1.13 (CE), U1.27 (GND), U2.2 (GND), U2.5 (ST), U3.11 (NC_GND), U3.12 (NC_GND), U3.20 (AGND), U3.21 (PGND_EP), U4.4 (GND)
I2C_SCL: J6.4 (SCL), MOD1.D5 (D5/P0.05), R206.2 (Terminal 2), U1.14 (SCL)
I2C_SDA: J6.3 (SDA), MOD1.D4 (D4/P0.04), R205.2 (Terminal 2), U1.15 (SDA)
LTC_SHDN: R103.2 (Terminal 2), U4.5 (SHDN)
NTC_SENSE: J4.1 (PIN1), R201.2 (Terminal 2)
OV_NODE: R101.2 (Terminal 2), R102.1 (Terminal 1), U4.3 (OV)
SOLAR_FUSED: F1.2 (Terminal 2), Q1.7 (D1), Q1.8 (D1), R100.1 (Terminal 1), R103.1 (Terminal 1), U4.1 (VIN)
SOLAR_PROTECTED: Q1.3 (D2), Q1.5 (D2), Q2.7 (D1), Q2.8 (D1), U1.9 (VAC1), U4.7 (VOUT)
SOLAR_PROT_COMMON: Q1.1 (S1), Q1.6 (S2)
SOLAR_PROT_GATE: Q1.2 (G1), Q1.4 (G2), U4.8 (GATE)
SOLAR_RAW: F1.1 (Terminal 1), J1.1 (PLUS)
SPI_MISO: MOD1.D9 (D9/P1.14), MOD2.16 (MISO)
SPI_MOSI: MOD1.D10 (D10/P1.15), MOD2.17 (MOSI)
SPI_SCK: MOD1.D8 (D8/P1.13), MOD2.18 (SCK)
USB_VBUS_RAW: MOD1.5V (5V/VBUS), Q3.7 (D1), Q3.8 (D1), U1.8 (VAC2)
UV_NODE: R100.2 (Terminal 2), R101.1 (Terminal 1), U4.2 (UV)
XIAO_BAT_ISO: J3.1 (PIN1), U2.3 (CE), U2.6 (VOUT)

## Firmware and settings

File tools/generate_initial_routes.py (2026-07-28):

#!/usr/bin/env python3
"""Generate the first low-risk RoyalNode PCB routes.

This intentionally routes only stable, low-current nets and adds the intended
top and Layer-2 ground pours. It does not route RF, high-current power rails or
switching loops.
"""

from __future__ import annotations

import re
import uuid
from pathlib import Path

ROOT = Path(__file__).resolve().parents[1]
PCB = ROOT / "hardware/kicad/RoyalNode/RoyalNode.kicad_pcb"
NAMESPACE = uuid.UUID("0c64c82f-b03a-455f-93ce-ceb8a0674a31")

SEGMENTS = [
    {
        "name": "e22-dio2-to-txen",
        "net": "E22_TXEN_DIO2",
        "layer": "F.Cu",
        "width": 0.20,
        "points": [(53.65, 48.92), (53.65, 46.38)],
    },
    {
        "name": "e22-vcc-local",
        "net": "5V_RADIO",
        "layer": "F.Cu",
        "width": 0.80,
        "points": [(53.65, 43.84), (53.65, 41.30)],
    },
    {
        "name": "u3-5v-radio-local",
        "net": "5V_RADIO",
        "layer": "F.Cu",
        "width": 0.20,
        "points": [(57.35, 54.25), (57.35, 55.25)],
    },
    {
        "name": "5v-radio-u3-to-e22-rotated-o",
        "net": "5V_RADIO",
        "layer": "F.Cu",
        "width": 0.20,
        "points": [(57.35, 54.25), (55.60, 54.25), (55.60, 53.00)],
    },
    {
        "name": "5v-radio-u3-to-e22-top-pour-o",
        "net": "5V_RADIO",
        "layer": "F.Cu",
        "width": 0.50,
        "points": [(55.60, 53.00), (55.60, 43.84), (53.65, 43.84)],
    },
    {
        "name": "5v-radio-output-cap-spine-p",
        "net": "5V_RADIO",
        "layer": "F.Cu",
        "width": 0.50,
        "points": [(55.60, 43.84), (55.60, 26.60), (40.48, 26.60)],
    },
    {
        "name": "5v-radio-c503-top-corridor-r",
        "net": "5V_RADIO",
        "layer": "F.Cu",
        "width": 0.50,
        "points": [(89.525, 46.00), (89.525, 42.40), (55.60, 42.40), (55.60, 43.84)],
    },
    {
        "name": "5v-radio-lower-bank-spine-q",
        "net": "5V_RADIO",
        "layer": "F.Cu",
        "width": 0.50,
        "points": [(55.60, 53.00), (55.60, 70.30), (56.53, 70.30), (56.53, 93.40)],
    },
    {
        "name": "radio-bulk-cap-bank",
        "net": "5V_RADIO",
        "layer": "F.Cu",
        "width": 0.60,
        "points": [(56.53, 93.40), (62.53, 93.40), (69.05, 93.40), (75.23, 93.40)],
    },
    {
        "name": "radio-bulk-c500-stub",
        "net": "5V_RADIO",
        "layer": "F.Cu",
        "width": 0.60,
        "points": [(56.53, 91.00), (56.53, 93.40)],
    },
    {
        "name": "radio-bulk-c501-stub",
        "net": "5V_RADIO",
        "layer": "F.Cu",
        "width": 0.60,
        "points": [(62.53, 91.00), (62.53, 93.40)],
    },
    {
        "name": "radio-bulk-c502-stub",
        "net": "5V_RADIO",
        "layer": "F.Cu",
        "width": 0.60,
        "points": [(69.05, 91.00), (69.05, 93.40)],
    },
    {
        "name": "radio-bulk-c504-c505-stub",
        "net": "5V_RADIO",
        "layer": "F.Cu",
        "width": 0.60,
        "points": [(75.23, 86.00), (75.23, 91.00), (75.23, 93.40)],
    },
    {
        "name": "u3-boost-sw-upper-local",
        "net": "BOOST_SW",
        "layer": "F.Cu",
        "width": 0.20,
        "points": [(60.65, 54.25), (60.65, 54.75)],
    },
    {
        "name": "u3-boost-sw-lower-local",
        "net": "BOOST_SW",
        "layer": "F.Cu",
        "width": 0.20,
        "points": [(60.65, 55.25), (60.65, 55.75)],
    },
    {
        "name": "boost-sw-u3-to-l2-upper",
        "net": "BOOST_SW",
        "layer": "F.Cu",
        "width": 0.40,
        "points": [(60.65, 54.75), (62.40, 54.75), (62.40, 55.00), (64.14, 55.00)],
    },
    {
        "name": "boost-sw-u3-to-l2-lower",
        "net": "BOOST_SW",
        "layer": "F.Cu",
        "width": 0.40,
        "points": [(60.65, 55.25), (62.40, 55.25), (62.40, 55.00)],
    },
    {
        "name": "boost-boot-u3-to-c406",
        "net": "BOOST_BOOT",
        "layer": "F.Cu",
        "width": 0.20,
        "points": [(60.65, 53.75), (62.50, 53.75), (62.50, 49.60), (62.13, 49.60)],
    },
    {
        "name": "boost-boot-c406-sw",
        "net": "BOOST_SW",
        "layer": "F.Cu",
        "width": 0.20,
        "points": [(63.68, 49.60), (64.60, 49.60), (64.60, 55.00), (64.14, 55.00)],
    },
    {
        "name": "boost-fsw-u3-to-r402",
        "net": "BOOST_FSW",
        "layer": "F.Cu",
        "width": 0.20,
        "points": [(60.65, 56.25), (61.45, 56.25), (61.45, 60.40), (62.08, 60.40)],
    },
    {
        "name": "boost-fsw-r402-sw",
        "net": "BOOST_SW",
        "layer": "F.Cu",
        "width": 0.20,
        "points": [(63.73, 60.40), (64.60, 60.40), (64.60, 55.00), (64.14, 55.00)],
    },
    {
        "name": "i2c-pullup-3v3-link",
        "net": "3V3",
        "layer": "F.Cu",
        "width": 0.20,
        "points": [(80.39, 33.54), (84.98, 33.00), (84.98, 35.60)],
    },
    {
        "name": "i2c-pullup-sda-fanout",
        "net": "I2C_SDA",
        "layer": "F.Cu",
        "width": 0.20,
        "points": [(86.62, 33.00), (86.62, 32.00)],
    },
    {
        "name": "i2c-pullup-sda-backbone",
        "net": "I2C_SDA",
        "layer": "B.Cu",
        "width": 0.20,
        "points": [(86.62, 32.00), (86.62, 41.40)],
    },
    {
        "name": "i2c-sda-bus-join",
        "net": "I2C_SDA",
        "layer": "B.Cu",
        "width": 0.20,
        "points": [(67.20, 41.40), (86.62, 41.40)],
    },
    {
        "name": "i2c-sda-xiao-entry",
        "net": "I2C_SDA",
        "layer": "B.Cu",
        "width": 0.20,
        "points": [(67.20, 41.40), (62.61, 33.54)],
    },
    {
        "name": "i2c-pullup-scl-fanout",
        "net": "I2C_SCL",
        "layer": "F.Cu",
        "width": 0.20,
        "points": [(86.62, 35.60), (87.60, 35.60), (87.60, 34.60)],
    },
    {
        "name": "i2c-pullup-scl-backbone",
        "net": "I2C_SCL",
        "layer": "In2.Cu",
        "width": 0.20,
        "points": [(87.60, 34.60), (87.60, 42.80)],
    },
    {
        "name": "i2c-scl-bus-join",
        "net": "I2C_SCL",
        "layer": "In2.Cu",
        "width": 0.20,
        "points": [(64.80, 42.80), (87.60, 42.80)],
    },
    {
        "name": "i2c-scl-xiao-entry",
        "net": "I2C_SCL",
        "layer": "In2.Cu",
        "width": 0.20,
        "points": [(64.80, 42.80), (64.80, 36.08), (62.61, 36.08)],
    },
    {
        "name": "j6-sda-service-fanout",
        "net": "I2C_SDA",
        "layer": "F.Cu",
        "width": 0.15,
        "points": [(95.63, 22.95), (95.63, 24.45)],
    },
    {
        "name": "j6-sda-service-backbone",
        "net": "I2C_SDA",
        "layer": "B.Cu",
        "width": 0.20,
        "points": [(95.63, 24.45), (86.62, 32.00)],
    },
    {
        "name": "j6-scl-service-fanout",
        "net": "I2C_SCL",
        "layer": "F.Cu",
        "width": 0.15,
        "points": [(96.88, 22.95), (96.88, 24.45)],
    },
    {
        "name": "j6-scl-service-backbone",
        "net": "I2C_SCL",
        "layer": "In2.Cu",
        "width": 0.20,
        "points": [(96.88, 24.45), (87.60, 34.60)],
    },
    {
        "name": "j6-3v3-service-route",
        "net": "3V3",
        "layer": "F.Cu",
        "width": 0.20,
        "points": [(93.13, 22.95), (93.13, 24.45), (90.40, 24.45), (90.40, 36.70), (84.98, 36.70), (84.98, 35.60)],
    },
    {
        "name": "r204-3v3-local-via-fanout-b",
        "net": "3V3",
        "layer": "F.Cu",
        "width": 0.15,
        "points": [(69.68, 73.20), (69.68, 72.80)],
    },
    {
        "name": "r204-3v3-spine-tie-c",
        "net": "3V3",
        "layer": "In2.Cu",
        "width": 0.15,
        "points": [(69.68, 72.80), (69.68, 91.50)],
    },
    {
        "name": "r204-3v3-right-edge-service-c",
        "net": "3V3",
        "layer": "In2.Cu",
        "width": 0.15,
        "points": [(100.00, 69.00), (100.00, 36.70), (90.40, 36.70)],
    },
    {
        "name": "bq-sda-fanout",
        "net": "I2C_SDA",
        "layer": "F.Cu",
        "width": 0.15,
        "points": [(66.00, 76.90), (66.00, 77.80), (67.20, 77.80), (67.20, 78.80)],
    },
    {
        "name": "bq-sda-backbone",
        "net": "I2C_SDA",
        "layer": "B.Cu",
        "width": 0.20,
        "points": [(67.20, 78.80), (67.20, 41.40)],
    },
    {
        "name": "bq-scl-fanout",
        "net": "I2C_SCL",
        "layer": "F.Cu",
        "width": 0.15,
        "points": [(65.60, 76.90), (65.60, 79.20), (64.80, 79.20), (64.80, 80.60)],
    },
    {
        "name": "bq-scl-backbone",
        "net": "I2C_SCL",
        "layer": "In2.Cu",
        "width": 0.20,
        "points": [(64.80, 80.60), (64.80, 42.80)],
    },
    {
        "name": "bq-prog-local-route",
        "net": "BQ_PROG",
        "layer": "F.Cu",
        "width": 0.15,
        "points": [(66.90, 75.00), (69.68, 75.00), (69.68, 76.00)],
    },
    {
        "name": "bq-int-local-route",
        "net": "BQ_INT",
        "layer": "F.Cu",
        "width": 0.15,
        "points": [(66.90, 74.60), (71.33, 74.60), (71.33, 73.20)],
    },
    {
        "name": "bq-pmid-cap-bank-bus",
        "net": "BQ_PMID",
        "layer": "F.Cu",
        "width": 0.60,
        "points": [(33.73, 75.00), (39.33, 75.00), (44.93, 75.00)],
    },
    {
        "name": "bq-vbus-cap-bank-bus",
        "net": "BQ_VBUS",
        "layer": "F.Cu",
        "width": 0.60,
        "points": [(22.53, 75.00), (28.13, 75.00)],
    },
    {
        "name": "bq-vbus-c200-stub",
        "net": "BQ_VBUS",
        "layer": "F.Cu",
        "width": 0.60,
        "points": [(22.53, 77.00), (22.53, 75.00)],
    },
    {
        "name": "bq-vbus-c201-stub",
        "net": "BQ_VBUS",
        "layer": "F.Cu",
        "width": 0.60,
        "points": [(28.13, 77.00), (28.13, 75.00)],
    },
    {
        "name": "bq-vbus-c212-bus-via-fanout",
        "net": "BQ_VBUS",
        "layer": "F.Cu",
        "width": 0.20,
        "points": [(22.53, 75.00), (21.40, 75.00)],
    },
    {
        "name": "bq-vbus-c212-bottom-jog",
        "net": "BQ_VBUS",
        "layer": "B.Cu",
        "width": 0.20,
        "points": [(21.40, 75.00), (21.40, 85.80), (22.40, 85.80)],
    },
    {
        "name": "bq-vbus-c212-pad-fanout",
        "net": "BQ_VBUS",
        "layer": "F.Cu",
        "width": 0.20,
        "points": [(22.40, 85.80), (23.23, 85.00)],
    },
    {
        "name": "bq-pmid-c202-stub",
        "net": "BQ_PMID",
        "layer": "F.Cu",
        "width": 0.60,
        "points": [(33.73, 77.00), (33.73, 75.00)],
    },
    {
        "name": "bq-pmid-c203-stub",
        "net": "BQ_PMID",
        "layer": "F.Cu",
        "width": 0.60,
        "points": [(39.33, 77.00), (39.33, 75.00)],
    },
    {
        "name": "bq-pmid-c204-stub",
        "net": "BQ_PMID",
        "layer": "F.Cu",
        "width": 0.60,
        "points": [(44.93, 77.00), (44.93, 75.00)],
    },
    {
        "name": "bq-pmid-c213-bus-via-fanout",
        "net": "BQ_PMID",
        "layer": "F.Cu",
        "width": 0.20,
        "points": [(33.73, 75.00), (32.60, 75.00)],
    },
    {
        "name": "bq-pmid-c213-bottom-jog",
        "net": "BQ_PMID",
        "layer": "B.Cu",
        "width": 0.20,
        "points": [(32.60, 75.00), (27.60, 75.00), (27.60, 85.80)],
    },
    {
        "name": "bq-pmid-c213-pad-fanout",
        "net": "BQ_PMID",
        "layer": "F.Cu",
        "width": 0.20,
        "points": [(27.60, 85.80), (28.83, 85.00)],
    },
    {
        "name": "bq-pmid-u1-lower-escape-f",
        "net": "BQ_PMID",
        "layer": "F.Cu",
        "width": 0.15,
        "points": [(64.10, 73.275), (64.00, 72.45)],
    },
    {
        "name": "bq-pmid-inner-route-f",
        "net": "BQ_PMID",
        "layer": "B.Cu",
        "width": 0.30,
        "points": [(64.00, 72.45), (64.00, 71.50), (45.50, 71.50)],
    },
    {
        "name": "bq-pmid-capbus-entry-f",
        "net": "BQ_PMID",
        "layer": "F.Cu",
        "width": 0.25,
        "points": [(45.50, 71.50), (45.50, 75.00), (44.93, 75.00)],
    },
    {
        "name": "bq-sys-cap-bank-bus",
        "net": "BQ_SYS",
        "layer": "F.Cu",
        "width": 0.60,
        "points": [(22.53, 83.40), (28.13, 83.40), (33.73, 83.40), (39.33, 83.40)],
    },
    {
        "name": "bq-sys-c206-stub",
        "net": "BQ_SYS",
        "layer": "F.Cu",
        "width": 0.60,
        "points": [(22.53, 81.00), (22.53, 83.40)],
    },
    {
        "name": "bq-sys-c207-stub",
        "net": "BQ_SYS",
        "layer": "F.Cu",
        "width": 0.60,
        "points": [(28.13, 81.00), (28.13, 83.40)],
    },
    {
        "name": "bq-sys-c208-stub",
        "net": "BQ_SYS",
        "layer": "F.Cu",
        "width": 0.60,
        "points": [(33.73, 81.00), (33.73, 83.40)],
    },
    {
        "name": "bq-sys-c209-stub",
        "net": "BQ_SYS",
        "layer": "F.Cu",
        "width": 0.60,
        "points": [(39.33, 81.00), (39.33, 83.40)],
    },
    {
        "name": "bq-sys-c214-stub",
        "net": "BQ_SYS",
        "layer": "F.Cu",
        "width": 0.60,
        "points": [(34.43, 85.00), (34.43, 83.40)],
    },
    {
        "name": "bq-sys-c205-bus-via-fanout",
        "net": "BQ_SYS",
        "layer": "F.Cu",
        "width": 0.30,
        "points": [(39.33, 83.40), (40.50, 83.40)],
    },
    {
        "name": "bq-sys-c205-bottom-jog",
        "net": "BQ_SYS",
        "layer": "B.Cu",
        "width": 0.30,
        "points": [(40.50, 83.40), (40.50, 79.00), (50.00, 79.00), (50.00, 77.80)],
    },
    {
        "name": "bq-sys-c205-pad-fanout",
        "net": "BQ_SYS",
        "layer": "F.Cu",
        "width": 0.30,
        "points": [(50.00, 77.80), (50.53, 77.00)],
    },
    {
        "name": "bq-sys-cap-bank-to-u1-b",
        "net": "BQ_SYS",
        "layer": "In1.Cu",
        "width": 0.40,
        "points": [(50.00, 77.80), (54.80, 77.80), (54.80, 70.50), (66.35, 70.50)],
    },
    {
        "name": "bq-sys-u1-entry-b",
        "net": "BQ_SYS",
        "layer": "F.Cu",
        "width": 0.25,
        "points": [(66.35, 70.50), (66.35, 72.20), (65.90, 72.80)],
    },
    {
        "name": "bq-sys-l2-fanout-to-spine-b",
        "net": "BQ_SYS",
        "layer": "F.Cu",
        "width": 0.60,
        "points": [(68.86, 55.00), (70.50, 55.00)],
    },
    {
        "name": "bq-sys-l2-to-u1-spine-b",
        "net": "BQ_SYS",
        "layer": "In2.Cu",
        "width": 0.60,
        "points": [(70.50, 55.00), (70.50, 70.50), (66.35, 70.50)],
    },
    {
        "name": "bq-sys-u3-vin-fanout-b",
        "net": "BQ_SYS",
        "layer": "F.Cu",
        "width": 0.30,
        "points": [(60.65, 53.25), (61.20, 53.25), (61.20, 52.90)],
    },
    {
        "name": "bq-sys-u3-to-l2-spine-b",
        "net": "BQ_SYS",
        "layer": "In1.Cu",
        "width": 0.50,
        "points": [(61.20, 52.90), (70.50, 52.90), (70.50, 55.00)],
    },
    {
        "name": "bat-raw-cap-bank-bus",
        "net": "BAT_RAW",
        "layer": "F.Cu",
        "width": 0.60,
        "points": [(44.93, 83.40), (50.53, 83.40)],
    },
    {
        "name": "bat-raw-c210-stub",
        "net": "BAT_RAW",
        "layer": "F.Cu",
        "width": 0.60,
        "points": [(44.93, 81.00), (44.93, 83.40)],
    },
    {
        "name": "bat-raw-c211-stub",
        "net": "BAT_RAW",
        "layer": "F.Cu",
        "width": 0.60,
        "points": [(50.53, 81.00), (50.53, 83.40)],
    },
    {
        "name": "bat-raw-r202-to-cap-bus-branch",
        "net": "BAT_RAW",
        "layer": "F.Cu",
        "width": 0.25,
        "points": [(39.98, 89.00), (39.98, 88.00), (43.80, 88.00), (43.80, 83.40), (44.93, 83.40)],
    },
    {
        "name": "boost-input-c400-c401-local-bus",
        "net": "BQ_SYS",
        "layer": "F.Cu",
        "width": 0.40,
        "points": [(68.53, 62.80), (68.53, 66.60)],
    },
    {
        "name": "boost-input-c404-top-edge-bridge",
        "net": "BQ_SYS",
        "layer": "F.Cu",
        "width": 0.25,
        "points": [(68.86, 55.00), (68.86, 60.20), (70.73, 60.20)],
    },
    {
        "name": "boost-input-c404-pad-fanout",
        "net": "BQ_SYS",
        "layer": "F.Cu",
        "width": 0.30,
        "points": [(70.73, 60.20), (68.53, 62.80)],
    },
    {
        "name": "boost-output-c402-c403-local-bus",
        "net": "5V_RADIO",
        "layer": "F.Cu",
        "width": 0.40,
        "points": [(34.23, 24.50), (34.23, 22.50), (39.83, 22.50), (39.83, 24.50)],
    },
    {
        "name": "boost-output-r400-sense-to-cap-bus",
        "net": "5V_RADIO",
        "layer": "F.Cu",
        "width": 0.20,
        "points": [(39.83, 24.50), (39.83, 26.60), (40.48, 26.60), (40.48, 29.00)],
    },
    {
        "name": "charge-led-k-local",
        "net": "CHG_LED_K",
        "layer": "F.Cu",
        "width": 0.20,
        "points": [(35.99, 93.00), (39.98, 93.00)],
    },
    {
        "name": "d1-3v3-fanout",
        "net": "3V3",
        "layer": "F.Cu",
        "width": 0.15,
        "points": [(34.41, 93.00), (33.50, 93.00), (33.50, 91.50)],
    },
    {
        "name": "d1-3v3-internal-route",
        "net": "3V3",
        "layer": "In2.Cu",
        "width": 0.15,
        "points": [(33.50, 91.50), (100.00, 91.50), (100.00, 69.00)],
    },
    {
        "name": "bq-stat-r207-fanout",
        "net": "BQ_STAT",
        "layer": "F.Cu",
        "width": 0.20,
        "points": [(41.62, 93.00), (42.60, 93.00)],
    },
    {
        "name": "bq-stat-backbone",
        "net": "BQ_STAT",
        "layer": "In2.Cu",
        "width": 0.20,
        "points": [(42.60, 93.00), (42.60, 95.00), (16.00, 95.00), (16.00, 72.50), (62.40, 72.50), (62.40, 73.40)],
    },
    {
        "name": "bq-stat-u1-entry",
        "net": "BQ_STAT",
        "layer": "F.Cu",
        "width": 0.15,
        "points": [(62.40, 73.40), (63.10, 73.40)],
    },
    {
        "name": "bq-btst1-c216-local",
        "net": "BQ_BTST1",
        "layer": "F.Cu",
        "width": 0.15,
        "points": [(63.10, 74.60), (61.20, 74.60), (61.20, 70.50), (62.33, 70.50)],
    },
    {
        "name": "bq-btst2-u1-to-c217-k",
        "net": "BQ_BTST2",
        "layer": "F.Cu",
        "width": 0.15,
        "points": [(66.86, 75.40), (68.56, 75.40), (68.56, 78.60), (72.03, 78.60), (72.03, 82.00)],
    },
    {
        "name": "bq-sw1-c216-local",
        "net": "BQ_SW1",
        "layer": "F.Cu",
        "width": 0.20,
        "points": [(64.55, 73.30), (64.55, 70.50), (63.88, 70.50)],
    },
    {
        "name": "bq-sw1-c216-to-l1-left-wrap-e",
        "net": "BQ_SW1",
        "layer": "F.Cu",
        "width": 0.35,
        "points": [(64.55, 70.50), (64.55, 69.45), (59.00, 69.45), (59.00, 84.00), (62.59, 84.00)],
    },
    {
        "name": "bq-sw2-l1-c217-local-b",
        "net": "BQ_SW2",
        "layer": "F.Cu",
        "width": 0.40,
        "points": [(73.58, 82.00), (75.20, 82.00), (75.20, 84.00), (67.41, 84.00)],
    },
    {
        "name": "bq-sw2-u1-to-l1-lower-u",
        "net": "BQ_SW2",
        "layer": "F.Cu",
        "width": 0.25,
        "points": [(65.45, 73.30), (65.45, 69.30), (71.60, 69.30), (71.60, 70.80), (72.80, 70.80), (72.80, 83.20), (67.41, 83.20), (67.41, 84.00)],
    },
    {
        "name": "bq-ts-divider-local",
        "net": "BQ_TS",
        "layer": "F.Cu",
        "width": 0.20,
        "points": [(30.43, 89.00), (34.38, 89.00)],
    },
    {
        "name": "bq-ts-bottom-route",
        "net": "BQ_TS",
        "layer": "In2.Cu",
        "width": 0.20,
        "points": [(34.38, 87.80), (68.00, 87.80), (68.00, 76.60)],
    },
    {
        "name": "bq-ts-divider-via-fanout",
        "net": "BQ_TS",
        "layer": "F.Cu",
        "width": 0.20,
        "points": [(34.38, 89.00), (34.38, 87.80)],
    },
    {
        "name": "bq-ts-u1-fanout",
        "net": "BQ_TS",
        "layer": "F.Cu",
        "width": 0.15,
        "points": [(68.00, 76.60), (66.85, 76.60)],
    },
    {
        "name": "batp-kelvin-u1-fanout-e",
        "net": "BATP_KELVIN",
        "layer": "F.Cu",
        "width": 0.15,
        "points": [(66.875, 75.80), (67.75, 75.80), (67.75, 75.90)],
    },
    {
        "name": "batp-kelvin-bottom-escape-e",
        "net": "BATP_KELVIN",
        "layer": "B.Cu",
        "width": 0.15,
        "points": [(67.75, 75.90), (67.75, 76.05), (69.00, 76.05), (69.00, 81.30), (52.00, 81.30), (52.00, 80.20), (49.00, 80.20)],
    },
    {
        "name": "batp-kelvin-inner-route-e",
        "net": "BATP_KELVIN",
        "layer": "In2.Cu",
        "width": 0.15,
        "points": [(49.00, 80.20), (33.00, 80.20), (33.00, 90.50), (42.45, 90.50)],
    },
    {
        "name": "batp-kelvin-r202-fanout-e",
        "net": "BATP_KELVIN",
        "layer": "F.Cu",
        "width": 0.15,
        "points": [(42.45, 90.50), (42.45, 89.00), (41.625, 89.00)],
    },
    {
        "name": "bq-sdrv-c218-local",
        "net": "BQ_SDRV",
        "layer": "F.Cu",
        "width": 0.15,
        "points": [(66.86, 73.40), (68.42, 73.40), (68.42, 71.20)],
    },
    {
        "name": "bq-regn-r200-c215-local-link",
        "net": "BQ_REGN",
        "layer": "F.Cu",
        "width": 0.20,
        "points": [(28.78, 89.00), (28.78, 87.10), (39.85, 87.10), (39.85, 85.00)],
    },
    {
        "name": "bq-regn-c215-u1-pad5-fanout-a",
        "net": "BQ_REGN",
        "layer": "F.Cu",
        "width": 0.15,
        "points": [(63.10, 75.00), (62.10, 75.00), (62.10, 76.00), (60.80, 76.00)],
    },
    {
        "name": "bq-regn-c215-u1-route-a",
        "net": "BQ_REGN",
        "layer": "B.Cu",
        "width": 0.20,
        "points": [(60.80, 76.00), (39.85, 76.00), (39.85, 85.00)],
    },
    {
        "name": "bq-regn-ilim-top-bridge-b",
        "net": "BQ_REGN",
        "layer": "F.Cu",
        "width": 0.15,
        "points": [(66.85, 76.20), (65.85, 76.20), (65.85, 75.60), (63.80, 75.60), (63.80, 75.00), (63.10, 75.00)],
    },
    {
        "name": "uv-divider-local",
        "net": "UV_NODE",
        "layer": "F.Cu",
        "width": 0.20,
        "points": [(69.03, 45.20), (70.78, 45.20)],
    },
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

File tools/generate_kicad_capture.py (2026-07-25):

#!/usr/bin/env python3
"""Generate the first RoyalNode KiCad schematic capture from the pin seed.

This is intentionally a capture scaffold, not a finished schematic. It places
the project-local symbols and attaches deterministic global labels from the
CSV pin map so reviewers can inspect the electrical intent inside KiCad.
"""

from __future__ import annotations

import csv
import re
import uuid
from collections import defaultdict
from pathlib import Path

ROOT = Path(__file__).resolve().parents[1]
KICAD_DIR = ROOT / "hardware/kicad/RoyalNode"
SEED = KICAD_DIR / "SCHEMATIC_CAPTURE_SEED_REV_A.csv"
PASSIVE_SEED = KICAD_DIR / "PASSIVE_CAPTURE_SEED_REV_A.csv"
SYMBOL_LIB = KICAD_DIR / "lib_symbols/RoyalNode.kicad_sym"
SCHEMATIC = KICAD_DIR / "RoyalNode.kicad_sch"

NAMESPACE = uuid.UUID("8cf8a6b7-5ff4-40ed-b9a3-bca28c567834")
WIRE_STUB_MM = 7.62

SYMBOL_MAP = {
    "MOD1": ("RoyalNode:RN_XIAO_nRF52840_SOCKET", "XIAO nRF52840", (55.88, 66.04)),
    "MOD2": ("RoyalNode:RN_E22_900M33S", "E22-900M33S", (55.88, 127.00)),
    "U1": ("RoyalNode:RN_BQ25798RQMR", "BQ25798RQMR", (149.86, 69.85)),
    "U2": ("RoyalNode:RN_LM66100DCKR", "LM66100DCKR", (248.92, 41.91)),
    "U3": ("RoyalNode:RN_TPS61088RHLR", "TPS61088RHLR", (248.92, 97.79)),
    "U4": ("RoyalNode:RN_LTC4365ITS8_1", "LTC4365ITS8-1", (149.86, 137.16)),
    "Q1": ("RoyalNode:RN_ISA170170N04LMDS", "ISA170170N04LMDS", (248.92, 149.86)),
    "Q2": ("RoyalNode:RN_ISA170170N04LMDS", "ISA170170N04LMDS", (248.92, 195.58)),
    "Q3": ("RoyalNode:RN_ISA170170N04LMDS", "ISA170170N04LMDS", (248.92, 241.30)),
    "J1": ("RoyalNode:RN_XT30PW_M", "XT30PW-M SOLAR", (55.88, 204.47)),
    "J2": ("RoyalNode:RN_XT30PW_M", "XT30PW-M BATTERY", (55.88, 233.68)),
    "J3": ("RoyalNode:RN_JST_GH_2", "JST-GH XIAO BAT HARNESS", (149.86, 204.47)),
    "J4": ("RoyalNode:RN_JST_GH_2", "JST-GH BATTERY NTC", (149.86, 233.68)),
    "J5": ("RoyalNode:RN_SMA_EDGE", "Molex 0732511150 SMA", (55.88, 266.70)),
    "J6": ("RoyalNode:RN_JST_GH_4", "JST-GH BME680 I2C", (149.86, 266.70)),
    "F1": ("RoyalNode:RN_TWO_PIN_POWER_PART", "Littelfuse 0483005.DR", (55.88, 184.15)),
    "L1": ("RoyalNode:RN_TWO_PIN_POWER_PART", "Coilcraft XAL7070-222MEC", (149.86, 170.18)),
    "L2": ("RoyalNode:RN_TWO_PIN_POWER_PART", "Coilcraft XAL7030-222MEC", (248.92, 124.46)),
}

FOOTPRINT_MAP = {
    "MOD1": "RoyalNode:MOD1_XIAO_NRF52840_SOCKET_C53202181_RC",
    "MOD2": "RoyalNode:MOD2_E22_900M33S_JLC_C22399506_RC",
    "U1": "RoyalNode:U1_BQ25798_RQM0029A_RC",
    "U2": "RoyalNode:U2_LM66100_DCK0006A_SC70_6_RC",
    "U3": "RoyalNode:U3_TPS61088_RHL0020A_THERMALVIAS_RC",
    "U4": "RoyalNode:U4_LTC4365_TSOT23_8_RC",
    "Q1": "RoyalNode:Q_POWER_INFINEON_PG_DSO_8_27_RC",
    "Q2": "RoyalNode:Q_POWER_INFINEON_PG_DSO_8_27_RC",
    "Q3": "RoyalNode:Q_POWER_INFINEON_PG_DSO_8_27_RC",
    "J1": "RoyalNode:J_POWER_XT30PW_M_C431092_RC",
    "J2": "RoyalNode:J_POWER_XT30PW_M_C431092_RC",
    "J3": "RoyalNode:J_LOW_JST_GH_SM02B_GHS_TB_RC",
    "J4": "RoyalNode:J_LOW_JST_GH_SM02B_GHS_TB_RC",
    "J6": "RoyalNode:J_LOW_JST_GH_SM04B_GHS_TB_RC",
    "F1": "RoyalNode:F1_LITTELFUSE_483_1206_RC",
    "L1": "RoyalNode:L1_COILCRAFT_XAL7070_222MEC_RC",
    "L2": "RoyalNode:L2_COILCRAFT_XAL7030_222MEC_RC",
}

CAPTURED_ORDER = [
    "MOD1",
    "MOD2",
    "U1",
    "U2",
    "U3",
    "U4",
    "Q1",
    "Q2",
    "Q3",
    "J1",
    "J2",
    "J3",
    "J4",
    "J5",
    "J6",
    "F1",
    "L1",
    "L2",
]

PASSIVE_SYMBOL = "RoyalNode:RN_TWO_PIN_POWER_PART"
PWR_FLAG_SYMBOL = "RoyalNode:RN_PWR_FLAG"
PWR_FLAGS = [
    ("PF1", "GND", (15.24, 241.30)),
    ("PF2", "USB_VBUS_RAW", (15.24, 248.92)),
    ("PF3", "SOLAR_FUSED", (15.24, 256.54)),
    ("PF4", "SOLAR_PROTECTED", (15.24, 264.16)),
    ("PF5", "BAT_RAW", (15.24, 271.78)),
    ("PF6", "BQ_VBUS", (15.24, 279.40)),
]


def stable_uuid(*parts: str) -> str:
    return str(uuid.uuid5(NAMESPACE, "::".join(parts)))


def quote(text: str) -> str:
    return text.replace("\\", "\\\\").replace('"', '\\"')


def parse_pin_blocks(symbol_name: str, lib_text: str) -> dict[str, tuple[float, float, int]]:
    start = lib_text.find(f'  (symbol "{symbol_name}"')
    if start < 0:
        raise SystemExit(f"missing symbol {symbol_name}")
    end = lib_text.find("\n  (symbol \"", start + 1)
    if end < 0:
        end = len(lib_text)
    block = lib_text[start:end]

    pins: dict[str, tuple[float, float, int]] = {}
    lines = block.splitlines()
    i = 0
    while i < len(lines):
        if "(pin " not in lines[i]:
            i += 1
            continue
        pin_lines = [lines[i]]
        depth = lines[i].count("(") - lines[i].count(")")
        i += 1
        while i < len(lines) and depth > 0:
            pin_lines.append(lines[i])
            depth += lines[i].count("(") - lines[i].count(")")
            i += 1
        pin_block = "\n".join(pin_lines)
        at = re.search(r"\(at\s+([-0-9.]+)\s+([-0-9.]+)\s+([-0-9.]+)\)", pin_block)
        number = re.search(r'\(number\s+"([^"]+)"', pin_block)
        if at and number:
            pins[number.group(1)] = (float(at.group(1)), float(at.group(2)), int(float(at.group(3))))
    return pins


def top_level_symbol_block(symbol_name: str, lib_text: str) -> str:
    start = lib_text.find(f'  (symbol "{symbol_name}"')
    if start < 0:
        raise SystemExit(f"missing symbol {symbol_name}")
    end = lib_text.find("\n  (symbol \"", start + 1)
    if end < 0:
        end = lib_text.rfind("\n)")
    block = lib_text[start:end].rstrip()
    return block.replace(f'(symbol "{symbol_name}"', f'(symbol "RoyalNode:{symbol_name}"', 1)


def symbol_short_name(lib_id: str) -> str:
    return lib_id.split(":", 1)[1]


def label_endpoint(symbol_x: float, symbol_y: float, pin_x: float, pin_y: float) -> tuple[float, float, int]:
    abs_x = symbol_x + pin_x
    abs_y = symbol_y - pin_y
    if pin_x <= 0:
        return abs_x - WIRE_STUB_MM, abs_y, 180
    return abs_x + WIRE_STUB_MM, abs_y, 0


def wire_for_pin(ref: str, pin: str, symbol_x: float, symbol_y: float, pin_x: float, pin_y: float) -> str:
    pin_abs_x = symbol_x + pin_x
    pin_abs_y = symbol_y - pin_y
    label_x, label_y, _ = label_endpoint(symbol_x, symbol_y, pin_x, pin_y)
    return f'''  (wire
    (pts
      (xy {pin_abs_x:.2f} {pin_abs_y:.2f})
      (xy {label_x:.2f} {label_y:.2f})
    )
    (stroke
      (width 0)
      (type default)
    )
    (uuid "{stable_uuid("wire", ref, pin)}")
  )'''


def global_label(ref: str, pin: str, net: str, x: float, y: float, angle: int) -> str:
    return f'''  (global_label "{quote(net)}"
    (shape bidirectional)
    (at {x:.2f} {y:.2f} {angle})
    (fields_autoplaced yes)
    (effects
      (font
        (size 1.27 1.27)
      )
      (justify left)
    )
    (uuid "{stable_uuid("label", ref, pin, net)}")
    (property "Intersheetrefs" "${{INTERSHEET_REFS}}"
      (at {x:.2f} {y:.2f} {angle})
      (effects
        (font
          (size 1.27 1.27)
        )
        (hide yes)
      )
    )
  )'''
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

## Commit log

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2026-07-19 Replace pogo access with wired JST harness and remove battery NTC
2026-07-19 Remove battery temperature circuit and replace pogo contacts with wired JST harness
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2026-07-21 Lock Rev A fixed TS simulation policy and advance static pin review
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2026-07-23 Replace low-stock NTC connector with stocked -40C CJT connector
2026-07-24 Start KiCad Rev A project scaffold
    [RoyalNode.kicad_pcb, RoyalNode.kicad_sch]
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2026-07-24 Add current Rev A locked BOM seeds
    [REV_A_LOCKED_CORE_BOM.csv, REV_A_LOCKED_PASSIVES.csv]
2026-07-24 Add Rev A capture seed and validation workflow
    [SCHEMATIC_CAPTURE_SEED_REV_A.csv]
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2026-07-25 Generate initial Rev A schematic capture
    [RoyalNode.kicad_sch]
2026-07-25 Expand generated schematic to ERC clean capture
    [PASSIVE_CAPTURE_SEED_REV_A.csv, RoyalNode.kicad_sch, SCHEMATIC_CAPTURE_SEED_REV_A.csv]
2026-07-25 Add generated PCB placement scaffold
    [RoyalNode.kicad_pcb]
2026-07-25 Promote connector placement footprints
    [RoyalNode.kicad_pcb]
2026-07-25 Add power-stage placement candidates
    [RoyalNode.kicad_pcb]
2026-07-25 Assign major schematic footprints
    [RoyalNode.kicad_sch]
2026-07-25 Assign passive schematic footprints
    [PASSIVE_CAPTURE_SEED_REV_A.csv, RoyalNode.kicad_sch]
2026-07-25 Add PCB net annotations
    [RoyalNode.kicad_pcb]
2026-07-25 Stage passive PCB footprints
    [RoyalNode.kicad_pcb]
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2026-07-25 Standardize low-current connectors on JST-GH
    [REV_A_LOCKED_CORE_BOM.csv, RoyalNode.kicad_pcb, RoyalNode.kicad_sch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]
2026-07-25 Assign solar fuse footprint
    [RoyalNode.kicad_pcb, RoyalNode.kicad_sch]
2026-07-25 Assign E22 bulk capacitor footprint
    [PASSIVE_CAPTURE_SEED_REV_A.csv, RoyalNode.kicad_pcb, RoyalNode.kicad_sch]
2026-07-25 Mark battery thermistor off-board
    [RoyalNode.kicad_sch]
2026-07-25 Add optional BME680 I2C connector
    [REV_A_LOCKED_CORE_BOM.csv, RoyalNode.kicad_pcb, RoyalNode.kicad_sch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]
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2026-07-25 Shift XIAO socket above RF corridor
    [RoyalNode.kicad_pcb]
2026-07-25 Route initial low-current nets
    [RoyalNode.kicad_pcb]
2026-07-25 Add L2 ground reference plane
    [RoyalNode.kicad_pcb]
2026-07-25 Route E22 control nets
    [RoyalNode.kicad_pcb]
2026-07-25 Route E22 SPI nets
    [RoyalNode.kicad_pcb]
2026-07-25 Route optional sensor I2C nets
    [RoyalNode.kicad_pcb]
2026-07-25 Route charger I2C bus
    [RoyalNode.kicad_pcb]
2026-07-25 Document boost enable routing blocker
    [RoyalNode.kicad_pcb]
2026-07-25 Stabilize generated footprint UUIDs
    [RoyalNode.kicad_pcb]
2026-07-25 Retire abandoned boost enable trial route
    [RoyalNode.kicad_pcb]
2026-07-25 Add KiCad report gate
    [RoyalNode.kicad_pcb]
2026-07-25 Route charge LED cathode link
    [RoyalNode.kicad_pcb]
2026-07-25 Route charger status LED net
    [RoyalNode.kicad_pcb]
2026-07-25 Route temperature divider link
    [RoyalNode.kicad_pcb]
2026-07-25 Route UV divider link
    [RoyalNode.kicad_pcb]
2026-07-25 Route OV divider link
    [RoyalNode.kicad_pcb]
2026-07-25 Route U2 local ties
    [RoyalNode.kicad_pcb]
2026-07-25 Route MOSFET gate ties
    [RoyalNode.kicad_pcb]
2026-07-25 Route U1 local duplicate pins
    [RoyalNode.kicad_pcb]
2026-07-25 Route MOSFET local drain ties
    [RoyalNode.kicad_pcb]
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2026-07-25 Route E22 local VCC tie
    [RoyalNode.kicad_pcb]
2026-07-25 Route TPS61088 local output pins
    [RoyalNode.kicad_pcb]
2026-07-25 Route TPS61088 local switch pins
    [RoyalNode.kicad_pcb]
2026-07-25 Align solar input for 6V panel
    [PASSIVE_CAPTURE_SEED_REV_A.csv, REV_A_LOCKED_CORE_BOM.csv, REV_A_LOCKED_PASSIVES.csv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]
2026-07-25 Guard 6V solar configuration
    [RoyalNode.kicad_pcb]
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2026-07-25 Retire failed BOOST_EN placement trial
    [RoyalNode.kicad_pcb]
2026-07-25 Retire failed BQ25798 TS placement trial
    [RoyalNode.kicad_pcb]
2026-07-25 Rotate boost power stage topology
    [RoyalNode.kicad_pcb]
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2026-07-25 Lock passive footprint packages
    [REV_A_LOCKED_PASSIVES.csv]
2026-07-25 Lock charge LED sourcing
    [PASSIVE_CAPTURE_SEED_REV_A.csv, REV_A_LOCKED_CORE_BOM.csv, RoyalNode.kicad_pcb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]
2026-07-25 Sync locked resistor sourcing
    [REV_A_LOCKED_PASSIVES.csv]
2026-07-25 Add E22 high frequency bypass caps
    [PASSIVE_CAPTURE_SEED_REV_A.csv, REV_A_LOCKED_PASSIVES.csv, RoyalNode.kicad_pcb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]
2026-07-25 Align passive seed with locked BOM
    [PASSIVE_CAPTURE_SEED_REV_A.csv, REV_A_LOCKED_PASSIVES.csv, RoyalNode.kicad_pcb]
2026-07-25 Lock TPS61088 support capacitors
    [REV_A_LOCKED_PASSIVES.csv]
2026-07-25 Lock input protection divider resistors
    [REV_A_LOCKED_PASSIVES.csv]
2026-07-25 Add generated top ground fill
    [RoyalNode.kicad_pcb]
2026-07-25 Refresh generated PCB after ground fill
    [RoyalNode.kicad_pcb]
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2026-07-25 Normalize KiCad filled zones
    [RoyalNode.kicad_pcb]
2026-07-25 Reposition JST service connectors
    [RoyalNode.kicad_pcb]
2026-07-25 Route XIAO I2C bus entry
    [RoyalNode.kicad_pcb]
2026-07-25 Retire rejected BQ signal route trial
    [RoyalNode.kicad_pcb]
2026-07-25 Route charger PROG and INT locally
    [RoyalNode.kicad_pcb]
2026-07-25 Route J6 I2C signal escape
    [RoyalNode.kicad_pcb]
2026-07-25 Route J6 3V3 service feed
    [RoyalNode.kicad_pcb]
2026-07-25 Document rejected TPS61088 FB trials
    [RoyalNode.kicad_pcb]
2026-07-25 Route J3 XIAO battery harness
    [RoyalNode.kicad_pcb]
2026-07-25 Route battery NTC sense line
    [RoyalNode.kicad_pcb]
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2026-07-26 Retire rejected BQ SYS boost input corridor trial
    [RoyalNode.kicad_pcb]
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2026-07-26 Move R204 3V3 feed off U1 top corridor
    [RoyalNode.kicad_pcb]
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
